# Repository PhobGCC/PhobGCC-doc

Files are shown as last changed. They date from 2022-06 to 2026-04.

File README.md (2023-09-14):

# PhobGCC Documentation Hub
This is a central location for documentation for the PhobGCC.

The PhobGCC is a replacement motherboard for Gamecube controllers that reads stick position using magnets and Hall effect sensors instead of potentiometers that can wear out.
It offers an advanced digital snapback filter that doesn't reduce responsiveness and actually improves responsiveness in Melee.
It also features gate calibration, swappable buttons, and facilitates installation of discrete switches on the D-pad and face buttons.

This comes together to make a high-performance, customizable, long-lasting controller that you can make yourself.

Come chat with us on the [PhobGCC Discord](https://discord.gg/eNJ7xWMvxf)!

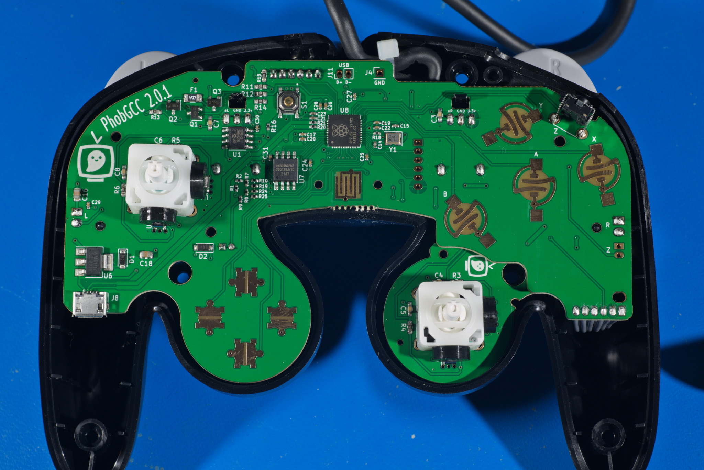
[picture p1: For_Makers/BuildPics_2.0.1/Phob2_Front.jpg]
PhobGCC


## For Buyers and Users

[PhobGCC Buying Guide](/For_Users/Phob_Buying_Guide.md)

[PhobGCC Calibration/Configuration Guide](/For_Users/Phob_Calibration_Guide_Latest.md)

[PhobVision and PhobScope User Guide](/For_Users/Phobvision_Guide_Latest.md)

[PhobGCC v2.0 Firmware Update Guide](/For_Users/Phob2_Programming_Guide.md)

[PhobGCC v1.X Firmware Update Guide](/For_Users/Phob_Programming_Guide.md)

[User guides for Extras](/For_Users/Extras_Guides)

## For Makers and Sellers

[PhobGCC v2.0.5 Parts Ordering Guide](/For_Makers/Phob2_Ordering_Guide.md)

[Build Guide for PhobGCC 2.0](/For_Makers/Build_Guide_2.0.md)

[Build Video for PhobGCC 2.0](https://www.youtube.com/watch?v=hWuvy4ZEgG0)

[Board Fixes for PhobGCC design flaws](/For_Makers/Board_Fixes.md)

[PhobGCC v1.2.3 Parts Ordering Guide](/For_Makers/Phob_Ordering_Guide.md)

[Build Video for PhobGCC 1.2](https://youtu.be/0QmgswFa1cA)

[Build Guide for PhobGCC 1.2](/For_Makers/Build_Guide_1.2.md)

[Board Debugging for PhobGCC 1.2](/For_Makers/Board_Level_Debugging_1.2.md) (read before plugging in the first time!)

[Guide to Programming PhobGCC v2.0](/For_Users/Phob2_Programming_Guide.md)

[Guide to Programming PhobGCC v1.X](/For_Users/Phob_Programming_Guide.md)

## General Info

[Hall Effect Sensor Explanation](/General_Info/Hall_Effect_Sensors.md)

[Signal Linearization](/General_Info/Signal_Linearization.md)

[Snapback Filter](/General_Info/Snapback_Filter.md)

[Notch Remapping](/General_Info/Notch_Remapping.md)

## Legacy Info

[Legacy Documentation Page](/LEGACY.md)


This work is licensed under a [Creative Commons Attribution-ShareAlike 4.0 International License](http://creativecommons.org/licenses/by-sa/4.0/).

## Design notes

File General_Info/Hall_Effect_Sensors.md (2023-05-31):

Hall effect sensors work by measuring how hard moving charges get pushed/pulled by a magnetic field. Read more here: https://en.wikipedia.org/wiki/Hall_effect

We can use this effect by attaching a magnet to the stickbox peg in the correct orientation, and placing a sensor underneath it. When the magnetic field is perpendicular to the sensor's direction of sensitivity, no field is detected and the sensor will output ~1V:

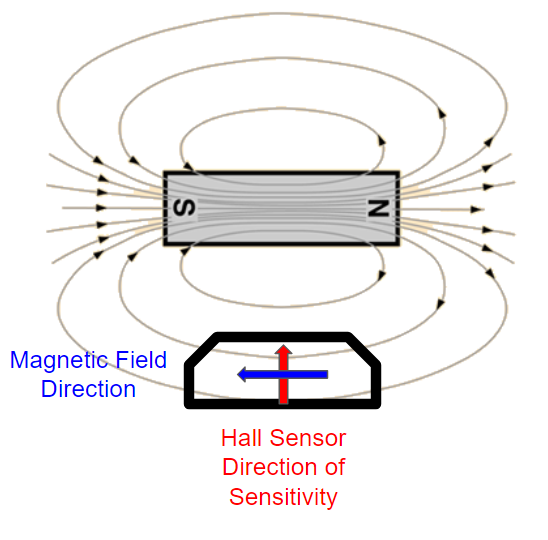
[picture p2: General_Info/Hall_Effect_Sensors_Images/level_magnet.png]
Magnet level


When the field tilts one way, the output voltage will decrease:
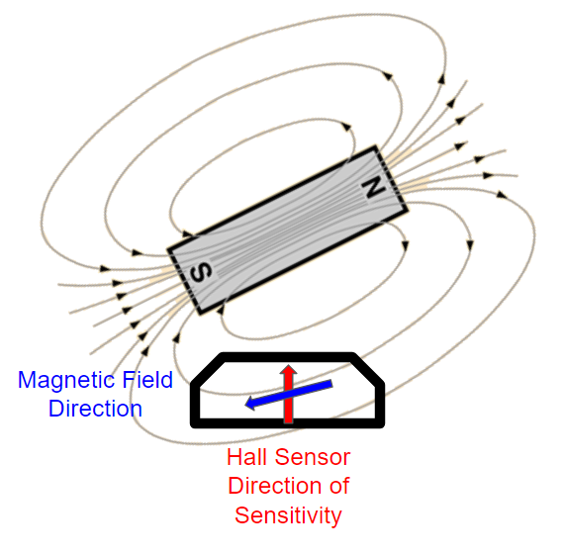
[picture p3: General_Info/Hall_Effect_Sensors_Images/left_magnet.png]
Magnet tilted left


When the field tilts the other way, the output voltage will increase:
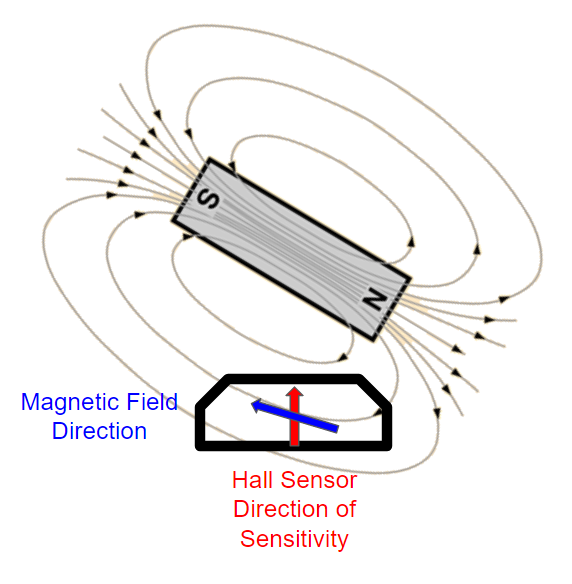
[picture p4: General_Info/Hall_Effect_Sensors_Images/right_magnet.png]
Magnet tilted right


When we glue the magnets on they are not perfectly aligned, so we won't get this perfect behavior, but this is roughly what happens. The microcontroller reads these voltages the same way it does from a potentiometer, but we will need to scale possibly linearize the signal before it can be used to control the stick. The primary advantage is that the Hall effect sensor will not wear out like a potentiometer will. As long as the magnet stays in place it will continue working.


This work is licensed under a [Creative Commons Attribution-ShareAlike 4.0 International License](http://creativecommons.org/licenses/by-sa/4.0/).

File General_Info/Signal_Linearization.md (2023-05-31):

 The signals coming from the Hall effect sensors need to be scaled and are non-linear. In order to make them behave the same way potentiometers we need to linearize them. We do this with a 3rd order polynomial fit.

Imagine we move the stick into the 8 different gate notches and record the x-position at each location. We would expect to get the values -1.0,-0.71,0,0.71, and 1.0, depending on which notch we were in. But with the hall effect sensors we might get something else, we might get -0.63,-0.52,0.0,0.29, and 0.33 for example.

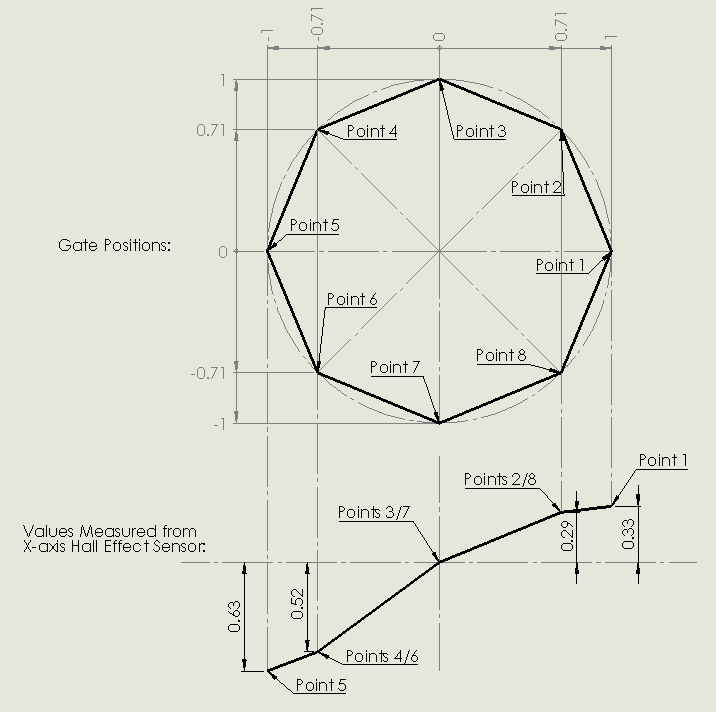
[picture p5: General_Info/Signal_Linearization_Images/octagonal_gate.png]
Octagonal Gate Measured Positions


 But since we know what the values should be, we can find an equation which transforms the values from the hall sensor into the values we want:

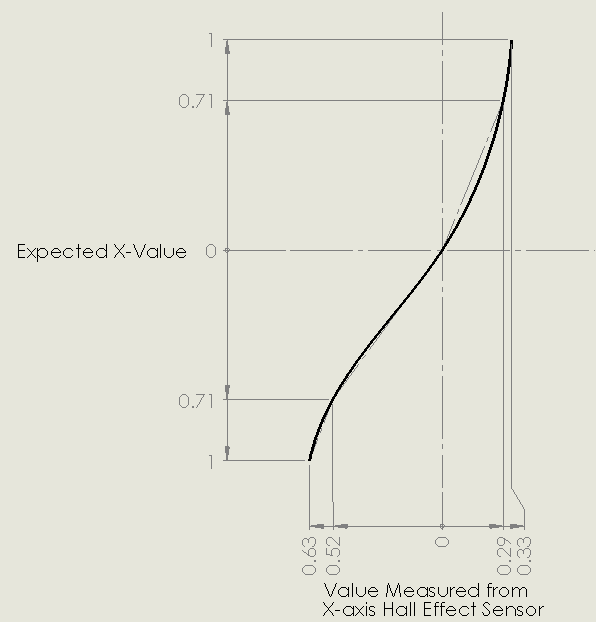
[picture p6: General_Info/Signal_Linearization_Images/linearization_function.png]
Linearization Function


The simplest function that appears to do a reasonable job of fitting the hall effect sensor data has been a 3rd order polynomial of the form Ax^3 + Bx^2 + Cx + D. Using these x-values measured at the gate notches we can find the coefficients A,B,C,D through regression analysis (usually ordinary least squares), then we just substitute the value we got from the sensor into x, and we get the linearized output.


This work is licensed under a [Creative Commons Attribution-ShareAlike 4.0 International License](http://creativecommons.org/licenses/by-sa/4.0/).

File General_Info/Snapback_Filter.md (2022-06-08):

# Kalman-inspired filter for snapback

For a thorough introduction to Kalman filters, check out this website: https://www.kalmanfilter.net/

Kalman filters are a common way to estimate current system state when all you have are noisy measurements. They use a model of the system's behavior to generate a prediction of the current state, and then blend that with measurements, while tracking uncertainty for both the measurements for the model. By choosing the right blend of measurement data and predictions from past data, they can generate estimates that are more accurate than the measurements alone.

In the PhobGCC, the measured stick positions have a slightly noisy signal, but it wouldn't be hard to get a good estimate of the actual stick position. The main issue is removal of unwanted snapback oscillations. Thus, we heavily modify the Kalman filter in order to exclude the measurements when we think the stick is undergoing snapback, and add other changes to improve behavior in other circumstances.

# Filter components

## Current position measurement

When determining the final estimated stick position, we weight the current measured position according to the minimum of the following:

1. To ensure that the stick responds quickly to full stick inputs, the first weight is the radius of the stick position to the 6th power. This stays very close to 0 and then it rises very suddenly near the edge. We can assume that snapback is not currently occurring when the stick is near the rim, because by definition it only occurs when the stick is released.
2. To ensure that the stick responds reasonably quickly to small stick inputs, the second weight is 1 when the stick is not moving or accelerating in that particular axis, and it gradually drops to 0 as the acceleration or velocity reach corresponding thresholds. The assumption here is that problematic amounts of snapback outside the deadzone will always have acceleration or velocity (or both) greater than these thresholds, while small manual stick movements will never be near these thresholds.

These cover both cases: a small input will always be slow compared to snapback, and any input near the rim, even if fast, will never be snapback.

## Prediction of future motion

The prediction based on past motion is weighted to be the complement of the current position measurement's weight.

However, the prediction based on past motion is not actually designed to be as accurate as possible. It's just an estimate of the *desired* velocity.

For one, we reduce the velocity estimate by a damping factor, which is a parameter you can adjust to tame snapback on particularly high-snapback controllers.

Secondly, the velocity estimate is itself a heavily filtered rendition of the current velocity.

* The current velocity is weighted according to the radius of the stick position squared, so that it is mostly ignored near the center (though less so than the stick position weight).
* The previous filtered velocity is weighted according to the complement of the current velocity's weight, but it has an additional decay factor to help prevent unwanted slow overshoots when returning to center.
* The disagreement between the previous measured stick position and the previous filtered stick position is lightly weighted into the filtered velocity in order to help improve responsiveness but not enough to cause overshooting.

# Results

For smash inputs, the PhobGCC analog stick filter ignores the initial part of the stick travel due to high speed/acceleration and not being near the gate, and then it "catches up". This results in a very short time interval where the filtered stick position is in the tilt region, which helps with the reliability of dashbacks, pivots, and wiggle out of tumble.

For small tilt outputs, the stick is still very responsive because humanly possible stick inputs can't approach the incredible speeds or accelerations characteristic of snapback. By closely following the stick when it is moving slowly, the PhobGCC maintains responsiveness for small inputs, which is useful for fast tilts, turnarounds, and slight DI.

Finally, when the stick is released, the high velocity and acceleration of the stick snapback cause the filter to drastically decrease the weight of the current stick position, allowing it to effectively ignore the oscillation and dampen the overshoot.

Thanks to this combination of characteristics, the PhobGCC analog stick filter achieves excellent responsiveness for *Melee* while taming snapback.

If you want to peruse the actual code for the filter, it is well-commented [here](https://github.com/PhobGCC/PhobGCC-SW/blob/843ff59011ab0bced795b43427e81f2a1a8c55f1/PhobGCC/PhobGCC.ino#L2636).


This work is licensed under a [Creative Commons Attribution-ShareAlike 4.0 International License](http://creativecommons.org/licenses/by-sa/4.0/).

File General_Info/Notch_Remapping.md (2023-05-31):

Notch remapping is done by dividing stick space into triangular shaped regions, then applying an affine transformation(https://brilliant.org/wiki/affine-transformations/) to each triangular shaped region to match up the corners of each region with the desired notches:

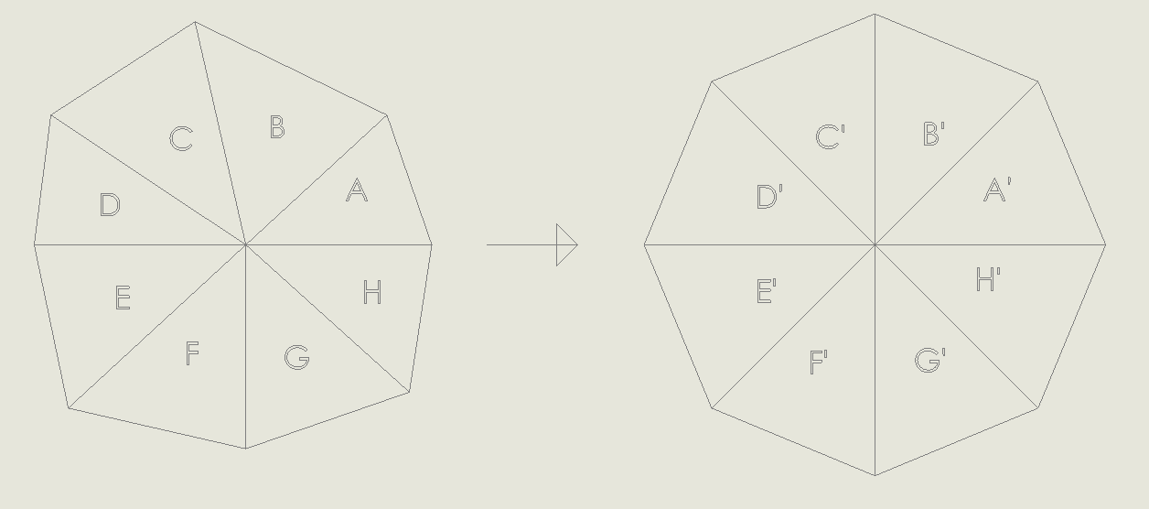
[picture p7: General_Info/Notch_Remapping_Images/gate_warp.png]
Remap


Region A gets transformed into region A', B into B', etc. This illustration is exaggerated to show how things work, the actual notch positions are not this far off. In this way things can be stretched so that when the stick is in the physical notch, it gives the correct coordinates.


This work is licensed under a [Creative Commons Attribution-ShareAlike 4.0 International License](http://creativecommons.org/licenses/by-sa/4.0/).

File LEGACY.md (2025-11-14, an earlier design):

# Legacy Documentation

This document is to keep track of old documentation that is no longer applicable.

## Controller Configuration

* [For Version 0.29](/For_Users/Phob_Calibration_Guide_v0.29.md)
* [For Version 0.28](/For_Users/Phob_Calibration_Guide_v0.28.md)
* [For Version 0.27](/For_Users/Phob_Calibration_Guide_v0.27.md)
* [For Version 0.26](/For_Users/Phob_Calibration_Guide_v0.26.md)
* [For Version 0.25](/For_Users/Phob_Calibration_Guide_v0.25.md)
* [For Version 0.24](/For_Users/Phob_Calibration_Guide_v0.24.md)
* [For Version 0.23](/For_Users/Phob_Calibration_Guide_v0.23.md)
* [For Version 0.22](/For_Users/Phob_Calibration_Guide_v0.22.md)
* [For Version 0.21](/For_Users/Phob_Calibration_Guide_v0.21.md)
* [For Version 0.20](/For_Users/Phob_Calibration_Guide_v0.20.md)
* [For Version 0.18-0.19](https://docs.google.com/document/d/1tICHkeWHWOi87ebddIgM1hSR2AaJqE-wSA17Wzhi0u0/edit?usp=sharing)
* [For Version 0.16-0.17](https://docs.google.com/document/d/11UUmMImXMPYMJ9wzESQMvJrMNCCeWAxyutiNewseW9k/edit?usp=sharing)

## Ordering Guides

* [Board Version 1.1](https://docs.google.com/presentation/d/1JxY79lkCj4QdBnbAxH9PvyXZGDKAvMpFpukHwAc2s3c/edit?usp=sharing)

## Build Guides

* [Board Version 1.1](https://docs.google.com/presentation/d/1Awil69v7xDhX-VOdLnVhseILLCY89gFpTTAPPEig6E4/edit?usp=sharing)

## Programming Guides

* [For Arduino 1.8.X](https://docs.google.com/presentation/d/1Ota8R95K1-LR34Re3XB7BIb7ZzgtDM_iaknYH9k8yRQ/edit#slide=id.p)


This work is licensed under a [Creative Commons Attribution-ShareAlike 4.0 International License](http://creativecommons.org/licenses/by-sa/4.0/).

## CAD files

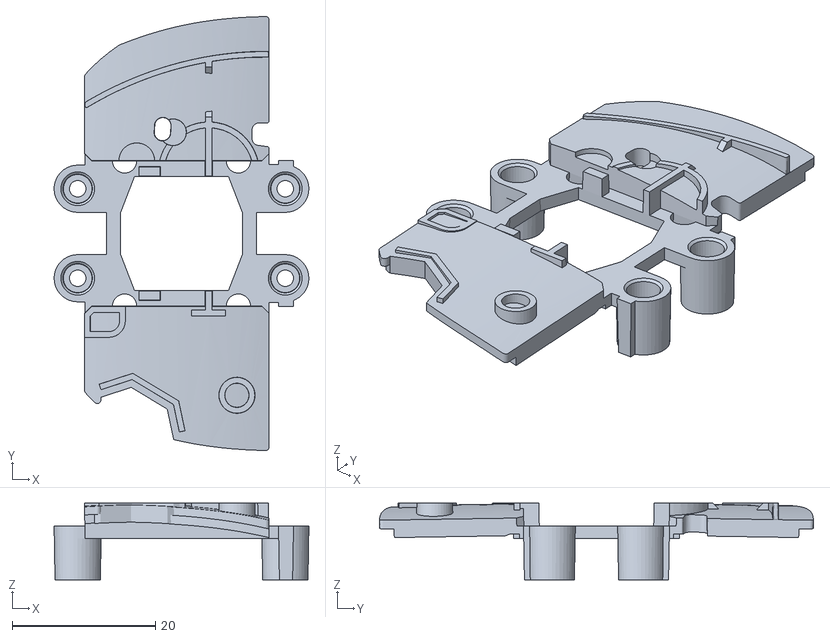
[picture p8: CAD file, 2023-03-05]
For_Makers/1.X Trigger Guards.STL
35.6 x 60.6 x 10.7

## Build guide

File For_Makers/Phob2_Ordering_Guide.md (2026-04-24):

# PhobGCC Version 2.0.5 Ordering Guide

This is an illustrated guide to acquiring all the parts you need to assemble a PhobGCC v2.0.5.

# Required Parts

The following parts are unique to the PhobGCC and must be acquired per this guide, with no non-identical substitutions.

* 1x PhobGCC v2.0.5 Board
* 4x Magnets
* 4x Underslung Magnet Mounts
* 6x Wires
* Optional: 4x D-pad Buttons
* Optional: 1-6x Mouse Buttons for ABXYLR
* Optional for [PhobVision](https://youtu.be/8OOGupE3-ic):
  * Panel-mount 3.5mm TRRS Jack
  * JST-PH 2.0 2-pin male connector & female pigtail
  * TRRS to RCA video adapter cable (doesn't go in the controller but required for use)

The following parts are standard to a GCC and can be acquired via a number of different ways, some of which will be outlined here.

* 2x T3 Stickboxes
* 2x Trigger Potentiometers
* 2x Trigger Paddles
* 1x Cable with a GCC Plug
* 1x Rumble Bracket
* 1x Z-button Switch
* Optional: 1x Rumble Motor

There are two main ways to acquire a PhobGCC v2.0.5 Board.
The first way is if you intend to only build a single controller, you can contact a local modder in your region using [this map](https://www.nojonsmods.com/moddermap) to see if they have spare for sale.
Alternatively, you can also check [Etsy](https://www.etsy.com/) or [eBay](https://www.ebay.com/) as some often appear for sale.
If you cannot find a single board for sale or you intend to build more than one PhobGCC, you can order the boards directly from a board house.
These instructions will be for [JLCPCB](https://jlcpcb.com/) and [Elecrow](https://www.elecrow.com/).

## Parts You Don't Need

Don't acquire these, because they're not necessary or won't work with PhobGCC 2.0.5 at all:

* Snapback capacitors, snapback modules: snapback is corrected in software.
* Heartbeat modules or equivalent shunt resistors: we have no stick potentiometers so these are unnecessary.
* Teensy or Raspberry Pi Pico: the PhobGCC 2 has no need of any external microcontroller board.
* OEM C-Stick ribbon cables from a GCC: PhobGCC 2 needs 6 connections to the C-Stick daughterboard, and reusing the OEM cable has been a source of reliability issues.
* Hall Sensors: these are built into the PhobGCC board.
* Hall Effect Stickboxes: the PhobGCC uses magnets that you attach to a standard Gamecube controller stickbox.

## Purchasing the PhobGCC v2.0.5 board

If you have a GCC modder in your area, consider buying a board from them.

Otherwise, you can purchase premade boards directly from [Elecrow](https://www.elecrow.com/phobgcc-v2-gamecube-controller-motherboard.html), which stocks 4 common colors at very reasonable prices.

If you plan on ordering around 50 boards or more, or if you want more unusual colors, you should submit a traditional PCB order by following the [Elecrow Ordering Guide](/For_Makers/Phob2_Elecrow_Ordering_Guide.md).

Warning to US residents: ordering from Chinese board houses at this point is likely to result in heavy tariffs.

## Optional: Purchasing LR Trigger Paddles

If you don't or can't use OEM GCC Trigger paddles, you can order trigger paddles separately.

First, you can download the files available in the [PhobGCCv2-HW Github](https://github.com/PhobGCC/PhobGCCv2-HW/releases/tag/v2.0.5) in the releases section as shown below:

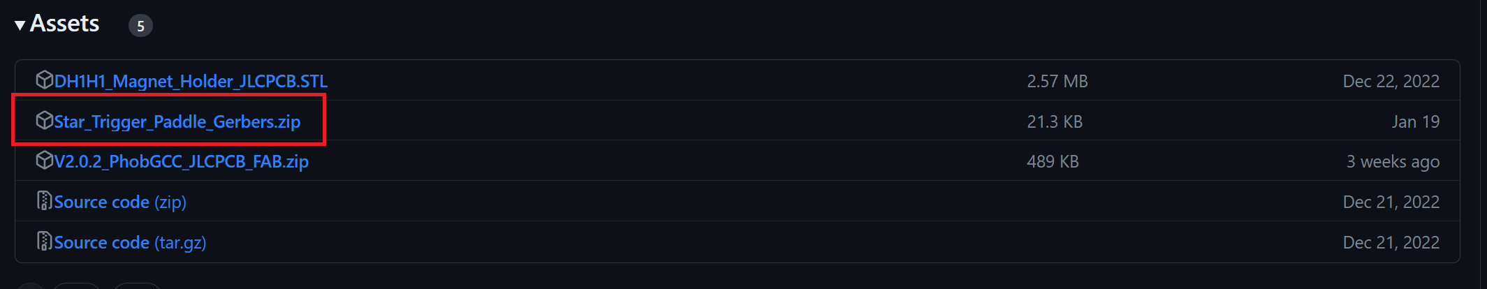
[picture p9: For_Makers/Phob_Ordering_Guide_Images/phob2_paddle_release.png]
PHOB2_PADDLE_RELEASE


Click "Order Now" on JLCPCB, make sure you are set to "Standard PCB/PCBA" tab, click "Add Gerber File", and upload the Trigger_Paddle_Gerbers.zip. Once the files are uploaded, you should see the board process and then load in as shown below:

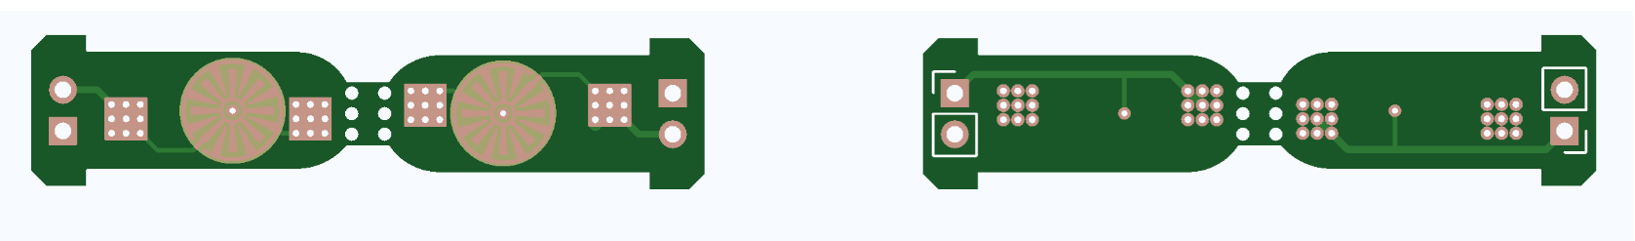
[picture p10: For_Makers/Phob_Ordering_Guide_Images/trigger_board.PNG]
TRIGGER_BOARD


Once you've checked that the size is set to 9.7x41.72mm, you can progress with configuring it.
The recommended settings are the defaults, setting your board quantity, setting "Different Design" to 2, and setting the Surface Finish to ENIG, as seen below:

**NOTE: IF YOU ORDER MORE THAN 30, THE OPTION FOR DEBURRING/EDGE-ROUNDING APPEARS. IT'S RECOMMENDED TO ENABLE IT!**

**NOTE2: SINCE THESE BOARDS ARE SO SMALL, THE QUANTITY DOESN'T CHANGE THE PRICE. WE SUGGEST ORDERING PLENTY SINCE ITS CHEAP. THE DIFFERENCE BETWEEN 20 AND 200 IS $18.**

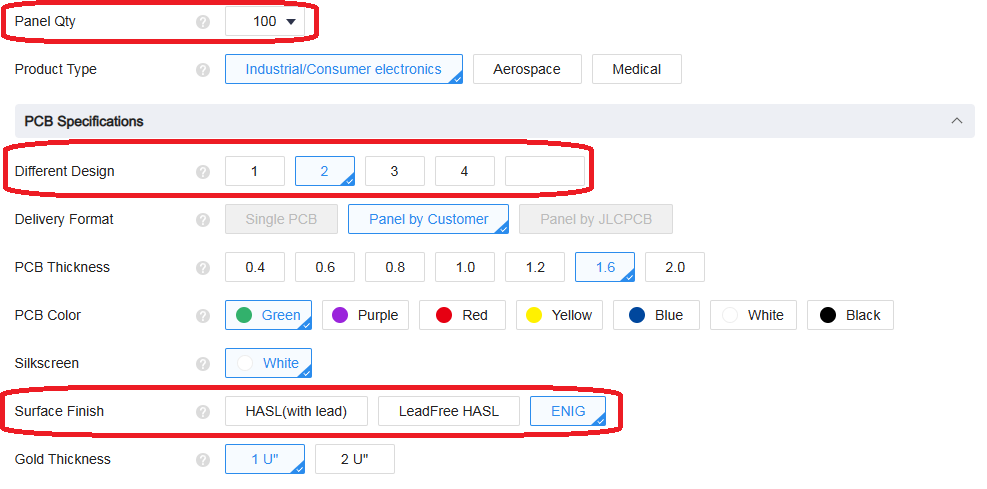
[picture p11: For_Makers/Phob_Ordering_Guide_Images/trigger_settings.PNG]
TRIGGER_SETTINGS


You can then click "Save To Cart" and pay for your boards.

# Optional: Purchasing DH1H1 Magnet Mounts

If you can't source magnet mounts locally or via [Etsy](https://www.etsy.com/), you can order them from JLCPCB.

**DO NOT USE THESE WITH MAGNETS OTHER THAN DH1H1.**

First, you can download the files available in the [PhobGCCv2-HW Github](https://github.com/PhobGCC/PhobGCCv2-HW/releases/tag/v2.0.5) in the releases section as shown below:

PHOB2_MAGNET_RELEASE

Click "Order Now" on JLCPCB, make sure you are set to "3D Printing" tab, click "Add 3D Files", and upload the DH1H1_Magnet_Holder_JLCPCB.STL. Once the file is uploaded, you should see it render as shown below:

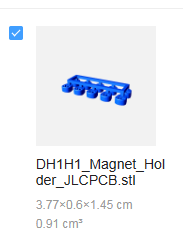
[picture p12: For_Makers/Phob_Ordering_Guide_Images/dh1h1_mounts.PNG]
MAGNET_MOUNTS


The recommended settings are SLS Nylon. You then set the product description to Other -> Fastener as shown below

**NOTE: QUANTITY 1 GETS YOU 10 MOUNTS, WHICH IS ENOUGH FOR 2.5 PHOBS. 2 GETS YOU 20 MOUNTS FOR 5 PHOBS. MAKE SURE YOU ORDER ENOUGH!**

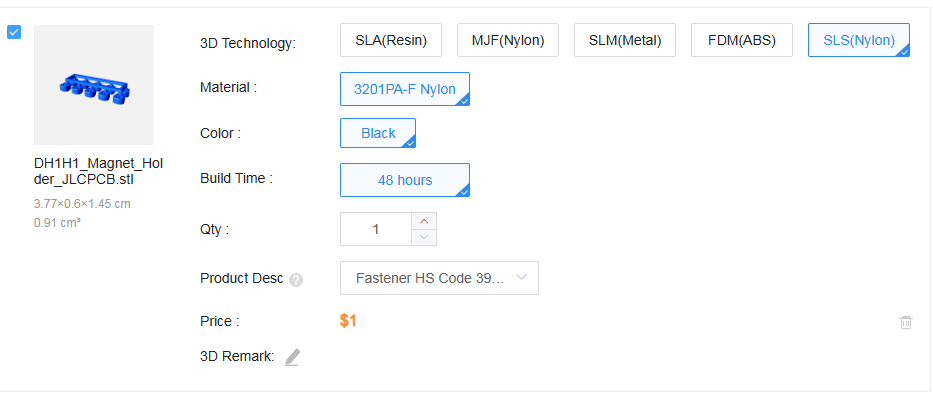
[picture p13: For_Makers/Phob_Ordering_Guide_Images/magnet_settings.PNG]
MAGNET_SETTINGS


You can then click "Save To Cart" and pay for your mounts.

**NOTE: If you get asked about wall thickness, click "Yes" and confirm. It's okay**

# Purchasing Other PhobGCC Parts

The remaining parts can be purchased from distributors as listed below.
* Magnets: choose one type and stick with it.
  * [DH1H1 Magnets](https://www.kjmagnetics.com/proddetail.asp?prod=DH1H1)
  * [DH1H1-like option](https://totalelement.com/products/1-10-x-1-10-inch-neodymium-rare-earth-cylinder-rod-magnets-n52-300-pack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)
  * [D12 Magnets](https://www.kjmagnetics.com/proddetail.asp?prod=d12-n52)
  * [N30H Magnets](https://www.digikey.com/short/br3n8hz3)
  * [Canadian DH1H1-like option](https://www.indigoinstruments.com/magnets/rare_earth/discs/small-neodymium-cylinder-magnet-2.5x2.5mm.html)
  * [EU N30h-like option](https://www.supermagnete.de/eng/disc-magnets-neodymium?length-or-diameter=2.00,3.00&height=2.00,3.00)
  * [Australian DH1H1-like option](https://magnet.com.au/products/neodymium-cylinder-magnet-2-5mm-x-2-5mm-n50?variant=37006192804005)
* Magnet Mounts:
  * **NOTE: PhobGCC v1.X MAGNET MOUNTS WILL BE VERY BAD, AND MAY NOT WORK AT ALL. MAKE SURE TO GET THE UNDERSLUNG MAGNET MOUNTS!**
  * Download [This](https://drive.google.com/file/d/10-lseJ4UK1-HkkXc6rjSJtsYRW7ihsXD/view?usp=share_link) OpenScad file. It is by default set up for DH1H1 Magnets, so you can edit it for whatever magnet you use, adjust it for your printer, and then generate the STL using [OpenScad](https://openscad.org/). Once you have the STL, you can print it using your own machine or check out local makerspaces, libraries, and print shops.
  * If you use magnets other than DH1H1, you will need to adjust the magnet offset to get the optimum signal strength using PhobVision to check. Speak with the devs on Discord to find out more.
* Wire for C-Stick (choose one):
  * 26-gauge stranded wire such as [this from McMaster](https://mcmaster.com/8054T11).
  * 6-pin Ribbon Cable from [Kadano](https://kadano.biz/phobgcc-2-0-c-stick-ribbon-cables-6pin/) (EU)
  * 6-pin Ribbon Cable from [Tbox](https://www.etsy.com/listing/1479077608/phob-202-6-pin-c-stick-ribbon-cables) (NA)
* Optional Mouse Buttons for ABXYLR: you can use mouse buttons for any number from 0 to 6 of the buttons. Generally the high actuation force buttons are preferred.
  * [Low Actuation Force Buttons](https://www.digikey.com/short/nfphr274)
  * [High Actuation Force Buttons](https://www.digikey.com/short/f7mctdjm)
  * [Teflon Tape For Support](https://www.mcmaster.com/76475A51/) This is necessary for mouseclick face buttons, but there are alternatives.
* Optional Discrete Buttons for D-Pad:
  * [Tactile SMD Buttons](https://www.digikey.com/short/7pw830cj)
  * [~~SMD Buttons~~](https://www.digikey.com/short/v93wrw12)
* Optional for [PhobVision](https://youtu.be/8OOGupE3-ic): you need all of these if you choose to install PhobVision.
  * [TRRS Jack](https://www.digikey.com/en/products/detail/cui-devices/SJ5-43502PM/1956558)
  * [JST-PH 2.0 2-Pin Connector and Pigtail](https://www.amazon.com/dp/B01DUC1O68) or similar: size is critical; don't use a double pigtail.
  * [TRRS to RCA Video Cable](https://www.amazon.com/dp/B08V1SV8BL) or similar: **MUST BE TRRS = Audio Left, Video, Ground, Audio Right**

# Purchasing Other GCC Parts

The GCC-specific Parts have a few different methods of acquisition
* Stickboxes
  * T3 GCCs as per [this guide](https://gccontrollerlibrary.com/guides/gamecube-controller-stamps-guide/)
  * Official Wii Classic and Wii Classic Pro Controllers
  * Sold Loose on [Etsy](https://www.etsy.com/)
* Trigger Potentiometers
  * Any GCC
  * Official Wii Classic Controllers (No Handles)
  * [Kadano's Etsy Store](https://www.etsy.com/listing/1361667533/new-gamecube-controller-potentiometers)
* Cable with a GCC Plug
  * Any GCC
  * Alibaba Cables
  * [Liquid Cable](https://firescc.com/diy-custom-cables)
* Rumble Bracket
  * Any GCC
  * [Wumble](https://github.com/wavtype/wumble)
  * [FIRESCC](https://firescc.com/mod-guides#/rumble-bracket)
  * [Ube-S-Phob](https://github.com/Flocloud9/Ube-s-Phob-Bracket)
* Z-button Switch
  * Stock - Any GCC
  * Tactile - Official Wii Classic Controllers (No Handles)
  * Heavy Tactile - [BattleBeaverCustoms](https://battlebeavercustoms.com/products/replacement-gamecube-tactile-z-switch)
  * Tactile - [FIRESCC](https://www.etsy.com/listing/753452766/fires-performance-mod-kit-for-the?)
  * Tactile - [Digikey](https://www.digikey.com/short/hp5vvv7w) **NOTE:  NEEDS SOME MODIFICATION OF CONTROLLER BUTTON RUBBER**
  * Mouseclick - [BibbEZ](/For_Makers/BibbEZ/BibbEZ_Guide.md)
* Optional Rumble Motor
  * Any GCC
  * [Cellphone Rumble](https://www.amazon.com/10-Pieces-Vibration-Motor-Vibrating/dp/B00N9J3BTG)

# Assembly

Once you have all the parts you need, follow the [build guide](/For_Makers/Build_Guide_2.0.md) to assemble your PhobGCC.

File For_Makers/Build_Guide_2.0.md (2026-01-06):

# PhobGCC 2.0 Build Guide

This is an illustrated guide to making a PhobGCC 2.0, using photos taken of a PhobGCC board version 2.0.1.

Newer board versions may differ slightly in appearance but this guide will still be applicable.

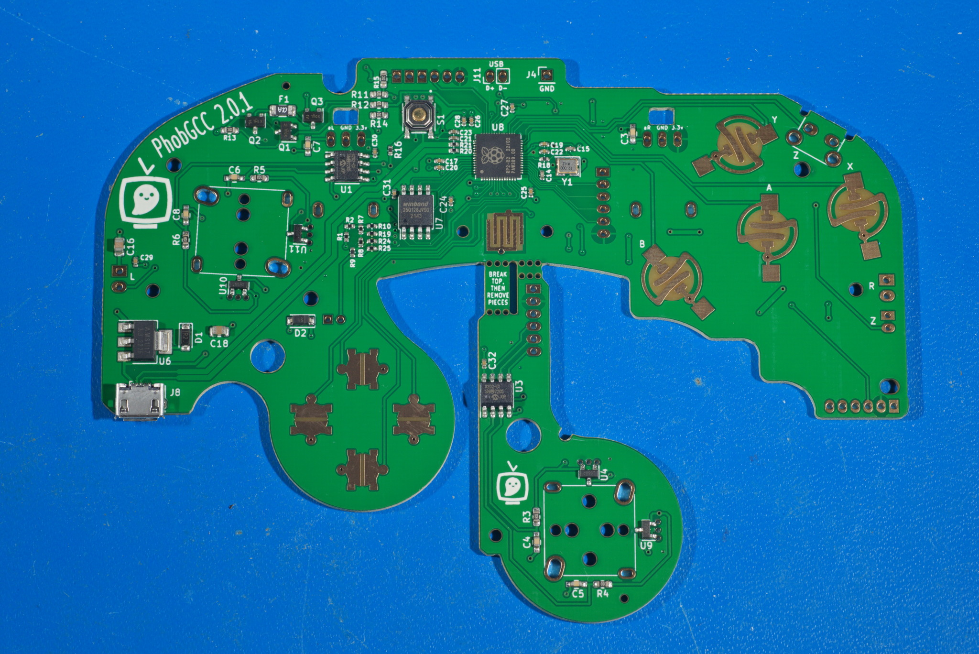
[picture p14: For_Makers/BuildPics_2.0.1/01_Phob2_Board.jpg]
Motherboard Overview


If you want to see it in motion, watch the [PhobGCC 2.0 Assembly Video](https://www.youtube.com/watch?v=hWuvy4ZEgG0).

Unlike previous releases, PhobGCC v2.0 is much more beginner friendly and if you follow the instructions precisely it is possible to build a PhobGCC as your very first soldering project.

It is still recommended to get a soldering practice kit to build your physical understanding of the soldering process with before you start.

And make sure to follow **every single step** without fail, because there's many ways to make the controller nonfunctional.

# Tools

It's possible to work with cheap tools and supplies if you're very skilled.

But if you cheap out on solder or soldering iron "because you're just a beginner" you will be in for a lot of pain and suffering.

Come to the [PhobGCC Discord Server](https://discord.gg/yrpUu7mgzm) for advice on what to get if you're at all unsure.

## Required Tools

1. Temperature-controlled soldering iron with a moderate size chisel tip. DO NOT USE AN UNCONTROLLED TEMPERATURE IRON!
2. Flux-core solder, ideally no-clean flux (Sn63Pb37 melts at a lower temperature, SAC305 is nontoxic and flows better)
3. No-clean rosin flux paste (not to be confused with solder paste)
4. Tri-Wing screwdriver and small JIS driver set (Phillips drivers can strip screws)
5. Sharp tweezers
6. Solder sucker (or more sophisticated desoldering tool)
7. Vise or PCB support (the alligator clip kind is not very useful)
8. Multimeter for debugging
9. 90%+ rubbing alcohol and cotton swabs

## Suggested Tools

1. Anti-static mat/grounding strap
2. Fume fan

# Parts

Some of the parts are taken from a donor Gamecube controller, while others must be sourced new. Check the [PhobGCC Ordering Guide](/For_Makers/Phob2_Ordering_Guide.md) for a list of what you need to purchase.

## New Parts

1. PhobGCC v2.0.0 board (includes C-stick board)
2. 4x magnets
3. 3D-printed magnet holders and superglue
4. Optional 2x trigger paddles
5. Optional 4x D-pad buttons
6. Optional 4x mouse buttons for ABXY (assembly not depicted)
7. Optional 1x or 2x mouse buttons for triggers (assembly not depicted)
8. Wire 

## Internal Parts Harvested from Donor GCC

Not counting the shell, buttons, stick caps, etc.

1. 2x Stickboxes
2. 2x Trigger potentiometers
3. Cable (or make or buy your own)
4. Rumble Motor (or use a cellphone rumble)
5. Rumble Bracket (or source your own 3D-printed one)
6. Z-button switch
7. Optional trigger paddles with attached wires

# Build Process

## GCC Part Harvesting

[Video Guide](https://www.youtube.com/watch?v=hWuvy4ZEgG0&t=17s)

Begin by taking apart the donor GCC using a Tri-Wing screwdriver.

Remove the motherboard.

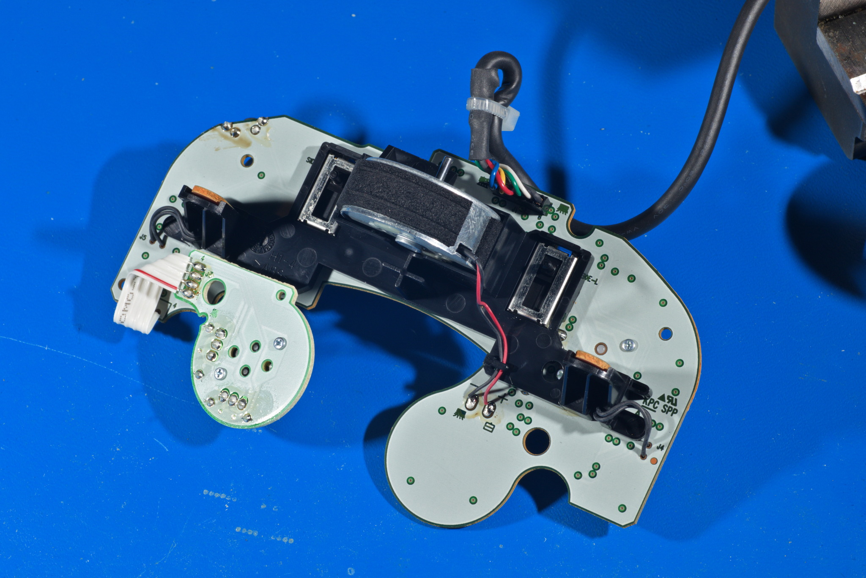
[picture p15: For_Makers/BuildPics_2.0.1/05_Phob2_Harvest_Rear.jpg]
Donor motherboard


You will want to remove the following parts from it:

1. Z button (or supply your own alternate as shown)
2. Trigger paddles (or use PhobGCC ones as alternates as shown)
3. Trigger potentiometers
4. Stickboxes (preferably T3)
5. Rumble bracket (or supply your own 3D-printed one)
6. GCC cable (or supply your own)
7. Rumble motor (or omit it, or use a cell rumble)
8. Stick caps

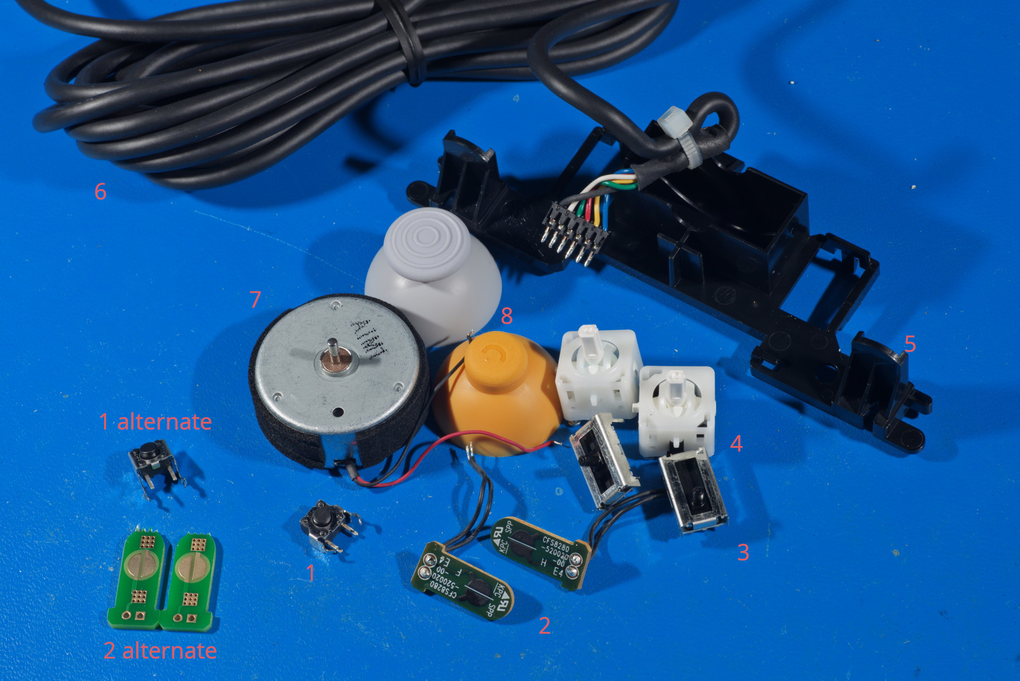
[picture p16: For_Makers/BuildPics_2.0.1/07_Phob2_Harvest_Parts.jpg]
Parts harvested


If you're not familiar with removing the stickboxes, you can stick the points of tweezers between the stickbox and the potentiometers to unclip the potentiometers.
Then, use a JIS #0 screwdriver to unscrew the screws from the bottom of the stickboxes.

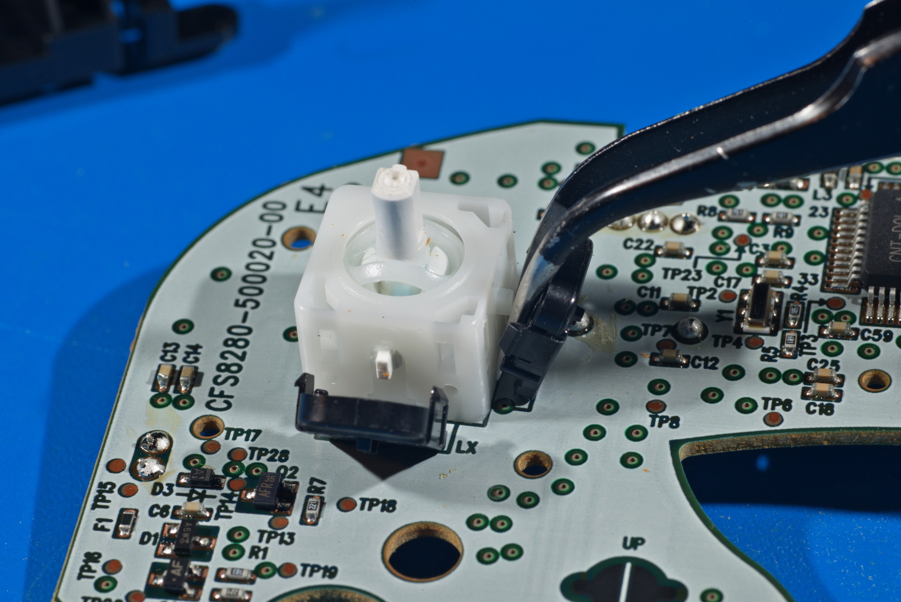
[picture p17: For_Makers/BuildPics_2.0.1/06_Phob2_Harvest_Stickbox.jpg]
Potentiometer unclipping


# Critical Step: Magnet Mounting

[Video Guide](https://www.youtube.com/watch?v=hWuvy4ZEgG0&t=550s)

PhobGCC 2 uses sensors mounted perfectly flat on the board, which was not recommended for PhobGCC 1.
If you were to glue magnets to the peg or use centered magnet holders designed for PhobGCC 1, the signal would be much too weak and the nonlinearities would be undesirable.

Therefore, for PhobGCC 2.0 we are making 3D-printed magnet holders mandatory.
You can get an adjustable parametric OpenSCAD file in the pins of the 3d-printing channel on the discord, or you can get magnet holder STLs designed for use with JLCPCB in the PhobGCC 2 hardware releases.

When using 3D-printed magnet holders, we strongly urge you to superglue (cyanoacrylate) the holders to the stickbox pegs.
It's easiest to do this early in the process so that the superglue cures sufficiently before you need to install the stickboxes.

First, clean the grease off the stickbox pegs with isopropyl alcohol and wipe off the alcohol.
Do not allow it to evaporate on its own, or it will simply redeposit the grease back down.

Then, I prefer to scratch up the pegs using a steel pick or a razor blade.
This exposes clean, fresh plastic for gluing to.

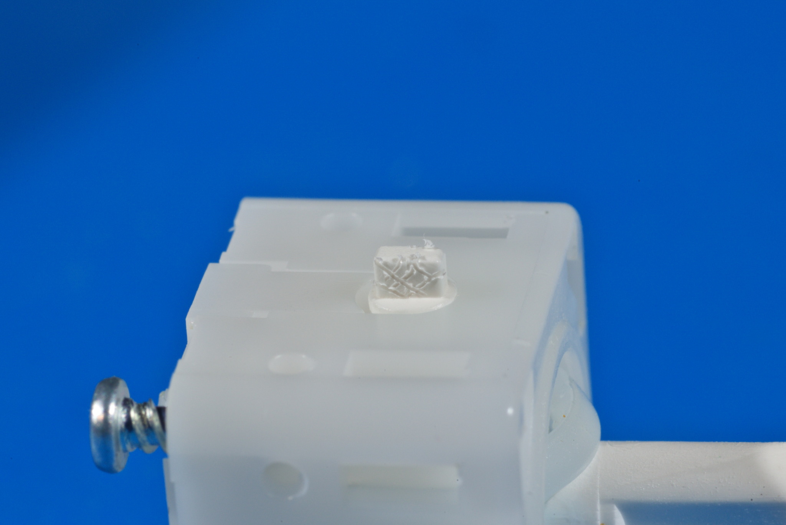
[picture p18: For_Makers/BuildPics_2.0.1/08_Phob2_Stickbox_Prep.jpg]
Scratch stickbox pegs


**Do not apply superglue to the pegs!**

Press-fit the magnet holders over the pegs, making sure that the hole for the magnets is offset downward.

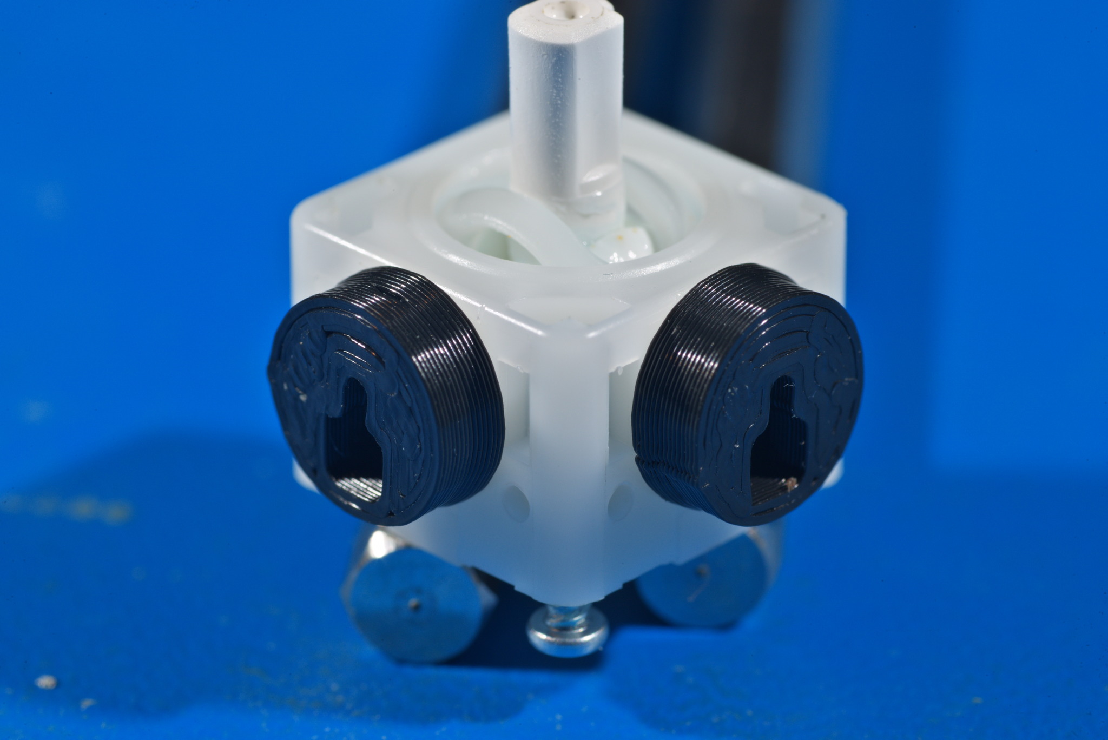
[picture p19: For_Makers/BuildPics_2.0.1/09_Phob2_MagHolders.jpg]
Stickbox with magnet holders


The ideal offset may vary with different magnets, and different magnet/offset combinations may result in slightly different stick behavior.

Coat the inside of the magnet hole, and the top of the peg, with superglue.
I prefer thin superglue.

**Be *very sparing* with superglue so you do not contaminate the stickbox!**

Make sure the magnet holders are able to rotate as you move the stick. **If they are stuck, break them loose by grabbing the magnet mount, not by forcing the stick.**

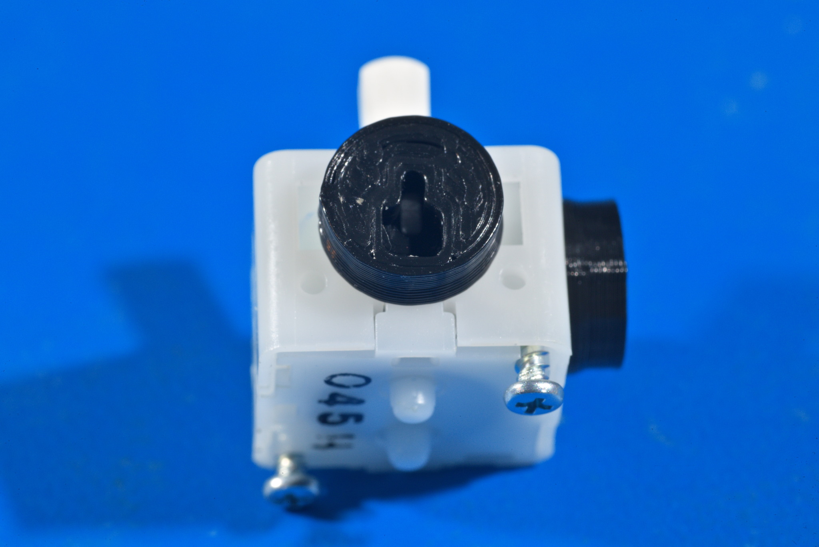
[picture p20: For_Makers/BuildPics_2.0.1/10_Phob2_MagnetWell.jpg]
Stickbox with magnet holders


Insert magnets into the magnet wells, making sure that the magnets are all oriented horizontally.

**If the magnets are not horizontal then the stick will not function.**

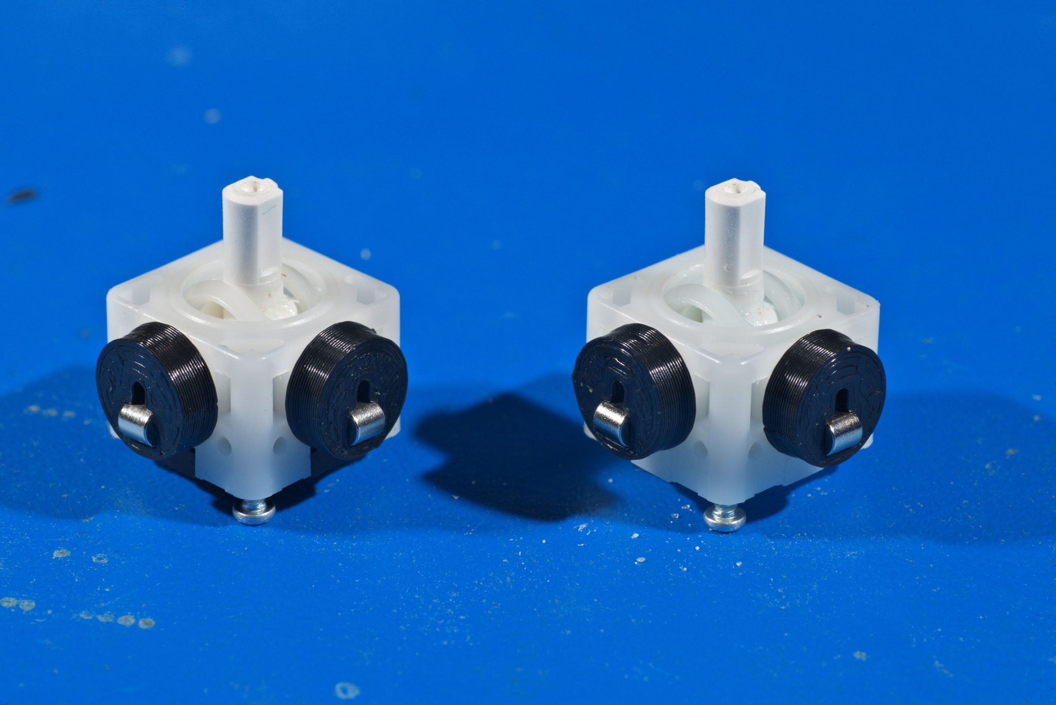
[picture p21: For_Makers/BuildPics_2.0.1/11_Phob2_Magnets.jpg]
Stickbox with magnets


If you wish, you can add extra superglue on top of the magnets to ensure they are securely held in place, though this is not absolutely necessary.

Set the stickboxes aside to cure.

## Stuck Trigger Prevention

[Video Guide](https://www.youtube.com/watch?v=hWuvy4ZEgG0&t=2349s)

This is an optional but simple and highly recommended step to improve the reliability of GCC triggers.

First, use a JIS #1 screwdriver to unscrew these four screws from the backshell of the donor GCC.
If you attempt to use a Phillips screwdriver, you are *extremely* likely to damage the screw heads by camming out.
Please use a JIS screwdriver so that any future modders working on the controller will have an easier time removing them.

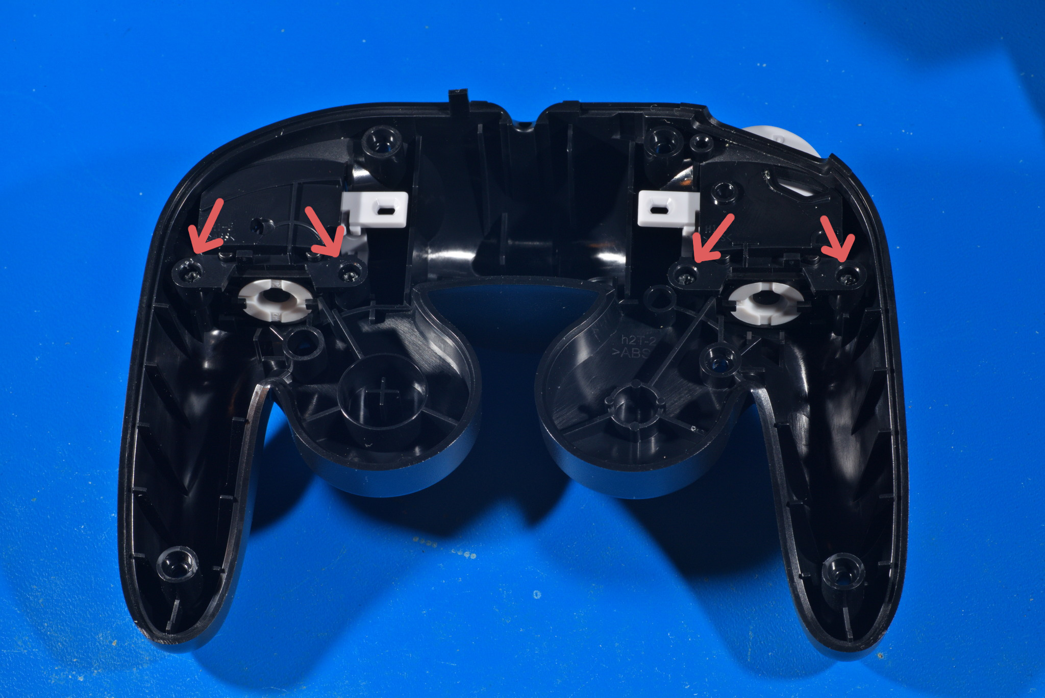
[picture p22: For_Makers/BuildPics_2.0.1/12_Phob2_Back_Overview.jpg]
Trigger screws to remove


Remove the plate above each trigger and the trigger components, and find this protruding corner on each side.

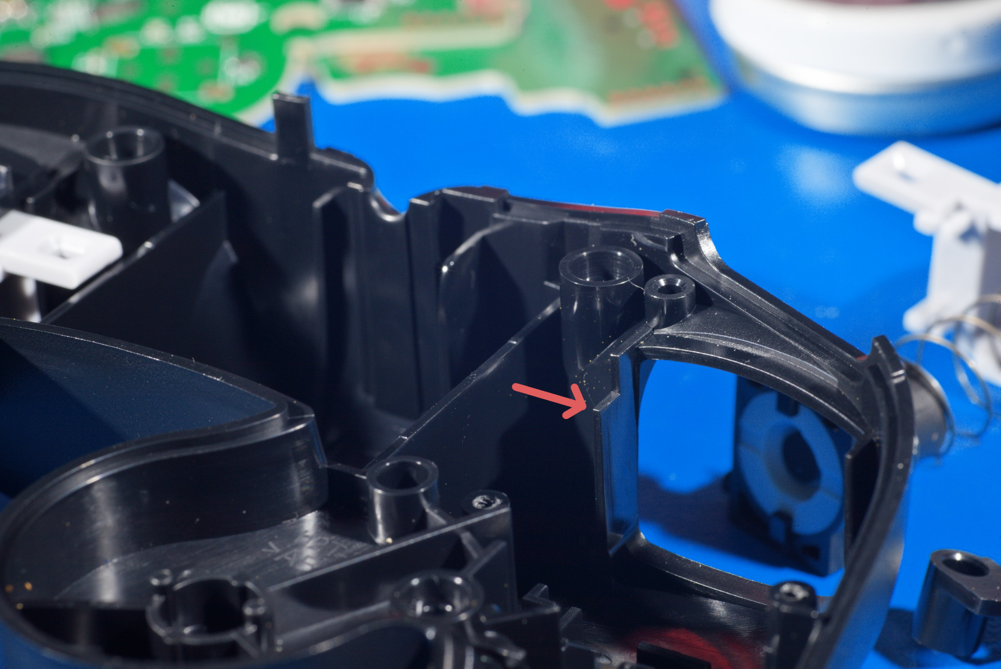
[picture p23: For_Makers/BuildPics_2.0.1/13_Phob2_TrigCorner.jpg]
Trigger corner


Using your flush cutters, remove about 1mm of height from the top of this corner.

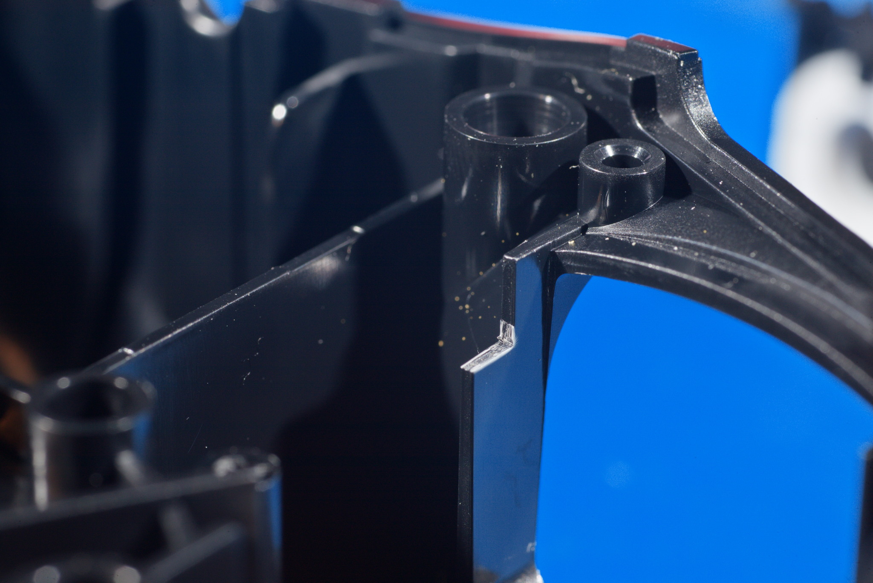
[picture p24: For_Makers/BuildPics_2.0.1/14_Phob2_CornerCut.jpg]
Trigger corner trimmed


This ensures that the tab on the trigger that moves the trigger potentiometer does not get caught on that corner.

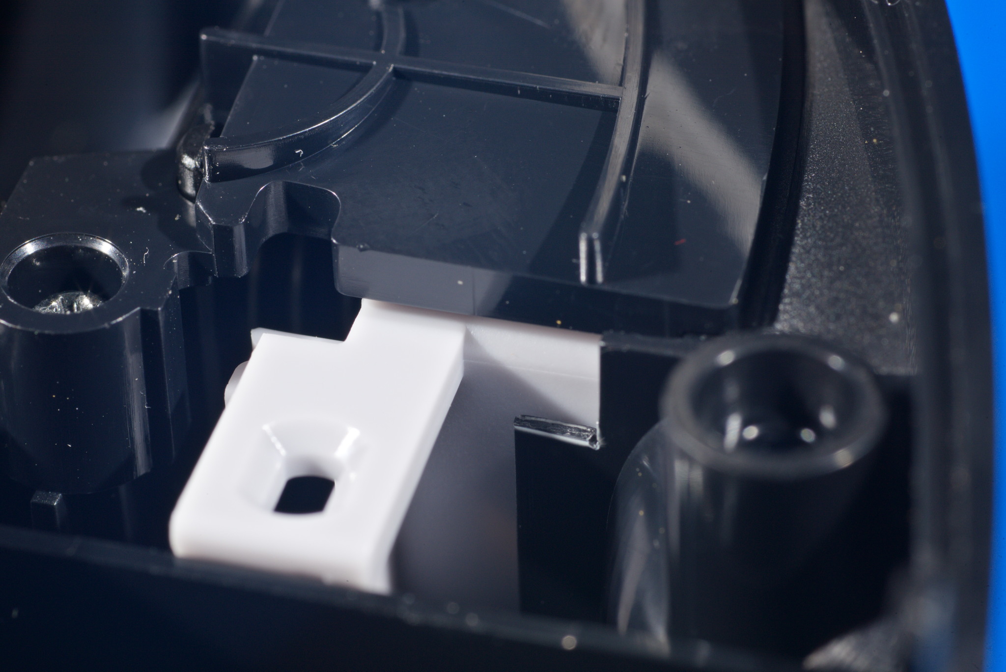
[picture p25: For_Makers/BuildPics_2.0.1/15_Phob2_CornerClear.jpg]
Trigger corner clearance


## Soldering Interlude

Many people attempting to build PhobGCCs are new or relatively novice solderers.
In this section I outline the basic processes and techniques involved in soldering in the hopes of making the process go more smoothly.

Soldering is basically applying fancy conductive hot glue to the surfaces, with some important differences.
The first difference is that the parts that are getting soldered together must be very hot in order for the solder to stick.
Additionally, the parts that are being soldered are usually damaged by too much heat, or heat applied for too long.
Finally, the oxidation on the surface of the metal must be stripped off somehow.

These must all be considered together in order to successfully solder.

### Heating
First, in order to properly heat the joint, you need to heat the joint to above the melting temperature of the solder.
This involves a few considerations.

First is the melting temperature of the solder, which you use to determine the iron temperature.

* Leaded Sn63Pb37 solder melts at 183C/361F, and is usually soldered with the iron at **315-340C/600-650F**.
* Lead-free SAC305 (Sn 96.5%, Ag 3%, Cu 0.5%) solder melts at a higher temperature of 217C/423F, and is usually soldered with the iron at **340-370C/650-700F**.

If you set the iron too cold, it takes too long to heat the joint to a sufficient temperature, and nearby parts may be overheated and damaged.
Conversely, if you set the iron too hot, the joint itself can be overheated and this can cause damage to the pads on the PCB or lift traces.
I recommend you use the lower end of the temperature scales I listed as a starting point.

The second consideration is your soldering iron and its tips.

Make sure you are using a **temperature-controlled soldering iron** that can be set to specific temperatures, not just power levels.
If it's not temperature-controlled, just don't use it.
A non-controlled iron will heat up to hotter than you want when it's not being actively used, and cool down to lower than you want when it's being used.
It's not worth the suffering involved.
You will hate the iron, hate yourself, and in all likelihood end up with nonfunctional PhobGCCs.

Do not use the following kind of soldering iron with the tiny dial on the handle.
I call these "Phob Destroyers" because they do not have actual temperature control.
They are cheap, and you get what you pay for: garbage.

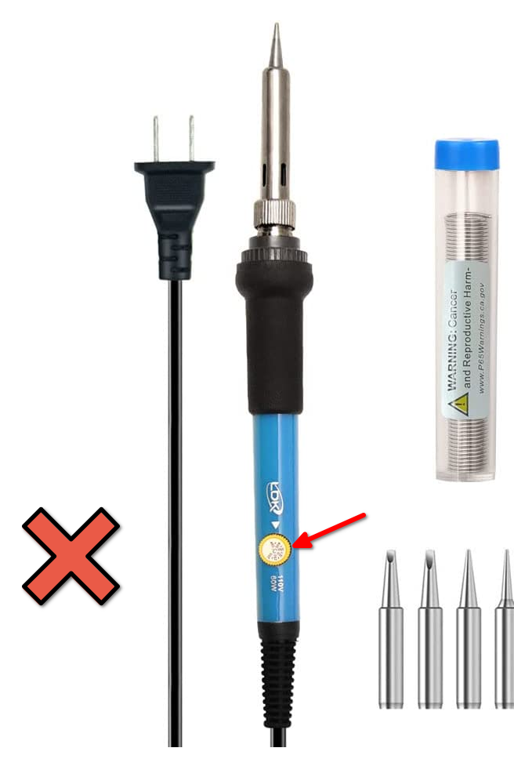
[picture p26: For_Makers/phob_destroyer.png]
Phob-destroying cheap soldering iron


Next is the tip size.
In general, you want to get the most contact between the tip and the solder joint without touching adjacent joints.
Ideally, you use a chisel tip that is exactly as wide as the pads.
Most people don't switch soldering iron tips frequently, so in this case you should select the widest tip usable for the smallest joints.
PhobGCC 2 is much easier to solder than PhobGCC 1, so I recommend either chisel tips at least 1.6mm wide or knife tips that are significantly wider.

Additionally you have to consider tip condition when heating.
When metal is left at a high temperature, the metal surface reacts with oxygen in the air to form an oxide layer that insulates the tip, preventing heat transfer, and also doesn't let solder stick to it.
It is important to **keep the tip tinned with fresh solder** or tip-tinner whenever it is not in use.
While the solder oxidizes, it is also liquid at operating temperature so any oxidation of it can be easily wiped off with a wet sponge before beginning to solder.
If the tip has oxidized significantly, you can scrub off the oxide coating using a **brass wool** sponge, followed immediately by dipping the tip in **tip tinner** or alternatively coating the tip with normal solder.
If you aren't using your iron for a while, make sure to turn it off to stop it from oxidizing.

Finally, it comes down to technique.
In order to transfer the heat as effectively as possible, **apply a lot of pressure** using the soldering iron to both parts that you want to join together.
The board is robust, so you can press down on it very hard, and press across onto pins as hard as you can without bending them, which may vary based on the pin thickness.

### Removing Oxidation from Surfaces
While oxidation quickly grows thick on very hot metal like the soldering iron tip, a thin layer exists on almost every metal.
To remove this, a material called **flux** is applied.
When flux is heated, it becomes reactive and strips the oxygen out of the metal oxides.
This lets the solder bond properly to the surface.

Most solder has a **flux-core**, where flux is actually inside the solder wire so that it is automatically applied when you melt the solder.
Do not get solder that is "solid wire".
There are various kinds of flux as well.
You should get no-clean rosin flux.
More active flux types are useful when soldering to different materials, but you don't need any more than no-clean rosin flux for the gold-plated board of the PhobGCC.
If you do use more active types of flux, then you need to clean the board off after soldering in order to prevent corrosion.

In addition to flux core, if you are having trouble, you can add additional flux, which can come as a gel, a liquid in a syringe or bottle, or in a pen.
I personally only use added flux for tinning the ends of stranded wire.

To effectively use flux-core solder, you must apply solder to the joint, not to the iron.
If you apply solder to the iron, all the flux gets used up on the surface of the iron and there's no effect on the joint surfaces that you want to bond to.
Additionally, if you apply solder to the joint and not to the iron, you can be sure the joint is hot enough before the solder is applied.
Another benefit is that this lets you better control the amount of solder.
If you touch the solder onto the iron tip, you might end up with a big blob of solder on the iron tip and none on the board.

### General description of technique

First, turn on the iron and wait for it to heat up.

Then, for each joint:

1. Scrub off oxidation on soldering iron tip with brass wool.
2. Tin the tip with solder or tip tinner.
3. Clean most of the tinning off the tip with brass wool or wet sponge.
4. Strongly press the tip against both parts that are being soldered together.
5. Apply flux-core solder wire to the joint between the two parts without touching it to the soldering iron tip.
6. Wait for the solder to melt, then feed the wire in until it forms a concave cone. Do not apply too much.
7. Continue heating a second or two more to let the flux in the joint stop bubbling.
8. Remove the soldering iron and let the joint cool without blowing on it.
9. Continue with other adjacent joints.
10. When you're done soldering for now, clean the tip with brass wool or sponge.
11. Apply fresh solder or tip tinner.

### Cleaning Flux

If you leave flux behind from soldering, it can cause problems.
One thing is that the flux residue itself can be conductive, which can cause the Hall sensors to not work properly.
This is especially problematic with flux that isn't labeled as No-Clean.
Additionally, the flux residue is corrosive and can cause the components to corrode long-term.

To remedy this, use rubbing alcohol (as high concentration as you can get) with a cotton swab to clean the flux residue from the PCB when you're done soldering.

One thing of note is that no-clean flux is notably difficult to clean.
When activated, it turns into a gummy, sticky substance.
If you do intend to fully clean every part you make, flux that is not no-clean is actually easier to clean off of the solder joints.
Non-no-clean flux forms a much harder, brittle substance that flakes off relatively easily.

## Board Preparation

[Video Guide](https://www.youtube.com/watch?v=hWuvy4ZEgG0&t=910s)

The C-Stick daughterboard comes attached to the main PhobGCC motherboard.
You will have to remove it.

To do this, first simply snap it off at the motherboard side.
You can use your bare hands, but be careful to avoid touching the button contacts, such as for the Start button, or you may contaminate them with oil.

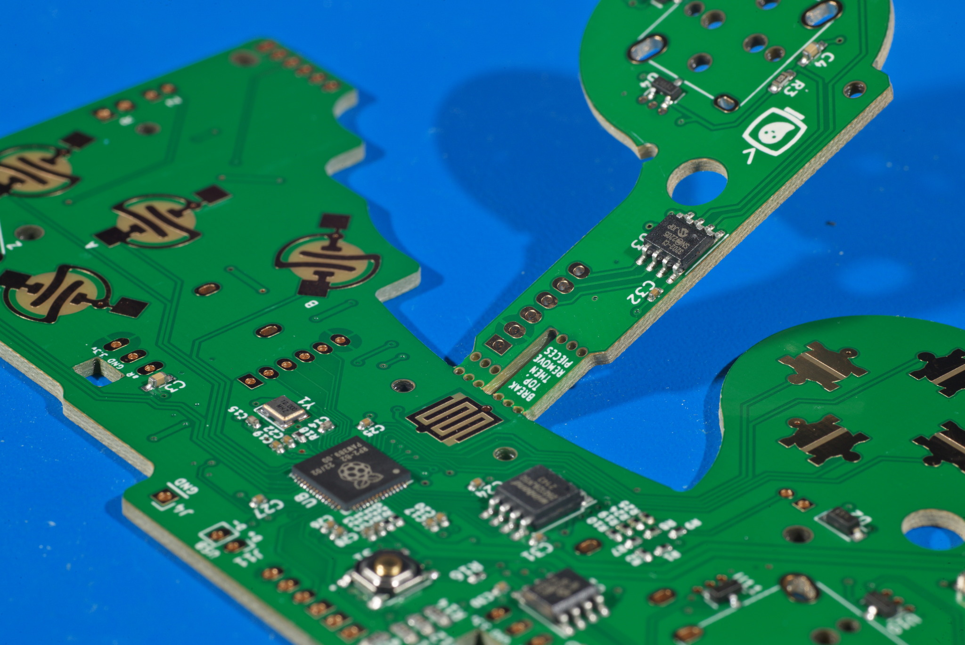
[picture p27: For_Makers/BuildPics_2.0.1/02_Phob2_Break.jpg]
breaking daughterboard


Then, break the two "mousebites" off of the C-Stick daughterboard using pliers.
Note that one is longer than the other; this is normal.

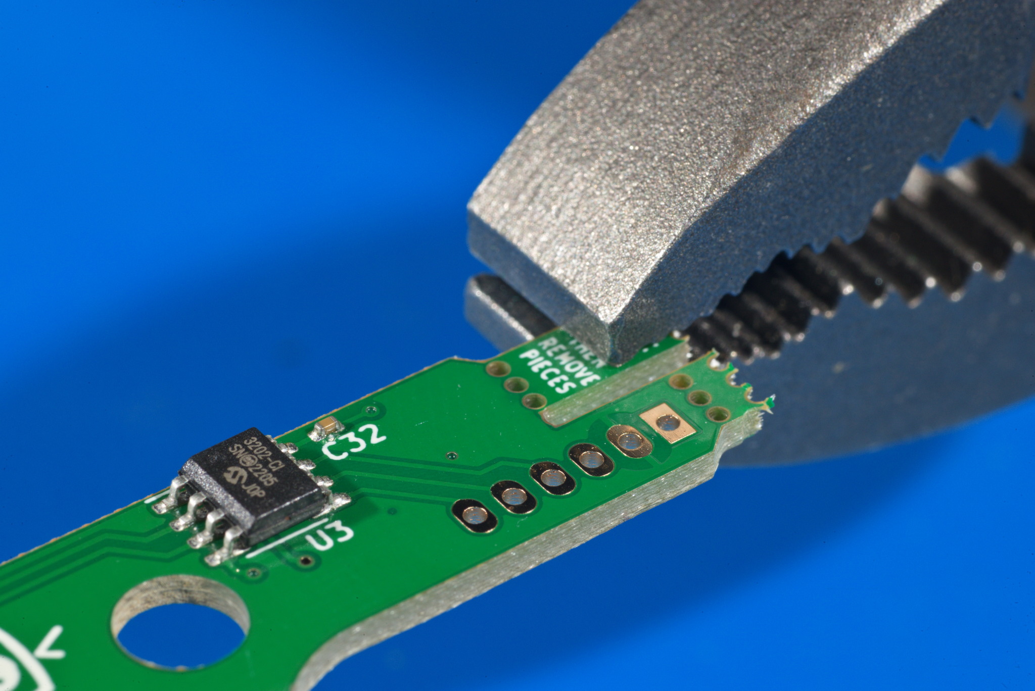
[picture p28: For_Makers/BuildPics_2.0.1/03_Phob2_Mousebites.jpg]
breaking mousebites


This should be the result.

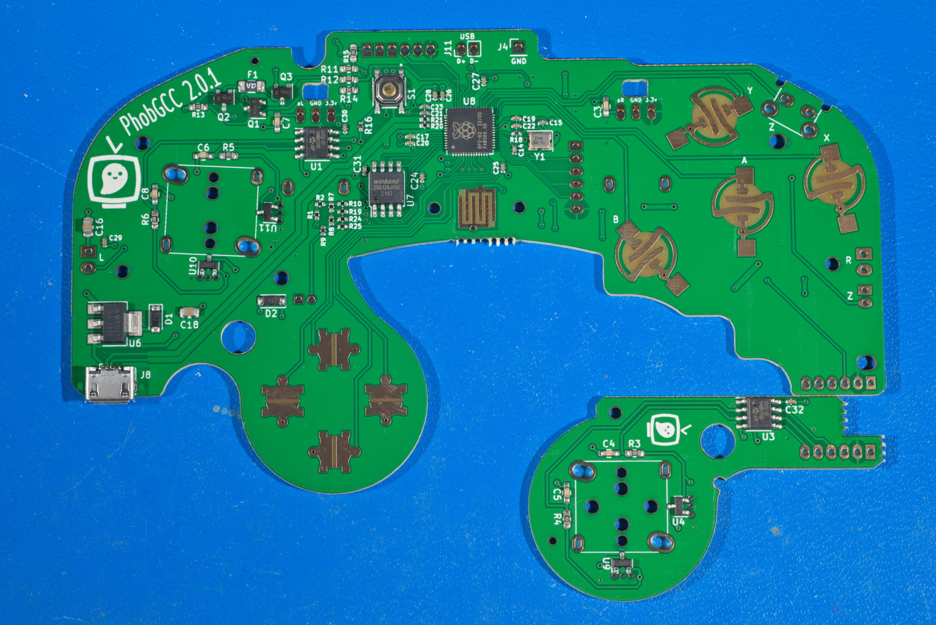
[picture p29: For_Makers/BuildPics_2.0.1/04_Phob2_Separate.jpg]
boards laid out


## RP2040 Programming

Next, load firmware onto the RP2040.

You can download it [here](https://github.com/PhobGCC/PhobGCC-SW/releases).

Plug the board into a computer via the micro USB port while holding button S1 on the motherboard, then release the button.
It will appear as a USB mass storage device, which you need to open in a file browser.
Drag-and-drop the .uf2 firmware file from the software release page into that drive.
The mass storage device will disappear and you are done loading firmware on.

If you ever need to change or update the firmware, simply repeat the process.

## Z button Switch Soldering

[Video Guide](https://www.youtube.com/watch?v=hWuvy4ZEgG0&t=1203s)

The first soldering step is to solder the Z button switch on.

Make sure to put the button on the top side of the board where the silkscreen outline of the component is, not on the back.

Also make sure that the switch stands perfectly square to the board, or the board may not fit in the controller shell properly.

If you are using a Z button switch harvested from an original GCC, you can ignore the two large circular holes.

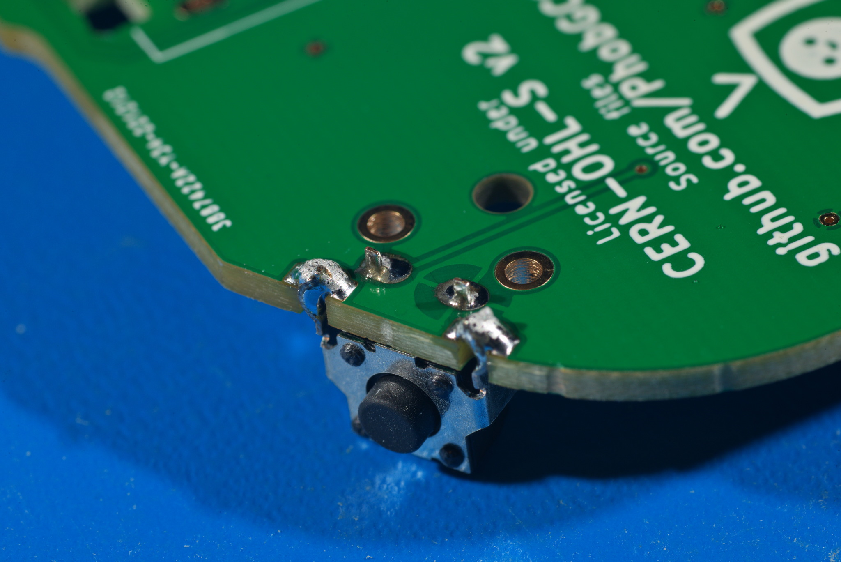
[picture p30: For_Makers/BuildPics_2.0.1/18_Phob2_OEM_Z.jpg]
OEM Z


If you are using an Omron tactile Z switch as listed in the parts ordering guide, here are the slight tweaks you must make.

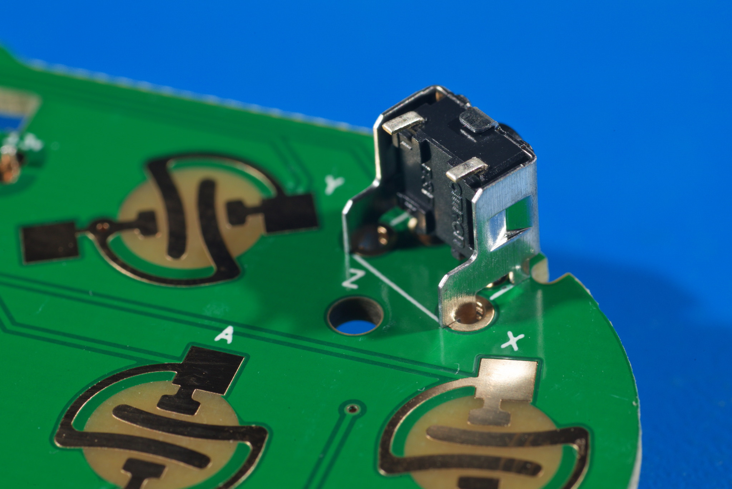
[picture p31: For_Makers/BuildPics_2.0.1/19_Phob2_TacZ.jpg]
Omron Tactile Z before trimming


Firstly, trim the two leads off the top of the button.
These interfere with a rib on the front shell.

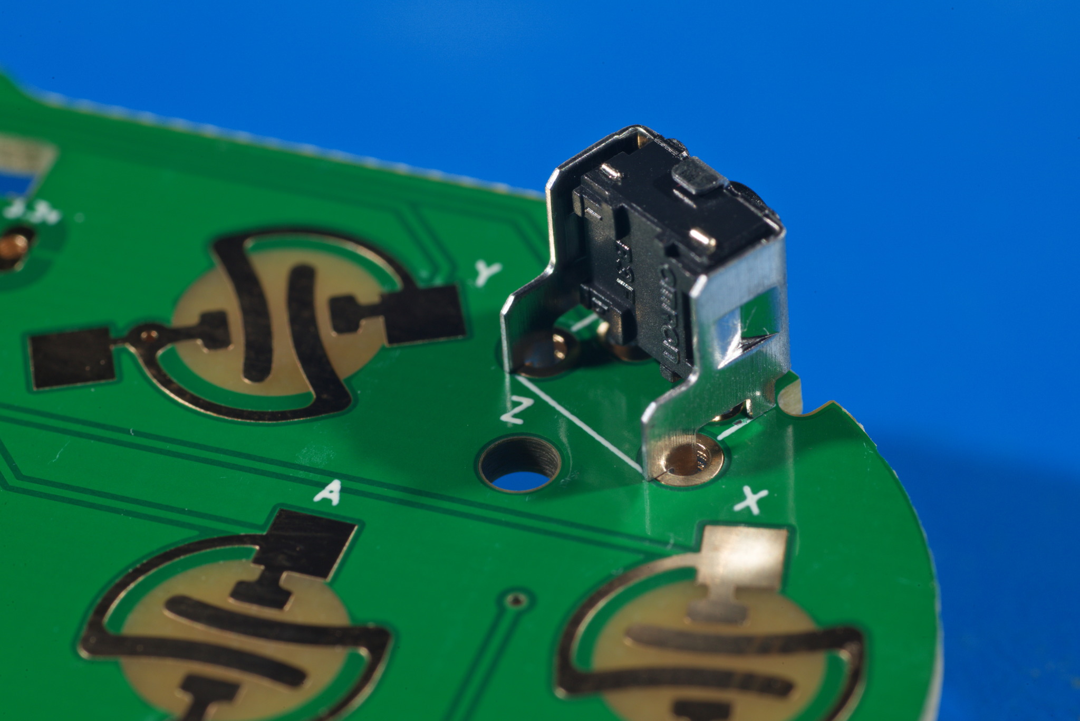
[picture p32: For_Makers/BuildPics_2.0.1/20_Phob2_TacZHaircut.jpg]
Omron Tactile Z haircut


Secondly, when you solder, don't use the U-shaped solder pads at the board edge.
Instead, the structural legs go through the larger holes farther from the board edge.

Make sure to not overfill the holes for the structural legs; you want the solder to sit entirely below the surface.

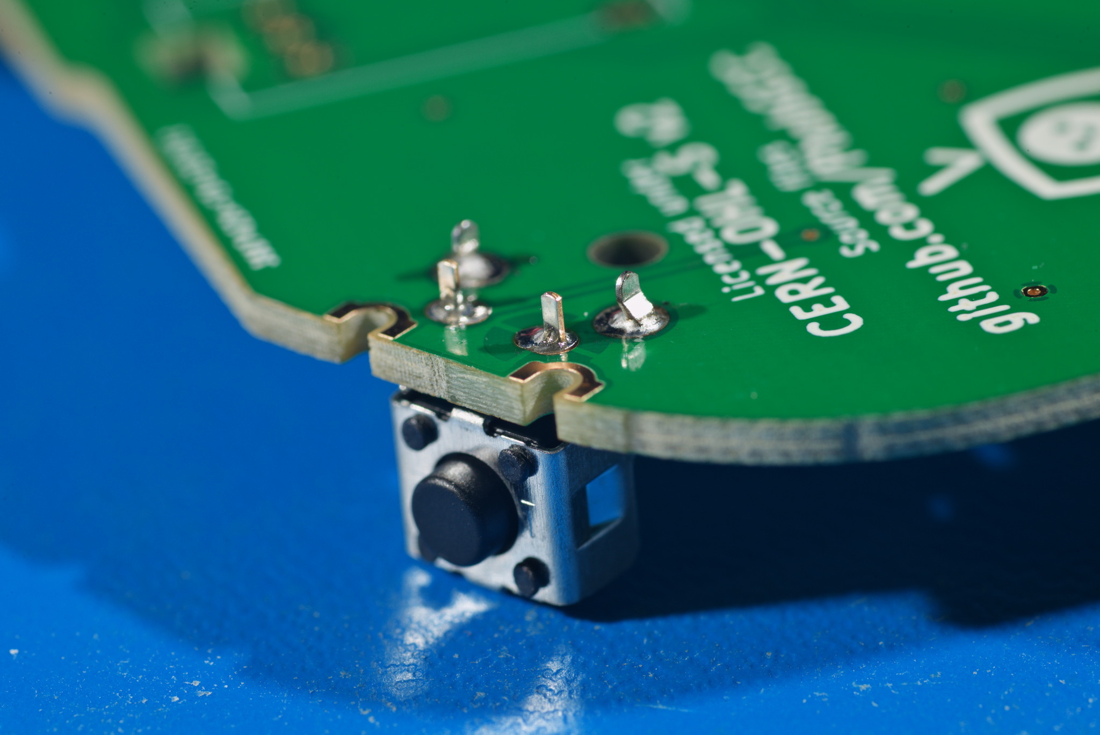
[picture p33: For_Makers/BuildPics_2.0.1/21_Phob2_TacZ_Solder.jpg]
Omron Tactile Z soldered


This is because you will need to trim the structural legs completely flush in order to not interfere with the trigger guards.

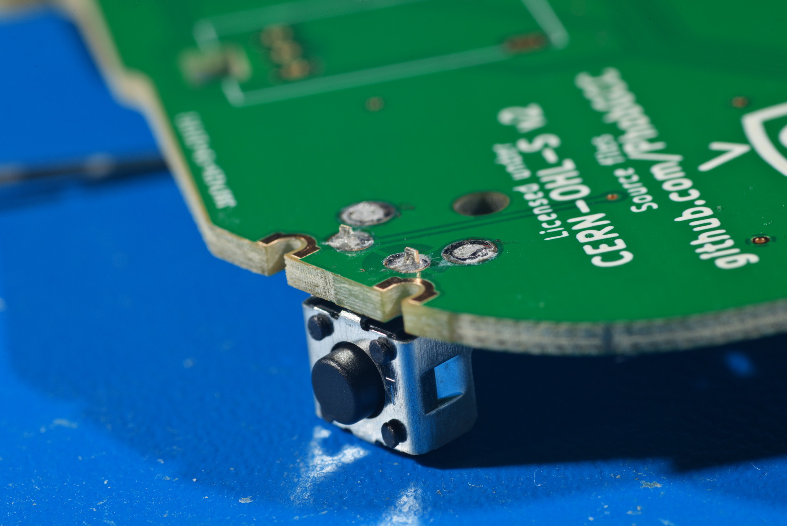
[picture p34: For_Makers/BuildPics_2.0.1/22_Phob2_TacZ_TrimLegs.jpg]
Omron Tactile Z legs trimmed


Additionally, you need to make room for the structural legs on top by trimming the button rubber as follows:

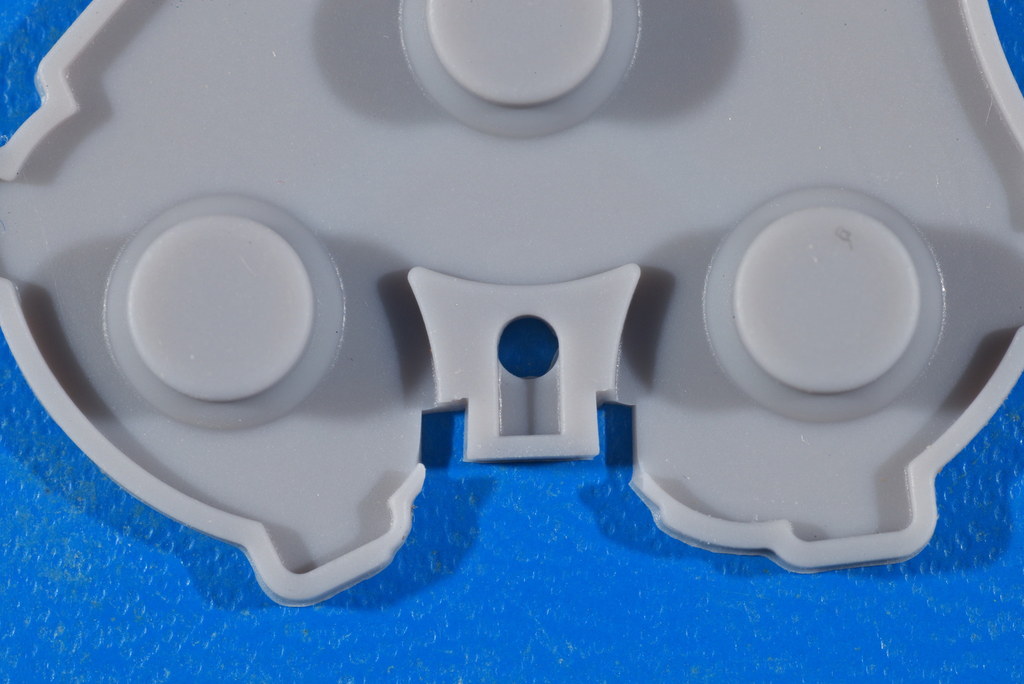
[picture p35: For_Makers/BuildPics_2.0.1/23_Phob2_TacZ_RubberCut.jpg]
Tac Z button rubber trim


As a note for later, it may take a little more force than you may be used to when inserting the motherboard into the front shell when you use an Omron tactile Z switch.

This is normal, and does not cause any issues.

## Trigger Potentiometer Soldering

[Video Guide](https://www.youtube.com/watch?v=hWuvy4ZEgG0&t=1306s)

Mount the trigger potentiometers to the back of the board. Do not mount them to the front side with all of the chips.

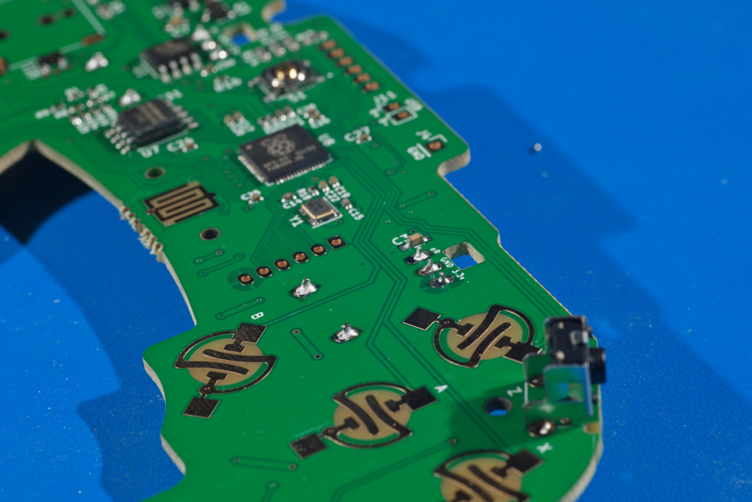
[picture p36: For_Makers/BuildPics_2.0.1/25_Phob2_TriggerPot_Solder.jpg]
Trigger potentiometers soldered


To secure them when soldering, you can tape them to the board with masking tape, or just rest the board on top of the potentiometers.

Be sure to check after soldering your first joint that the potentiometer is laying flat against the back of the board before continuing.

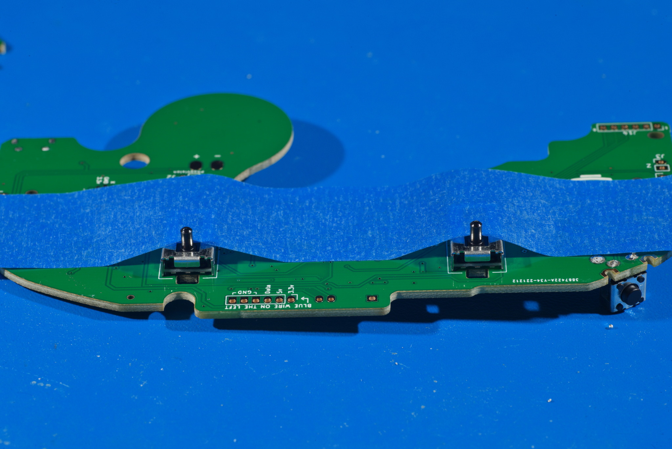
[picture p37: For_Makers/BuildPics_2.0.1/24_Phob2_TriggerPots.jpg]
Trigger potentiometers taped


## C-stick Cable Soldering

[Video Guide](https://www.youtube.com/watch?v=hWuvy4ZEgG0&t=1550s)

For PhobGCC 2, the C-Stick now needs six conductors connecting it to the main motherboard.

You will have to provide your own wire for this, though there may come to be brand-new ribbon cables available that may suit the purposes.
Any such ribbon cables should be between 1 and 1.5 inches long (25 to 38mm) and must be 2 millimeter wire spacing.
We *strongly discourage* the use of ribbon cables harvested from other controllers, as poorly folding previously-used ribbon cables has been a major cause of issues with PhobGCCs in the past.

In this guide I cut and stripped six 1.5-inch (38mm) wires identical to those used in the trigger paddles, and applied flux to the ends.

Then, I used the same technique as in the Trigger Paddle Soldering section to install them in the back side of the C-Stick daughterboard.

Note that this is the side with silkscreen around the through-holes.

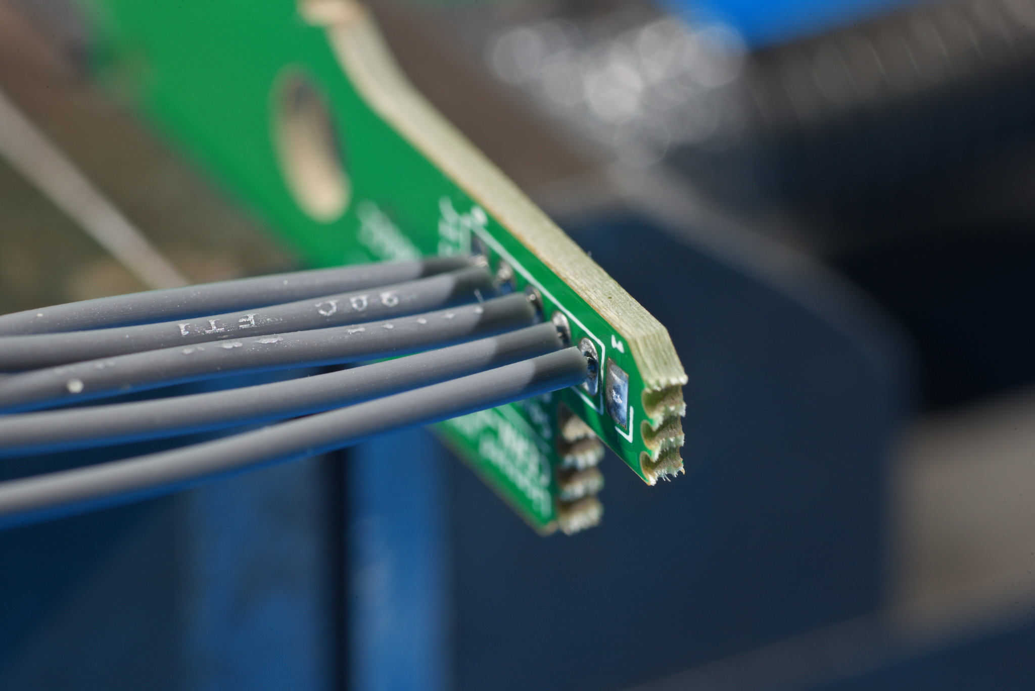
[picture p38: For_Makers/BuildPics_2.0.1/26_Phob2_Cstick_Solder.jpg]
C-stick soldering


For these especially, if you are using individual wires I strongly recommend that you make their lengths as consistent as possible, and solder them such that the insulation ends at the same distance from the C-stick daughterboard.

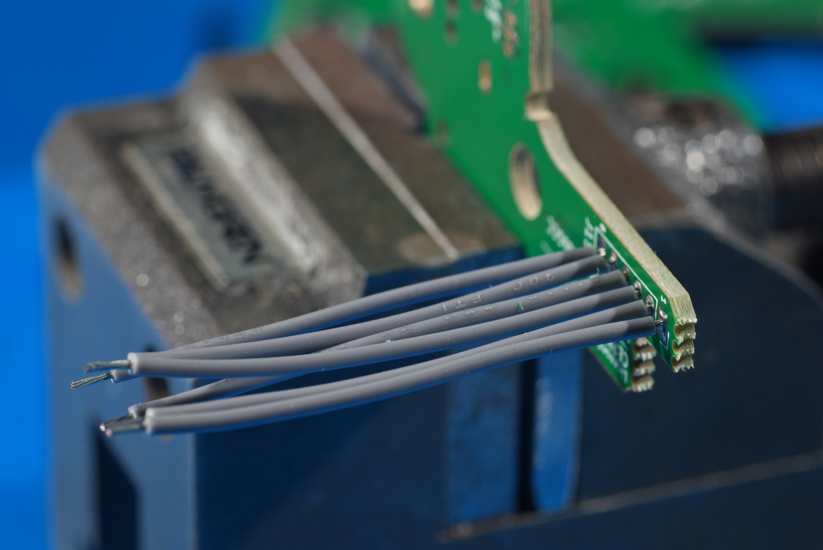
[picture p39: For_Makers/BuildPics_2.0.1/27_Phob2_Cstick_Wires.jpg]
C-stick wires


The uniform length helps when you are inserting the wires into the motherboard.

Support the motherboard above the C-Stick daughterboard with the daughterboard oriented like this.

If you flip it around, the C-stick will not function at all.

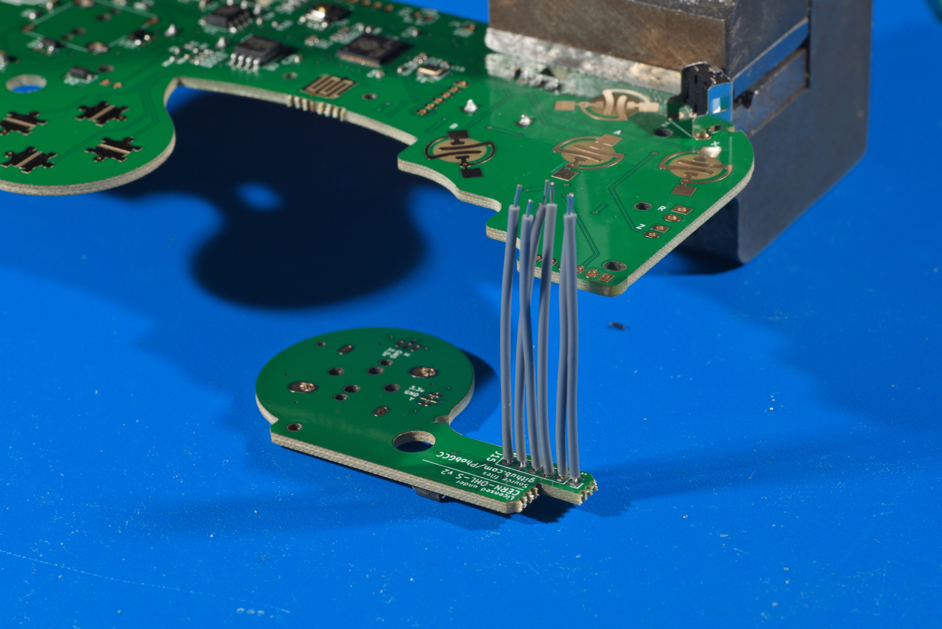
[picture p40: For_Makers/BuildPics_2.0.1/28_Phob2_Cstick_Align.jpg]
C-stick alignmnt


Insert all of the C-Stick wires into the motherboard.

Make sure that all of the wires are straight and none of them are crossed, or the C-Stick will not function.

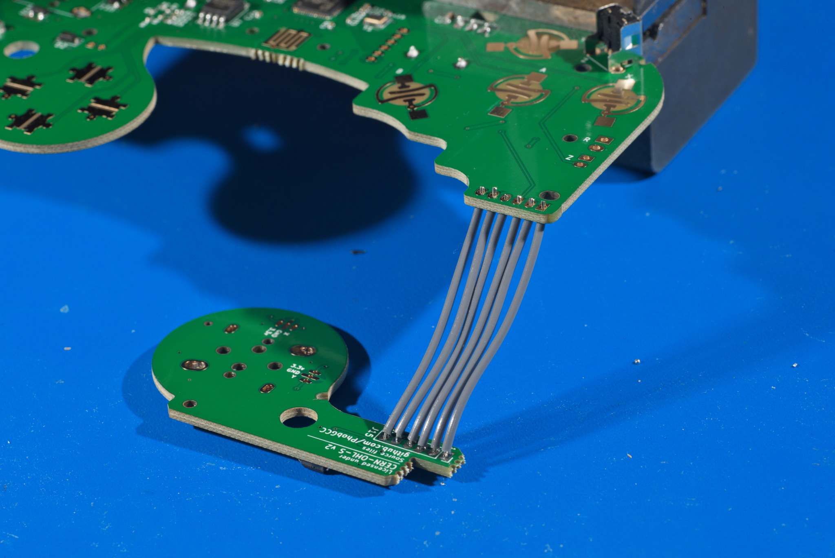
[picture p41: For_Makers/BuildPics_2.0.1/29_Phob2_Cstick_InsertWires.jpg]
C-stick wire insertion into the motherboard


Then solder the wires.

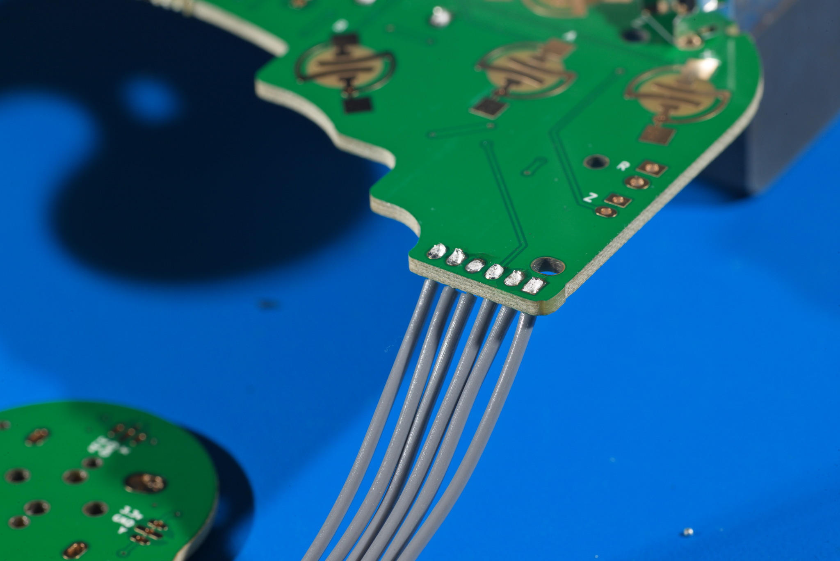
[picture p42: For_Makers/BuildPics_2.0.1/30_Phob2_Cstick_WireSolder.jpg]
C-stick wire soldering to the motherboard


## Trigger Paddle Soldering

[Video Guide](https://www.youtube.com/watch?v=hWuvy4ZEgG0&t=1899s)

If you are using OEM trigger paddles, you may skip this step.

If you are using PhobGCC trigger paddles instead of OEM, you will need to solder wires to them yourself.

Cut four pieces of wire to about 1.5 inches (38mm) long and strip the insulation off the ends.

Apply flux to the ends of the wires, making sure not to cause them to fray if using stranded wire.

Hold the trigger paddles in a vise and apply solder to fill the through-hole pads with solder.

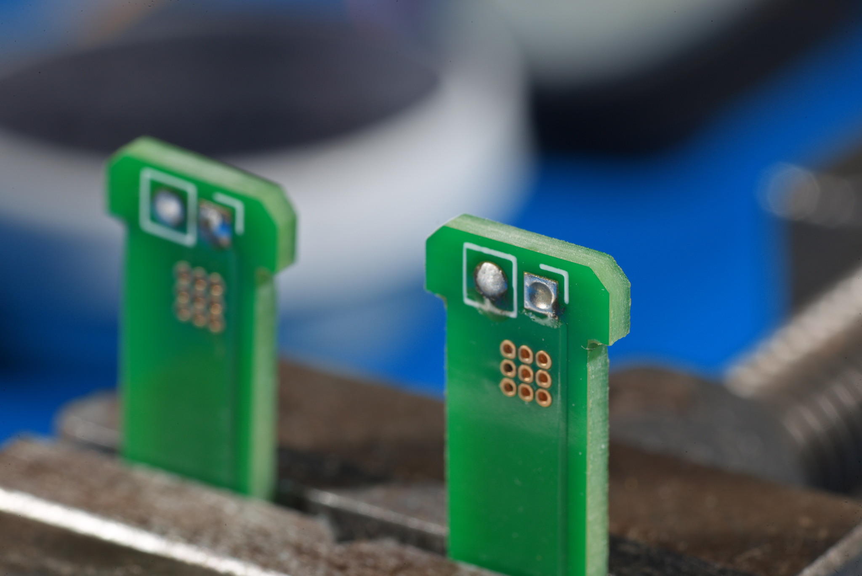
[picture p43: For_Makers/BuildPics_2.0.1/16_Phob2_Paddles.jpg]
Trigger paddle solder


Then, heat the front side of each through-hole with your soldering iron to melt it, and insert the fluxed end of the wire from the back side of the hole where the silkscreen markings are.

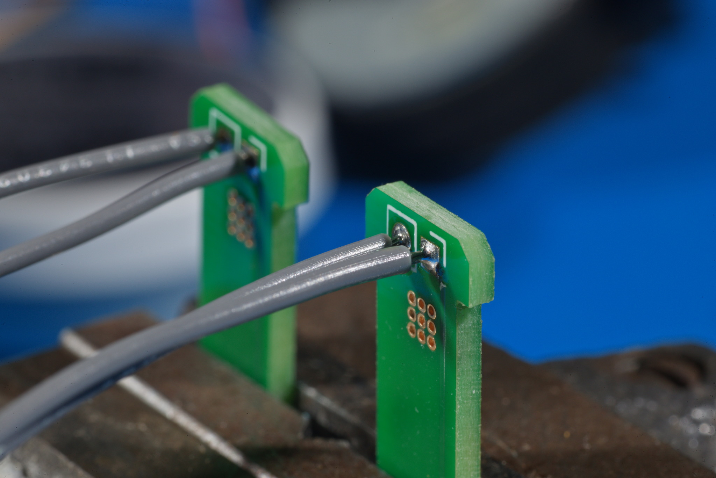
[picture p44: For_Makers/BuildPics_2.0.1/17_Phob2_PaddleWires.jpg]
Trigger paddle wires


## Stickbox Installation

[Video Guide](https://www.youtube.com/watch?v=hWuvy4ZEgG0&t=2078s)

Install the stickboxes on the motherboard and the C-Stick.

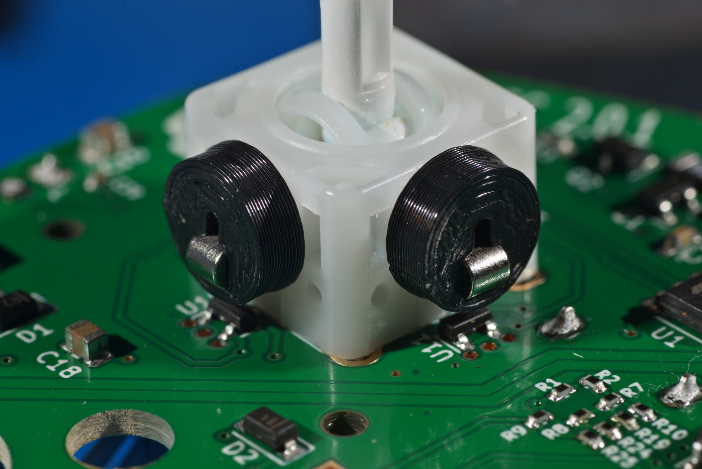
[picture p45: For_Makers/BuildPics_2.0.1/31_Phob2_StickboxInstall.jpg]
Stickbox on motherboard


You must have the magnets mounted above the 3-legged SMD Hall-Effect sensors.

Note that on PhobGCC 1.2.3 and prior, the stickbox on the motherboard was 180 degrees off of normal, but on PhobGCC 2 the magnets must be on the bottom and right.

## Trigger Paddle Soldering

[Video Guide](https://www.youtube.com/watch?v=hWuvy4ZEgG0&t=2199s)

Insert the trigger paddles into the rumble bracket (whether OEM or third-party), ensuring that the contacts on the trigger paddle are visible.
Route the wires out the slots on the back of the rumble bracket.

Then mount the rumble bracket to the motherboard.
Here I have put the rumble motor in the rumble bracket but that can be left until later.
I like to hold the rumble bracket in place with a clothespin.

Tuck the wires from the trigger paddles into their respective holes on the motherboard.

For R, make sure not to mix up the holes with the extra holes for mouseswitch Z, which are nearby.

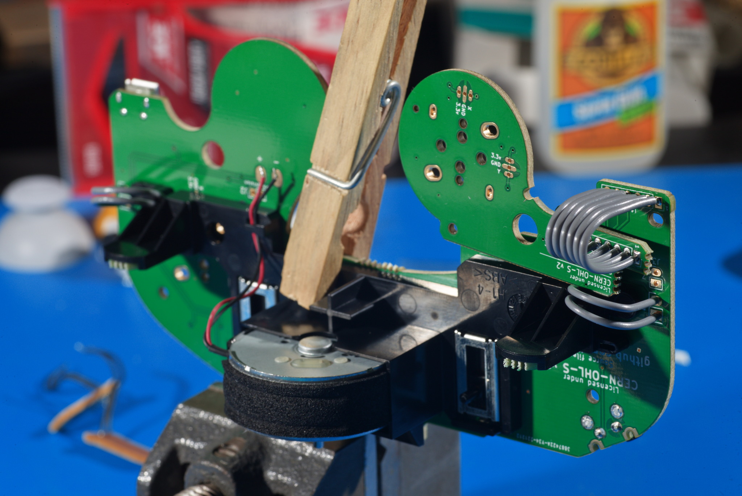
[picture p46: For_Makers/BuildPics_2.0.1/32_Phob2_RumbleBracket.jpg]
Rumble bracket on back of motherboard


Then solder the wires in place.

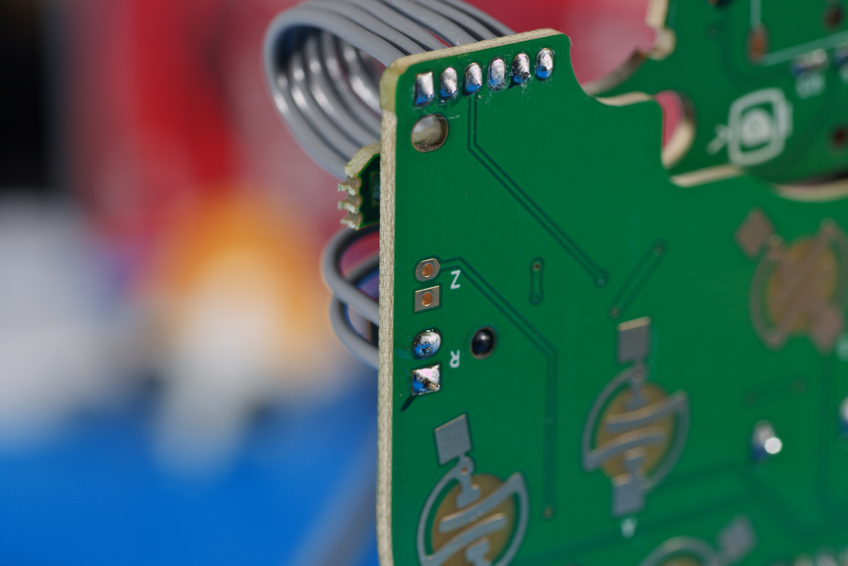
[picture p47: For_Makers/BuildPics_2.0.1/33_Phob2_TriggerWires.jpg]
Trigger wires soldered


## Controller Cable Soldering

[Video Guide](https://www.youtube.com/watch?v=hWuvy4ZEgG0&t=3355s)

Next, install the controller cable into the motherboard.

The cable must go in the back of the motherboard.

If you are using an OEM cable harvested from a first-party Gamecube controller, the black wire should be placed farthest from the center of the controller, and the blue wire closest to the center of the controller.

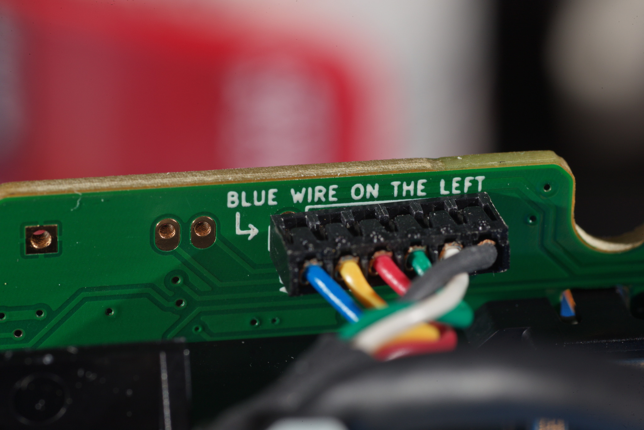
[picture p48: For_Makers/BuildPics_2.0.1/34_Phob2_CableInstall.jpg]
Cable installation with colors labeled


Secure the wire in place, then solder the pins to the pads on the top of the motherboard.

Cable installation with colors labeled

## OPTIONAL PhobVision installation and soldering

PhobVision is a new feature exclusive to PhobGCC 2 where the controller can output composite video to a CRT and provide an actual user interface for the user to calibrate and configure the controller without having to blindly input memorized button combinations.

[Here is a video demonstrating its basic functionality](https://youtu.be/8OOGupE3-ic).

If you choose to install it, here's my suggested method.

It's rather irritating to pack this in with an OEM rumble motor, so you may want to do it with no rumble installed or with a cell rumble motor.
Nonetheless, this guide shows you how to do it so that it fits around the OEM rumble.

[Video Guide for backshell drilling](https://www.youtube.com/watch?v=hWuvy4ZEgG0&t=2498s)

Begin by taking the backshell and marking a point 0.5 inches or 13 mm down directly below the edge, aligned with the center of this tab.

Marked drill hole

Using a *split-point drill bit* to help prevent the bit from wandering around, drill a 7mm diameter hole in the back of the controller.

You may also use a 9/32" bit or a Letter J drill bit.

PhobVision hole drilled

Note that on this particular shell, the bit wandered slightly towards the centerline of the controller, which is fine.

If the bit wanders towards the side of the controller, you may need to carve out the area marked in red to provide clearance for the TRRS jack's flange.

In this case, the hole instead intersects a rib that only exists on T3 shells that you should remove in the vicinity of the hole.

Rib interference with hole

Simply cut the rib off with flush cutters.

Rib cut near hole

[Video Guide for jack, connector, and wire prep](https://www.youtube.com/watch?v=hWuvy4ZEgG0&t=2570s)

Next up we must prepare the 3.5mm TRRS jack for installation.

Untouched jack

To get the jack to fit with an OEM rumble motor, use pliers to bend the tabs on the end sideways.

Note which tabs are used for what.

Jack with bent tabs, labeled

Apply flux to the two bent silver tabs and tin them generously with solder.

Tinned tabs on jack

Cut a two-pin JST-PH pigtail's wires to 3 inches long (75mm), strip the ends, and apply flux.
Shorter wires give less slack when maneuvering, and longer wires are hard to fit, so be fairly precise with the length here.

Then solder them to the two tinned tabs.

Make sure that the black wire goes to the middle tab, and the red wire goes to the other silver tab.

Wires soldered to jack

Make sure the wires are soldered to the back side of the tabs so that they do not stick out past the end.

Wires do not protrude past the end of jack

Generously apply hot glue between the wires and the barrel of the TRRS jack in order to provide strain relief.

Again, do not let it protrude much past the end of the jack.

Hot glue used as strain relief

Next, cut 1.5" (38mm) long wires, strip both ends, and apply flux.
Shorter wires might not reach, and longer can interfere with closing the controller, so be precise with the length here.

Take the JST-PH receptacle and install it on the pigtail for support, then tin the protruding leads and solder them to the 1.25" wires.
You must leave the connector in the receptacle while soldering, or else the pins will lose alignment as the plastic around them softens.

Make sure to match red with red and black with black; I used the scrap ends of the pigtail wires for this so the colors match nicely.

JST receptacle soldered

[Video Guide for wiring to motherboard](https://www.youtube.com/watch?v=hWuvy4ZEgG0&t=3040s)

Insert the receptacle's wires into the back of the motherboard at the J2 through-hole pads, and solder them on the front of the motherboard.

JST soldered to phobvision pads

[Video Guide for soldering rumble motor](https://www.youtube.com/watch?v=hWuvy4ZEgG0&t=3007s)

At this point, if you are installing rumble, mount the rumble motor in the rumble bracket by inserting it into the rectangular box.
Make sure that the shaft is on the cable side, and the motor is rotated so that the wires are on the D-pad side, close to the edge of the box.

First, tin the rumble pads with a puddle of solder, then melt the puddle with your iron and use tweezers to hold the wire in the molten pool of solder.
Remove the iron, and keep the wire still as the solder cools.
Tuck the rumble wires in the clip on the rumble bracket.

Then hot glue the PhobVision JST receptacle to the rumble bracket like depicted, ensuring that the opening is not blocked by the glue.

JST glued to rumble bracket

[Video Guide for installing jack in backshell](https://www.youtube.com/watch?v=hWuvy4ZEgG0&t=3315s)

Next, install the TRRS jack in the backshell and install the nut on the outside using pliers.

I recommend you orient the jack so that the wires initially go towards the center of the controller, then loop around towards the triggers.

Jack in the backshell with suggested wire orientation

Nut holding the jack in place

## Rumble Motor Soldering

[Video Guide](https://www.youtube.com/watch?v=hWuvy4ZEgG0&t=3007s)

If you haven't installed PhobVision, mount the rumble motor in the rumble bracket by inserting it into the rectangular box.
Make sure that the shaft is on the cable side, and the motor is rotated so that the wires are on the D-pad side, close to the edge of the box.

# Completion and next steps

Now your PhobGCC should be complete!

Front of PhobGCC 2

Rear of PhobGCC 2

Reassemble your controller, and follow the Initial Setup procedure in the [PhobGCC Calibration Guide](/For_Users/Phob_Calibration_Guide_Latest.md) for the version of the software you have flashed on the RP2040.

And, enjoy!


This work is licensed under a [Creative Commons Attribution-ShareAlike 4.0 International License](http://creativecommons.org/licenses/by-sa/4.0/).

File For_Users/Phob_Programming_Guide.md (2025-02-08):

# PhobGCC v1.X Programming Guide

This is a guide to programming the teensy microcontroller on PhobGCC v1.X.

Here's a [video walkthrough](https://youtu.be/QWJy-NiV2nU) if you would like to watch instead.

# Tools

* A computer running Windows, MacOS, or Linux.
* A screwdriver for opening your controller (Tri-point is the stock screw, but some controllers may be built with Torx or Phillips).
* A data-capable micro-USB cable with a compact plug.
  * [This cable](https://www.amazon.com/gp/product/B093SWG63B) is the recommended one should you just want to buy one.

# Controller Disassembly

Unplug and then open your controller by removing the six screws on the back located at the end of the handles, near the triggers, and behind the C-stick and D-pad.
Pull the back shell off and lay it down.
Carefully lift the board out of the shell and place the front shell down.

# Installing the IDE, Libraries, and Teensy Files

**NOTE:  It is not recommended to update your libraries as some newer versions may have issues**
**NOTE2:  You only need to do this once**

Go to [The Arduino Website](https://www.arduino.cc/en/software) and to the software section and download the Arduino IDE 2.0.0 for your operating system.
Go through the install as normal.
Upon first run, it may ask about internet access and to install the USB Driver.
These are required in order to program the PhobGCC.
Once the IDE is installed, you can go to the 'Tools' drop-down and select 'Manage Libraries...'.

Libraries

You'll want to search (what is in the single quotes) and install the following:
* 'curveFitting' by Rotario
* 'Bolder Flight Systems Eigen' by Brian Taylor
* 'Bounce2' by Thomas O Fredericks
* 'teensytimertool' by luni64
  * **NOTE:  You'll want to install version 1.0.0 of this library using the drop-down.**

You may need to resize the left panel in order to see the Install button.

Next you'll want to go to the 'File' drop-down and click on 'Preferences...' as seen below:

Preferences

and in the 'Additional board manager URLs' section, you'll want to paste in `https://www.pjrc.com/teensy/package_teensy_index.json`. You'll also want to enable the "Show files inside Sketches" checkbox as shown below:

Preferences_2

Next you'll want to go to the 'Tools' drop-down, in the 'Board' section, Click on 'Board Manager' as seen below:

Boards

And search for and install 'teensy' by Paul Stoffregen.

# Downloading and Flashing The PhobGCC Firmware

Go to the [Releases](https://github.com/PhobGCC/PhobGCC-SW/releases) section of the PhobGCC-SW Github and download the latest available firmware code zip: `Source code (zip)`.
**Extract all the files from the archive to the Arduino folder in your Documents/Home folder.**
Open the `PhobGCC.ino` file that is inside the `PhobGCC` folder in Arduino IDE.

Inside the subfolder `common`, find the document `phobGCC.h` and open it in a text editor (Notepad, if you have nothing else).
Look near the top of the document for the following section:

Versions

Remove the `//` (NOT THE `#`) at the start of the line which contains your board version, and save the file.
**Only uncomment one line.**
If you do not know which one you need, please post a photo of your board in the #user-tech-support channel of the [PhobGCC Discord](https://discord.gg/yrpUu7mgzm) and someone will assist you.

Then plug in your PhobGCC using a Micro-USB cable to your computer.
Once it is plugged in, go to the 'Select Board' drop-down in the top left and click on the "Unknown COM#".
If this does not appear, your cable didn't work.

Choose your Teensy version and the port which has "Teensy" in the name, then click the right arrow in the top left.
This will compile and upload the firmware to your board.

Once this is complete, you can unplug your PhobGCC and reassemble the controller.

# Troubleshooting

* Make sure your cable works, you should hear the operating system's notification sound for plugging a USB device in.
* Make sure you only remove the `//` from your board version, not the `#`.
* If the board reports as null, try another port.
* If you get a warning that says `#warning "can't use staticFunctional with GCC < V7! Fallback to function pointer callbacks"`, then you installed the wrong version of teensytimertool.
* If you're uncertain if the board flashed properly, you can click on the eyeglass in the top right to open the serial monitor (you may need to unplug and replug your PhobGCC). At the top of the output, it'll say the board version, teensy version, and software version.
* If there's a message about `Missing FQBN` then you need to update board files.

For all other issues, please refer to the PhobGCC Discord's tech support.
[PhobGCC Discord](https://discord.gg/yrpUu7mgzm)

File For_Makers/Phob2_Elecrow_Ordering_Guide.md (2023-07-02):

# PhobGCC Version 2.0.5 Elecrow Ordering Guide

This is an illustrated guide to ordering PhobGCC PCBs via the Elecrow Board House. Elecrow's boards are significantly higher quality, have less manufacturing issues, and are tested before arrival, so you won't receive non-functional boards. As such, they are the recommended option when it comes to ordering PhobGCC boards.

# Elecrow Ordering Process Overview

1. Download the files
2. Fill out all information on the [PCB assembly ordering page](https://www.elecrow.com/pcb-assembly.html)
3. Wait for an email to say the quote is ready
4. Go to your [service orders page](https://www.elecrow.com/porder/pcba/orders)
5. Checkout

## Purchasing the PhobGCC v2.0.5 board from Elecrow

Download the files available in the [PhobGCCv2-HW Github](https://github.com/PhobGCC/PhobGCCv2-HW/releases/tag/v2.0.5) in the releases section as shown below:

PHOB2_ELECROW_BOARD_RELEASE

Once you've extracted the files from the .zip, you should have three files. The Phob2 gerbers, the Elecrow BOM, and the Elecrow INFO zip.

Head over to the [PCB assembly ordering page](https://www.elecrow.com/pcb-assembly.html) and fill it out as follows:

**NOTE: Set your PCBA quantity, country, and preferred shipping option**

PHOB2_ELECROW_BOARD_OPTIONS

Once your settings match the image above, you then upload the BOM spreadsheet where it asks, followed by uploading the INFO zip where it asks you to "Upload Other Files".
Scrolling further down you upload the gerbers.

Once that's set, you configure the PCB settings as follows:

**NOTE: Your PCB quantity must match your PCBA quantity, otherwise you may end up with blank boards. You must also select immersion gold coating (ENIG)**

PHOB2_ELECROW_BOARD_OPTIONS

Once its all filled out, double check your settings are set properly and then click "Get a quotation"

When the quote is ready, you'll receive an email. Head over to your [service orders page](https://www.elecrow.com/porder/pcba/orders) and click on checkout:

PHOB2_ELECROW_BOARD_OPTIONS

And the boards will arrive in 3-4 weeks.

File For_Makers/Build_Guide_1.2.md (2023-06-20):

# PhobGCC 1.2 Build Guide

This is an illustrated guide to making a PhobGCC 1.2, using photos taken of a PhobGCC board version 1.2.2.

If you want to see it in motion, watch the [PhobGCC 1.2 Assembly Video](https://www.youtube.com/watch?v=0QmgswFa1cA).

If you are very skilled with your hands, it is certainly possible to build a PhobGCC as your very first soldering project.

But if you are new to soldering, it's highly recommended to get a soldering practice kit to build your physical understanding of the soldering process with before you start and potentially ruin a PhobGCC board, Teensy, and GCC components.

# Tools

It's possible to work with cheap tools and supplies if you're very skilled.

But if you cheap out on solder or soldering iron "because you're just a beginner" you will be in for a lot of pain and suffering.

Come to the Discord server for advice on what to get if you're at all unsure.

## Required Tools

1. Temperature-controlled soldering iron with a moderate size chisel tip. DO NOT USE AN UNCONTROLLED TEMPERATURE IRON!
2. Flux-core solder, ideally no-clean flux (SAC305 ideally)
3. No-clean rosin flux paste (not to be confused with solder paste)
4. Tri-Wing screwdriver and small Phillips or ideally JIS driver set
5. Sharp tweezers
6. Flush cutter (the closer to flush they cut, the better)
7. Pliers
8. Solder sucker (or more sophisticated desoldering tool)
9. Vise or PCB support (the alligator clip kind is not very useful)
10. Multimeter for debugging
11. 90%+ rubbing alcohol and cotton swabs

## Suggested Tools

1. Non-magnetic tweezers, if you're not using printed magnet holders
2. Anti-static mat/grounding strap
3. Fume fan

# Parts

Some of the parts are taken from a donor Gamecube controller, while others must be sourced new. Check the [PhobGCC Ordering Guide](https://docs.google.com/presentation/d/1oINA7_uTVTVmYVD8K1pJWOuYjSPyhjqsKgl4iAZOqRE/edit?usp=sharing) for a list of what you need to purchase.

## New Parts

1. PhobGCC 1.2 board (includes C-stick board and may have two trigger paddles)
2. Teensy 4.0 without headers
3. Headers
4. 4x Hall Effect sensors
5. 4x magnets
6. Either superglue or 3D-printed magnet holders
7. Optional 4x D-pad buttons
8. Optional 4x mouse buttons for ABXY (assembly not depicted)
9. Optional 1x or 2x mouse buttons for triggers (assembly not depicted)

## Internal Parts Harvested from Donor GCC

Not counting the shell, buttons, stick caps, etc.

1. 2x Stickboxes
2. 2x Trigger potentiometers
3. Cable (or make or buy your own)
4. Rumble Motor (or use a cellphone rumble)
5. Rumble Bracket (or source your own 3D-printed one)
6. Z-button switch
7. Optional: trigger paddles with attached wires

For the desoldering process, start at slide 5 of the [PhobGCC 1.1 Build Guide](https://docs.google.com/presentation/d/1Awil69v7xDhX-VOdLnVhseILLCY89gFpTTAPPEig6E4/edit#slide=id.p) or watch [the first section of the PhobGCC 1.2 Assembly Video](https://www.youtube.com/watch?v=0QmgswFa1cA&t=0s).

# Build Process

## Magnet Mounting

If you're using superglue to mount magnets to the stickboxes, consult slide 16 of the [PhobGCC 1.1 Build Guide](https://docs.google.com/presentation/d/1Awil69v7xDhX-VOdLnVhseILLCY89gFpTTAPPEig6E4/edit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). You want to do this before the rest of the process, preferably a few hours before.

If you're using 3D-printed magnet holders, you can do this right before putting the stickboxes on the board.
First press-fit the magnet holders over the pegs on the stickboxes, add a thin coat of superglue inside the magnet holder, then press-fit the magnets themselves into the magnet holders.
Consult [this section of the PhobGCC 1.2 Assembly Video](https://www.youtube.com/watch?v=0QmgswFa1cA&t=1858s).

Magnet Holders on Stickboxes

Make sure the magnets are oriented horizontally.

## Soldering Interlude

Many people attempting to build PhobGCCs are new or relatively novice solderers.
In this section I outline the basic processes and techniques involved in soldering in the hopes of making the process go more smoothly.

Soldering is basically applying fancy conductive hot glue to the surfaces, with some important differences.
The first difference is that the parts that are getting soldered together must be very hot in order for the solder to stick.
Additionally, the parts that are being soldered are usually damaged by too much heat, or heat applied for too long.
Finally, the oxidation on the surface of the metal must be stripped off somehow.

These must all be considered together in order to successfully solder.

### Heating
First, in order to properly heat the joint, you need to heat the joint to above the melting temperature of the solder.
This involves a few considerations.

First is the melting temperature of the solder, which you use to determine the iron temperature.

* Leaded Sn63Pb37 solder melts at 183C/361F, and is usually soldered with the iron at **315-340C/600-650F**.
* Lead-free SAC305 (Sn 96.5%, Ag 3%, Cu 0.5%) solder melts at a higher temperature of 217C/423F, and is usually soldered with the iron at **340-370C/650-700F**.

If you set the iron too cold, it takes too long to heat the joint to a sufficient temperature, and nearby parts may be overheated and damaged.
Conversely, if you set the iron too hot, the joint itself can be overheated and this can cause damage to the pads on the PCB or lift traces.
I recommend you use the lower end of the temperature scales I listed as a starting point.

The second consideration is your soldering iron and its tips.

Make sure you are using a **temperature-controlled soldering iron** that can be set to specific temperatures, not just power levels.
If it's not temperature-controlled, just don't use it.
A non-controlled iron will heat up to hotter than you want when it's not being actively used, and cool down to lower than you want when it's being used.
It's not worth the suffering involved.
You will hate the iron, hate yourself, and in all likelihood end up with nonfunctional PhobGCCs.

Do not use the following kind of soldering iron with the tiny dial on the handle.
I call these "Phob Destroyers" because they do not have actual temperature control.
They are cheap, and you get what you pay for: garbage.

Phob-destroying cheap soldering iron

Next is the tip size.
In general, you want to get the most contact between the tip and the solder joint without touching adjacent joints.
Ideally, you use a chisel tip that is exactly as wide as the pads.
Most people don't switch soldering iron tips frequently, so in this case you should select the widest tip usable for the smallest joints.
On the PhobGCC 1.2, the smallest joints are the Hall effect sensors, which have pads 0.8mm wide.
I recommend you use a **chisel tip from 0.8 to 1mm wide**, ideally.
I actually use a 1.6mm wide tip, which works better for the larger pads but is slightly more difficult to use for the Hall effect sensors.

Additionally you have to consider tip condition when heating.
When metal is left at a high temperature, the metal surface reacts with oxygen in the air to form an oxide layer that insulates the tip, preventing heat transfer, and also doesn't let solder stick to it.
It is important to **keep the tip tinned with fresh solder** or tip-tinner whenever it is not in use.
While the solder oxidizes, it is also liquid at operating temperature so any oxidation of it can be easily wiped off with a wet sponge before beginning to solder.
If the tip has oxidized significantly, you can scrub off the oxide coating using a **brass wool** sponge, followed immediately by dipping the tip in **tip tinner** or alternatively coating the tip with normal solder.
If you aren't using your iron for a while, make sure to turn it off to stop it from oxidizing.

Finally, it comes down to technique.
In order to transfer the heat as effectively as possible, **apply a lot of pressure** using the soldering iron to both parts that you want to join together.
The board is robust, so you can press down on it very hard, and press across onto pins as hard as you can without bending them, which may vary based on the pin thickness.

### Removing Oxidation from Surfaces
While oxidation quickly grows thick on very hot metal like the soldering iron tip, a thin layer exists on almost every metal.
To remove this, a material called **flux** is applied.
When flux is heated, it becomes reactive and strips the oxygen out of the metal oxides.
This lets the solder bond properly to the surface.

Most solder has a **flux-core**, where flux is actually inside the solder wire so that it is automatically applied when you melt the solder.
Do not get solder that is "solid wire".
There are various kinds of flux as well.
You should get no-clean rosin flux.
More active flux types are useful when soldering to different materials, but you don't need any more than no-clean rosin flux for the gold-plated board of the PhobGCC.
If you do use more active types of flux, then you need to clean the board off after soldering in order to prevent corrosion.

In addition to flux core, if you are having trouble, you can add additional flux, which can come as a gel, a liquid in a syringe or bottle, or in a pen.
I personally find that I have no need for these, but some find it very helpful.

To effectively use flux-core solder, you must apply solder to the joint, not to the iron.
If you apply solder to the iron, all the flux gets used up on the surface of the iron and there's no effect on the joint surfaces that you want to bond to.
Additionally, if you apply solder to the joint and not to the iron, you can be sure the joint is hot enough before the solder is applied.
Another benefit is that this lets you better control the amount of solder.
If you touch the solder onto the iron tip, you might end up with a big blob of solder on the iron tip and none on the board.

### General description of technique

First, turn on the iron and wait for it to heat up.

Then, for each joint:

1. Scrub off oxidation on soldering iron tip with brass wool.
2. Tin the tip with solder or tip tinner.
3. Clean most of the tinning off the tip with brass wool or wet sponge.
4. Strongly press the tip against both parts that are being soldered together.
5. Apply flux-core solder wire to the joint between the two parts without touching it to the soldering iron tip.
6. Wait for the solder to melt, then feed the wire in until it forms a concave cone. Do not apply too much.
7. Continue heating a second or two more to let the flux in the joint stop bubbling.
8. Remove the soldering iron and let the joint cool without blowing on it.
9. Continue with other adjacent joints.
10. When you're done soldering for now, clean the tip with brass wool or sponge.
11. Apply fresh solder or tip tinner.

### Cleaning Flux

If you leave flux behind from soldering, it can cause problems.
One thing is that the flux residue itself can be conductive, which can cause the Hall sensors to not work properly.
This is especially problematic with flux that isn't labeled as No-Clean.
Additionally, the flux residue is corrosive and can cause the components to corrode long-term.

To remedy this, use rubbing alcohol (as high concentration as you can get) with a cotton swab to clean the flux residue from the PCB when you're done soldering.

## Teensy Programming

Begin by programming the Teensy 4.0 according to [this guide](/For_Users/Phob_Programming_Guide.md).

## Teensy Soldering

See [this section of the PhobGCC 1.2 Assembly Video](https://www.youtube.com/watch?v=0QmgswFa1cA&t=822s).

Insert two 14-pin strips and one 2-pin strip of low-profile header pins into the top of the board, long ends down.

Place the already-programmed Teensy 4.0 atop the header pins, then solder the Teensy to the pins.

Teensy soldered to pins

Next, flip the board over and either support the board by the Teensy or securely tape the Teensy to the board so that the pins stick up.

Teensy pins sticking out

Cut the pins as flush as possible to the back of the board. If you don't cut these flush, the rumble bracket may not fit well and the shell won't close easily.

Trimmed Teensy pins

Solder the pins to the board, making sure the Teensy remains flush to the board and the vias that the pins reside in are not overfilled with solder.

Teensy pins soldered in board

Detail of flush Teensy pins

## Trigger Potentiometer Soldering

See [this section of the PhobGCC 1.2 Assembly Video](https://www.youtube.com/watch?v=0QmgswFa1cA&t=1640s).

Mount the trigger potentiometers to the back of the board. Do not mount them to the same side as the Teensy.

Trigger pots in board

You can tape them to the board with masking tape to keep them in place, or just rest the board on top of the potentiometers to secure then in place while you solder them.

Trigger pot soldered

## Z-button Switch Soldering

See [this section of the PhobGCC 1.2 Assembly Video](https://www.youtube.com/watch?v=0QmgswFa1cA&t=1781s).

Mount the Z-button switch to the top of the board, the same side as the Teensy. Do not mount it to the back of the board.

Z button in place

Solder it to the board, with extra solder applied to the contacts at the board edge. These are structural.

Z button soldered

You do not need to solder the inner pads on the board edge.

## OPTIONAL D-pad Buttons

This is an optional enhancement to the D-pad that goes underneath the OEM rubber domes.

This does not enhance the feel of the buttons, but it makes them harder to press accidentally and more consistent when you do want to press them. This is not suggested for Samus mains because it makes it harder to activate the Extended Grapple.

First, observe the wings on the button pads. The wings are where the switch contacts will go.

Dpad no switches

The switches on the right and left pads must be oriented with the contacts oriented horizontally, while the switches on the top and bottom pads must be oriented with the contacts oriented vertically.

If you mix this up, the buttons will be shorting the contacts all the time.

Dpad 2 switches placed

The process of soldering goes as shown:

Dpad 3 switches placed, solder process

Top: Apply a tiny bit of solder to one wing of the contact only.

Left: Using tweezers, hold a switch in place and melt the existing solder to tack it in place. Do all the buttons to this stage, then fit-check their placement using the shell to make sure they are centered under the rubber domes..

Fit checking dpad

Right: Tack the opposite corner down using solder, then remelt the first corner and then this corner to eliminate strain.

Bottom: Solder down the rest of the corners.

The buttons should now look like this:

All dpad buttons

Using a multimeter, check continuity between the exposed copper pads that stick out past the button. They should be disconnected when the switch isn't pressed, and shorted when the switch is pressed.

## Bending and Soldering Hall Sensors

See [this section of the PhobGCC 1.2 Assembly Video](https://www.youtube.com/watch?v=0QmgswFa1cA&t=2000s) although it is missing the actual soldering.
Also see [the PhobGCC Hall Effect Sensor Soldering Video](https://www.youtube.com/watch?v=js1TYhYUG0g).

The Hall effect sensors come as a small black prism with two beveled edges.

Straight hall sensor

The legs of the Hall effect sensors must be bent 90 degrees so that the beveled edges face upward, with the bend as close as possible to the head of the sensor.

Bent hall sensor

If the bends are located too far away from the body of the sensor, it will be difficult to get the stickbox in place.

Place the bent sensors in the board with the legs through the holes.
Make sure they are on the upper side of the board with the text; this is easy to mix up on the C-stick board.

Hall sensors on C-stick board

On the motherboard, place the Hall sensors on the top and left sides where the pads are small and close together.
Do not try to spread the Hall sensor legs to fit through the wider-spaced holes on the bottom and right sides; you may break the sensor and it won't work even if you manage to not break them.

Hall sensors on motherboard

Install the stickboxes, already equipped with magnets, on the boards before soldering down the Hall sensors.

stickbox on c-stick board

stickbox on motherboard

Align the height of the sensors to be roughly the level of this feature in the T3 stickbox or lower, making sure the sensors are centered and level.
You may need to bend the legs a bit.

stickbox height reference

When you are satisfied with the sensor height, solder one leg in place.
You can then use tweezers to manipulate the position while you remelt that one solder joint in order to fine-tune it.

one hall leg soldered

Then, solder the remainder of the legs.

all hall legs soldered

Finally, trim the legs.

c-stick hall legs trimmed

On the motherboard, trim the legs *very closely* and then reflow the solder on each joint.
They should be no taller than half the height of the screw heads for the stickbox.
If you don't do this, it makes the controller harder to reassemble and may break the solder joints.

They do not need to be as flat on the C-stick.

**Note: using leaded solder on the motherboard Hall effect sensors is a common cause of long-term failure for PhobGCC 1.2s.**
Leaded solder is soft and deforms easily when pressed upon by the trigger guard.
This commonly causes a short-circuit, which does no damage but makes the analog stick hold hard left or hard right.
Using SAC305 solder, which is harder, seems to have fewer issues.
And as mentioned before, make sure that the Hall sensor solder joints are as flat to the board as you can make them, to help mitigate this issue.

motherboard hall legs trimmed

## C-stick Cable Soldering

See [this section of the PhobGCC 1.2 Assembly Video](https://www.youtube.com/watch?v=0QmgswFa1cA&t=2261s).

You can either use the ribbon cable harvested from the OEM board, or you can solder in individual wires. If you use your own wires, have the insulation be about 3/4" (19mm) long.

Since I'm using the OEM cable, I prefer to put the red line on the side with the square pad on the C-stick board.

Cable in c-stick board

Solder the exposed ends to the pads.

Cable soldered to c-stick board

Next, connect the opposite end of either the ribbon cable or the wires to the motherboard.
Make sure that both boards are facing up, and make sure they are oriented like this to ensure that the connections do not get mixed up.

Cable connecting c-stick to motherboard

Then, solder the wires to the motherboard.

C-stick cable soldered to motherboard

## Controller Cable Soldering

See [this section of the PhobGCC 1.2 Assembly Video](https://www.youtube.com/watch?v=0QmgswFa1cA&t=2548s).

If you are using an OEM cable harvested from a first-party Gamecube controller, the black wire should be placed farthest from the center of the controller, and the blue wire closest to the center of the controller.

Controller cable colors

The pins themselves are actually basketlike sheet metal forms, so when you solder them, they take up a fairly large amount of solder.

Controller cable soldered

## Trigger Paddle Soldering

If you don't harvest the trigger paddles from the OEM controller, you will need to prepare new wires for the PhobGCC's trigger paddles.

It is possible to solder mouse buttons to these trigger paddles, but that is not covered here as it involves a more invasive modification to the OEM controller hardware.

Cut and strip wires that are roughly 1 inch long (25mm), and solder them in so that the wires are on the opposite side of the PCB from the pads.

Do not have the wires exit the front side with the contacts, or they can short to the Hall effect sensor pins.

Wires soldered into trigger paddles

Load the trigger paddles with pads exposed into the rumble bracket (whether OEM or third-party), and mount the rumble bracket to the PCB.
Make sure the wires safely exit the slots and do not get caught or pinched under the bracket.

Trigger wires in slots of rumble bracket

Tuck the trigger paddle wires into the nearby holes in the motherboard.

Trigger wires in holes

Then, being careful not to let them slip out, solder them to the motherboard.

Trigger wires soldered

## Rumble Motor Soldering

Next, mount the rumble motor back in the rumble bracket by inserting it into the rectangular box.
Make sure that the shaft is on the cable side, and the motor is rotated so that the wires are on the D-pad side, close to the edge of the box.

Rumble motor in place

Apply a generous blob of solder to each of the rumble motor pads.

Rumble motor solder blobs

To solder the wires down, melt the blob of solder with your soldering iron and use tweezers to hold the wire in the pool.
Remove the hot soldering iron, and keep the wire still as the solder cools.

Clip the wires into place on the rumble bracket.

Rumble motor wires soldered

# Completion and next steps

PhobGCC 1.2.2 complete

Now that you have completed the soldering steps, follow the [Board Debugging Guide for PhobGCC 1.2](/For_Makers/Board_Level_Debugging_1.2.md) to make sure it's ready to go.

Then, reassemble it, and follow the Initial Steps in the [PhobGCC Calibration Guide](/For_Users/Phob_Calibration_Guide_Latest.md) for the version of the software you have flashed on the Teensy.

And, enjoy!


This work is licensed under a [Creative Commons Attribution-ShareAlike 4.0 International License](http://creativecommons.org/licenses/by-sa/4.0/).

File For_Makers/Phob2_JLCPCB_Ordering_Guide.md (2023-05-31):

# PhobGCC Version 2.0.5 JLCPCB Ordering Guide

This is an illustrated guide to ordering PhobGCC PCBs via the JLCPCB Board House.

# JLC Ordering Process Overview

This is very important, or else you will get nonfunctional boards.

1. Preorder the SMD components that are in limited supply, as listed below.
  * These are not stocked by JLC but they are stocked by distributors; JLC will order them and keep them in your name until you order boards that need them.
2. **Once ALL OF THE PARTS come in, only then order boards with assembly.**
  * You may need to wait a week or more.
  * Do not order boards before you receive notification that ALL of your parts are available.
  * If you order boards before parts are available, then they will be assembled without the parts and they will not function.
3. Wait for your boards to come in.

## Pre-ordering SMD components

Since the 2.0.5 board is fully integrated, all of the non-GCC components are soldered onto the board at the board house. Some of these may be out of stock, and as such need to be pre-ordered before you place a board order. Pre-ordered components take on average 2 weeks to arrive at the JLCPCB warehouse after you pay for them. If a component takes longer, you can contact JLCPCB support for a more accurate timeframe of arrival.

The following parts usually have low stock and pre-ordering them is advised:

**NOTE: These part quantities are for a single 2.0.5 board. You need to multiply them by the number of boards you plan to order.**
**NOTE 2: You can only order PCBs in quantities of 5, 10, 15, 20, 25, 30, 50, or more. Do not order SMD components for amounts other than these or you will either have unused extra parts or unpopulated PCBs later.**

* [1x RP2040](https://jlcpcb.com/partdetail/RaspberryPi-RP2040/C2040)
* [1x NOR Flash Chip](https://jlcpcb.com/partdetail/WinbondElec-W25Q128JVSIQ/C97521)
* [4x DRV5055 SMD Hall Sensor](https://jlcpcb.com/partdetail/TexasInstruments-DRV5055A3QDBZR/C266128)
* [2x MCP3202 ADC](https://jlcpcb.com/partdetail/MicrochipTech-MCP3202_CISN/C56997)
* [1x Crystal Oscillator](https://jlcpcb.com/partdetail/390662-TAXM12M4RKDCDT2T/C403945) Note: you need 1 more per order you plan to place regardless of how many boards are in the order..

Once you've clicked on each link and added the quantities you need into your cart, click the cart icon in the top right, go to the "Parts Manager Tab", to the "Order Parts" subtab, to the "Cart" subtab as follows:

PHOB_PREORDER_PARTS

This is where you double-check the part quantities you've selected and make sure that they're all checked, even if in stock.
Once you checkout, JLC will attempt to purchase those parts for you at the quoted price.
If they end up costing more, they'll email you about supplementing the cost, and if they end up costing less, you will be refunded the difference.
You can check the status of part orders in the "Parts Order History" subtab.

Some of the parts may be in stock and be available immediately.
You must wait until **ALL PARTS** are available before proceeding.
This may take one or two weeks.

## Purchasing the PhobGCC v2.0.5 board from JLCPCB

**NOTE: Once your pre-ordered SMD Components have come in (report as "Complete" in the parts order history), you may proceed to ordering boards. If they are not in, the parts will not be present on your board**

Download the files available in the [PhobGCCv2-HW Github](https://github.com/PhobGCC/PhobGCCv2-HW/releases/tag/v2.0.5) in the releases section as shown below:

PHOB2_BOARD_RELEASE

Make sure to redownload the latest even if you already downloaded it in the past, as occasionally we make changes to the components to account for stock shortages.

Once you've extracted the files from the .zip, you should have three files. The Phob2_Gerbers .zip, the Phob2_Bom.csv, and the Phob2_Pos.csv. Click "Order Now" on JLCPCB, make sure you are set to "Standard PCB/PCBA" tab, click "Add Gerber File", and upload the Phob2_Gerbers.zip. Once the files are uploaded, you should see the board process and then load in as shown below:

PHOB2_BOARD

Once you've checked that the size is set to 90.26x125.5mm, you can progress with configuring it.
The recommended settings are the defaults, setting your board quantity, setting "Different Design" to 2, and setting the Surface Finish to ENIG, as seen below:

**NOTE: ONLY ORDER THE BOARD QUANTITY YOU HAVE PARTS FOR!**

PHOB2_SETTINGS

Scroll down to PCB Assembly and toggle it on the right.
Select Standard PCBA Type (Not available for large orders or colors), the top side, and confirm parts placement as seen below.

**NOTE: For large orders such as more than 50 boards or different colors, Standard Assembly is required. This attaches removable rails to the PCB at a significant extra cost.**

**NOTE2: If arranging group buys or purchasing in large quantities, we strongly suggest using Standard PCBA so DOA boards are less likely.**

PHOB2_ASM

Click "Confirm" and then upload the Phob2_Bom.csv to the left and and the Phob2_Pos.csv to the right.
Set the usage description to Research/Education/DIY -> DIY HS Code and click "Next".
The text at the top of the next screen should look like the following with all 25 confirmed.
If they are not confirmed, and are not one of the five above in the pre-ordering section, stop ordering and ask in the [PhobGCC Discord](https://discord.gg/yrpUu7mgzm).

PHOB2_PARTS

After clicking "Next", you'll be presented with a view of the parts on the board.
If this screen is corrupted, that's okay.
The files are known good and this is just the website bugging out.
You want to make sure there are no red boxes anywhere as those indicate missing components.
You can then click "Save To Cart" and pay for your boards.

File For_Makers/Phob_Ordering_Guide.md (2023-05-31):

# PhobGCC Version 1.2.3 Ordering Guide

This is an illustrated guide to acquiring all the parts you need to assemble a PhobGCC.

***Teensy 4.0s are extremely hard to find and/or scalped to expensive prices so we highly suggest that you not order PhobGCC 1.2 boards if you don't have Teensy 4.0 boards already.***

We expect to have PhobGCC board version 2 out by the end of 2022, which will have better parts availability and greatly simplified assembly.

# Required Parts

The following parts are unique to the PhobGCC and must be acquired per this guide, with no non-identical substitutions.
* 1 PhobGCC v1.2.3 Board
* 1 Teensy 4.0
* 4 Hall Effect Sensors
* 30 Low Profile Header Pins
* 4 Magnets
* High Viscosity Glue
* Optional: 4x D-pad Buttons
* Optional: 6x Mouse Buttons for ABXYLR

The following parts are standard to a GCC and can be acquired via a number of different ways, some of which will be outlined here.

* 2 Stickboxes
* 2 Trigger Potentiometers
* 1 Cable with a GCC Plug
* Rumble Bracket
* Z-button Switch
* Optional: Rumble Motor

# Purchasing the PhobGCC Board

There are two main ways to acquire a PhobGCC Board. The first way is if you intend to only build a single controller, you can contact a local modder in your region using [this map](https://www.nojonsmods.com/moddermap) to see if they have spare for sale. Alternatively, you can also check [Etsy](https://www.etsy.com/) or [eBay](https://www.ebay.com/) as some often appear for sale. If you cannot find a single board for sale or you intend to build more than one PhobGCC, you can order the boards directly from a board house. The one outlined here will be for [JLCPCB](https://jlcpcb.com/).

First, you can download the files available in the [PhobGCC-HW Github](https://github.com/PhobGCC/PhobGCC-HW/releases) in the releases section as shown below:

PHOB_HW_FILES

Once you've extracted the files from the .zip, you should have three files. The Gerbers .zip, the bom.csv, and the top-pos.csv. Click "Order Now" on JLCPCB, click "Add Gerber File", and upload the Gerbers.zip. Once the files are uploaded, you should see the board load in as shown below:

PHOB_BOARD

Once you've checked that the size is set to 91.41x147.63mm, you can progress with configuring it.
The recommended settings are the defaults, plus setting your board quantity, setting "Different Design" to 4, and setting the Surface Finish to ENIG, as seen below:

PHOB_SETTINGS

Scroll down to PCB Assembly and toggle it on the right.
Select the top side and Economic PCBA Type (Not available for large orders or colors) as seen below.
If you choose to use Standard PCBA, JLC will have to add rails to the board, increasing the price significantly.

**NOTE: For large orders more than 50 boards or different colors, Standard Assembly is required. This attaches removable rails to the PCB at a significant extra cost.**

PHOB_ASM

Click "Confirm" and then upload the bom.csv to the left and and the top-pos.csv to the right.
Set the usage description to Research -> DIY and click "Next".
The next screen should look like the following below with all 10 confirmed.
If they are not confirmed, stop ordering and ask in the [PhobGCC Discord](https://discord.gg/yrpUu7mgzm).

PHOB_PARTS

After clicking "Next", you'll be presented with a view of the parts on the board.
If this screen is corrupted, that's okay.
The files are known good and this is just the website bugging out.
You want to make sure there are no red boxes anywhere as those indicate missing components.
You can then click "Save To Cart" and pay for your boards.

# Purchasing Other PhobGCC Parts

The remaining parts can be purchased from distributers as listed below:
* Teensy 4.0:
  * **NOTE: Most likely out of stock. Ask in the discord**
  * [PJRC](https://www.pjrc.com/store/teensy40.html)
  * [Digikey](https://www.digikey.com/short/93vqqmzm)
  * [Mouser](https://www.mouser.com/ProductDetail/SparkFun/DEV-15583?qs=bZr6mbWTK5kognUaBX05Cg%3D%3D)
  * [Sparkfun](https://www.sparkfun.com/products/15583)
  * [Adafruit](https://www.adafruit.com/product/4323)
* Hall Effect Sensors:
  * **NOTE: For the magnets listed in this guide using the height in the PhobGCC Build Guide, there is no difference between low and high sensitivity sensors**
  * [Digikey Low Sensitivity](https://www.digikey.com/short/8z9r4943)
  * [Digikey High Sensitivity](https://www.digikey.com/short/5qqfr2qh)
  * [Mouser Low Sensitivity](https://www.mouser.com/ProductDetail/Texas-Instruments/DRV5053CAQLPGM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)
  * [Mouser High Sensitivity](https://www.mouser.com/ProductDetail/Texas-Instruments/DRV5053EAQLPG?qs=U0ECReq1GB%2FEJedkxMZGLA%3D%3D)
* Low Profile Header Pins:
  * **NOTE: The main requirement is that the pitch mating is 2.54mm and that the insulation height is 1.52mm. Any headers of this specific size will work. NORMAL ONES WON'T**
  * **NOTE 2: You only need one unit of either of the following per controller. These come in length 36.**
  * [Digikey](https://www.digikey.com/short/qmwbq233)
  * [Digikey](https://www.digikey.com/en/products/detail/samtec-inc/TLW-136-05-T-S/1105024) - more expensive
* Magnets:
  * [DH1H1 Magnets](https://www.kjmagnetics.com/proddetail.asp?prod=DH1H1) - For a jack-of-all trades, use these.
  * [D12 Magnets](https://www.kjmagnetics.com/proddetail.asp?prod=d12-n52) - For best control at the rim (like Pivots), use these.
  * [N30H Magnets](https://www.digikey.com/short/br3n8hz3) - For best control at the center (like ICs desyncs), use these.
  * [Canadian option](https://www.indigoinstruments.com/magnets/rare_earth/discs/small-neodymium-cylinder-magnet-2.5x2.5mm.html) - Similar to DH1H1
  * [For EU](https://www.supermagnete.de/eng/disc-magnets-neodymium?length-or-diameter=2.00,3.00&height=2.00,3.00)
* High Viscosity Glue:
  * [Gorilla superglue gel](https://www.amazon.com/dp/B00OAAUAX8)
  * [Epoxy](https://www.mcmaster.com/66195A13/)
* Magnet Holders:
  * See the `3d-printing` channel in the discord for printable designs that will hold magnets to the stickbox. Use in concert with the above adhesive for easy and secure attachment.
* Optional Mouse Buttons for ABXYLR:
  * [Low Actuation Force Buttons](https://www.digikey.com/short/q4r0jh3j)
  * [High Actuation Force Buttons](https://www.digikey.com/short/dcddr0jr)
  * [Teflon Tape For Support](https://www.mcmaster.com/76475A51/)
* Optional Discrete Buttons for D-Pad:
  * [SMD Buttons](https://www.digikey.com/short/v93wrw12)

# Purchasing Other GCC Parts

The GCC-specific Parts have a few different methods of acquisition
* Stickboxes
  * T3 GCCs as per [this guide](https://gccontrollerlibrary.com/guides/gamecube-controller-stamps-guide/)
  * Official Wii Classic and Wii Classic Pro Controllers
  * Sold Loose on [Etsy](https://www.etsy.com/)
* Trigger Potentiometers
  * Any GCC
  * Official Wii Classic Controllers (No Handles)
  * [Kadano Etsy Shop](https://www.etsy.com/shop/Kadano?ref=simple-shop-header-name&listing_id=1187350029) - if in stock
* Cable with a GCC Plug
  * Any GCC
  * Alibaba Cables
  * [Liquid Cable](https://firescc.com/diy-custom-cables)
* Rumble Bracket
  * Any GCC
  * [Wumble](https://github.com/wavtype/wumble)
  * [FIRESCC](https://firescc.com/mod-guides#/rumble-bracket)
* Z-button Switch
  * Stock - Any GCC
  * Tactile - Official Wii Classic Controllers (No Handles)
  * Tactile - [BattleBeaverCustoms](https://battlebeavercustoms.com/products/replacement-gamecube-tactile-z-switch)
  * Tactile - [FIRESCC](https://www.etsy.com/listing/753452766/fires-performance-mod-kit-for-the?)
  * Tactile - [Digikey](https://www.digikey.com/short/hp5vvv7w) **NOTE:  NEEDS SOME MODIFICATION OF CONTROLLER BUTTON RUBBER**
  * Mouseclick - [SimpleControllers](https://simplecontrollers.bigcartel.com/mouseswitch-z)
* Optional Rumble Motor
  * Any GCC
  * [Cellphone Rumble](https://www.amazon.com/10-Pieces-Vibration-Motor-Vibrating/dp/B00N9J3BTG)

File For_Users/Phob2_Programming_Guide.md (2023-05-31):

# PhobGCC v2.0 Programming Guide

This is a guide to programming the teensy microcontroller on PhobGCC v2.0.

# Tools

* A computer running Windows, MacOS, or Linux.
* A screwdriver for opening your controller (Tri-point is the stock screw, but some controllers may be built with Torx or Phillips).
* A data-capable micro-USB cable.

# Controller Disassembly

Unplug and then open your controller by removing the six screws on the back located at the end of the handles, near the triggers, and behind the C-stick and D-pad.
Pull the back shell off and lay it down.
Carefully lift the board out of the shell and place the front shell down.

# Downloading and Flashing The PhobGCC v2.0 Firmware

Go to the [Releases](https://github.com/PhobGCC/PhobGCC-SW/releases) section of the PhobGCC-SW Github and download the latest available firmware. For the PhobGCC v2.0 board, you will want to download the .uf2 file as shown below:

PHOB2_FILES

Move the .uf2 file to somewhere you can easily find it. Then unplug your controller from the adapter or console it is connected to, hold down the button on the front of the board, and plug the controller in as shown below:

**NOTE: It is easier to plug in Micro-USB first and then hold the button and plug in USB-A on your computer**

PHOB2_PLUGIN

You should have it appear as a mass storage device, similar to a flashdrive. Drag the .uf2 file onto the controller.

Once the transfer is finished, the USB mass storage device will automatically disconnect.
If you re-connect it, the .uf2 file will not appear to be there.
This is normal.

PHOB2_PLUGIN

Once this is complete, you can unplug your PhobGCC and reassemble the controller. Continue to the calibration guide.

# Troubleshooting

## Controller not accepting any commands

Should the controller not be accepting any commands, there is a chance that the flash may have come with garbage data and it may be messing the controller up. Follow the steps below:

1. Download [This file](https://drive.google.com/file/d/15iXiLqbS9To-jfmHwR3WShfgkgc5nex1/view?usp=sharing).
2. Flash that file onto your PhobGCC v2, and **don't** disconnect the Micro-USB cable. After about 10 seconds, It'll reconnect as a mass storage device again.
3. Flash the normal firmware and proceed with calibration.

For all other issues, please refer to the PhobGCC Discord's tech support.
[PhobGCC Discord](https://discord.gg/yrpUu7mgzm)

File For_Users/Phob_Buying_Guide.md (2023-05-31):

# PhobGCC Buying Guide: How to Evaluate a Phob

So you want to buy a PhobGCC, but you may not know what to look for, and you may not know how experienced the seller is at making them. We on the PhobGCC team are planning on vetting Phob makers in the hopes that there will be people you can trust, but not everyone making them will be certified. It is an open project, after all.

This is especially important if you're buying used, since you may not know who assembled it at all.

This guide aims to show you what to check for, ideally before you buy. If buying in-person, ask the seller to take it apart to show you if they're not on our list.

# Easy Things to Look For

This section is for things that are simple to verify without technical knowledge: whether it works, and important part selection.

## What Version

PhobGCC comes in several board revisions, which are identifiable by the number following the PhobGCC name. Some are much more common than others.

Which board version you have affects how you update the firmware.

### 1.0

PhobGCC 1.0

* Very rare.
* Has no rumble.
* Has no support for Hall-effect C-sticks.

### 1.1

PhobGCC 1.1 with Teensy 3.2

* Somewhat common.
* Has no rumble.
* Has support for Hall-effect C-sticks. The above photo has a potentiometer C-stick board from an OEM controller; this is not desirable.
* Exists in three variants with the same board, but each needs its own individual firmware:
  * Teensy 3.2: the standard version, where the main chip on the Teensy has many visible legs on all four sides. Not that common due to a Teensy 3.2 shortage.
  * Teensy 4.0: an alternate microcontroller option that can be distinguished by having no legs. These also have a wire added by hand going across the Teensy board.
  See photo below for what a Teensy 4 looks like on a PhobGCC 1.1.
  * Teensy 4.0 with Diode Fix: similar to above, but pins 7 and 8 on the Teensy may be shorted, or the diode next to the connector may be shorted.

PhobGCC 1.1 with Teensy 4 attached

### 1.2:

PhobGCC 1.2.1

PhobGCC 1.2.2

* Has rumble support.
* Has mouse button support on the face buttons other than Start.
* Exists in three different board variants *with shared firmware support*.
  * 1.2: A handful of prototypes exist.
  * 1.2.1: A few resistor/capacitor values were changed. Only a few prototypes exist.
  * 1.2.2: Wide release. D-pad, Hall sensor, and rumble motor contacts were changed. C-stick and mouse-button-supporting L/R paddles come attached to the main board to ensure all Phobs have no OEM C-stick boards.

Some customized versions may exist, but all are required by the license to remove the Phob Ghost icon and the PhobGCC name. Ask the seller for info on what versions they were based on.

## Functionality

Obviously, the controller should work. All buttons, triggers soft and hard (unless explicitly modified to remove soft-press), d-pad, and control sticks. If the board is version 1.2 or later, rumble should function too.

If trigger hard press is disabled in hardware, then many aspects of controller configuration will be impossible.

The sticks should not be very noisy or jittery when held off-center, but jitter between two adjacent values is acceptable. Notches should have repeatable coordinates when entered from the same direction, though they may have different coordinates if entered differently (clockwise, counterclockwise, straight from the center).

The controller should be set up so that it doesn't have snapback. You can test this in game, but ideally you can run Smashscope on a Wii+480i CRT to see graphs.

## Stickbox

The stickboxes which contain the stick mechanism should be T3, which are entirely white plastic and mounted with two screws on the underside of each.

T1/T2 stickboxes, which have metal frames around plastic innards, are far more prone to wear and becoming loose. Additionally, they are soldered down, making them difficult to replace. This effectively limits the lifespan of a PhobGCC.

## C-Stick Board

The C-Stick board should be a PhobGCC one with magnets, rather than an OEM C-Stick board with potentiometers.

While an OEM C-Stick can function when new, the PhobGCC is not designed to gracefully handle any PODE that develops in the potentiometers, and you *will* get misinputs as the stick wears.

This also limits the lifespan of a PhobGCC, although it is not difficult for an experienced Phob maker to remedy if they have the parts.

## USB Cable

If your PhobGCC came with mouse button switches installed for ABXY, the Y button gets in the way of the USB port on the Teensy and the seller should include a right-angle or 180 degree USB cable that clears the mouse button switches.

# Intermediate Things to Look For

Here is where we begin evaluating the quality of the work.

## Soldering Workmanship

### Shorts

There must be no connections made between pads that are close together. You should be able to see green completely separating the solder.

### Solder Joint Shininess

It is commonly believed that solder joints are supposed to be shiny, but that mainly applies to leaded solder (Sn63 or Sn60), not lead-free solder (such as SAC305). Most commercial products these days use SAC305 or similar due to regulations, but Sn63 is still often preferred by hobbyists for its ease of use.

Ask your vendor what kind of solder the PhobGCC you are evaluating was made with before judging the joint quality by how shiny they are.

### Solder Bonding

All solder joints should have the solder clearly sticking to both the component and the board in order to make a strong physical and electrical connection.

### Solder Quantity

The entire pad on the board should be wet out with solder, but there ideally should not be enough solder to form a convex ball.

Bad solder joint

This is an example of a solder joint that has poor contact with the board and caused undesirable stick behavior.

## Physical Workmanship

### Solder Joint Height

The pins below the Teensy must not protrude below the bottom of the board or else they will interfere with the plastic rumble bracket.

Likewise, the solder joints for the Hall effect sensors for the main stick should be cut fairly close to the PCB or else they will make it difficult to close the controller.


This work is licensed under a [Creative Commons Attribution-ShareAlike 4.0 International License](http://creativecommons.org/licenses/by-sa/4.0/).

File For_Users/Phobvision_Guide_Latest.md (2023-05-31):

NOTE: This is for PhobGCC 2 with firmware version 0.29.

# PhobVision

PhobVision is a feature specific to PhobGCC version 2 that provides graphical configuration, calibration, and training tools built into the controller.



Not every PhobGCC v2 has PhobVision installed. If you're interested, ask your local modder if they can install it.

# Starting PhobVision

To start PhobVision:

1. Plug a 3.5mm TRRS to RCA video cable compatible with Sony camcorders into the controller, and plug the yellow plug into a TV composite input. The cable must be TRRS = Audio Left, Video, Ground, Audio Right. You can alternately use the red plug of a 3.5mm TRS to stereo RCA audio cable. 
2. Hold the Z button on the controller.
3. Plug the GCC cord into a powered-on console or GCC adapter.

If you hold Z while the controller first receives power, it will not connect to the console or adapter and instead boot into PhobVision mode where it will be outputting composite video.
Note that if the Z button is stuck, this may result in the controller never connecting to a console.

# Navigating PhobVision

Use the D-pad to navigate around, use A to select items, and hold B for 0.5 seconds to go back in the menu system.

If you change a setting, tapping B briefly will save the changes.
Continuing to hold B will cause you to back to the next higher menu level.

# Stick Calibration

When you use PhobVision to calibrate, you can follow the instructions onscreen, which should correspond with the instructions in the [PhobGCC Calibration Guide](/For_Users/Phob_Calibration_Guide_Latest.md).
It doesn't have room to say it, but you can still press Start to skip the measurements and begin notch adjustment on the notches you've measured.

However, you are presented with more information than you would get while calibrating using Smashscope, and this may be useful.



On the top right, it shows you what step you are at in the procedure.
During notch adjust, if you haven't measured some of the notches, then it will skip some of the steps.

On the bottom left, you see the raw measurements, in a range from 0 to 1, that the controller is reading from the Hall effect sensors.
This is useful for determining whether something is wrong with the controller.
Both axes should respond to the stick movement.
If the raw measurements for the C-Stick are always zero or one, then there is likely something wrong with the wiring. If only the C-Stick is affected, it's likely a broken connection, but if both sticks are affected, then it is likely a short affecting the shared communication bus.

At the center is the controller output that would be sent to the console, with floating point precision.
This is useful when doing notch adjustment to see where you are within each integer coordinate.

On the right is the coordinate Melee would see after the controller output gets mapped to its smaller input circle.

One more thing of note is that if you are currently calibrating, there only way to back out and cancel the calibration is to unplug the controller's GCC cable.

# Configuration

These should be fairly self-explanatory to operate.

Choose between which settings you change using (usually) left/right on the D-pad, and change the settings with up/down.
If you hold up/down for more than 10 changes, it will begin to change more rapidly.

If you have changed a setting from what was last saved, tapping B briefly will save the changes.
Continuing to hold B will cause you to back to the next higher menu level.

# PhobScope

The PhobScope tools let you view and record the controller's inputs and outputs with millisecond precision to see the results of your calibration and configuration.

## Input Viewer

The Input Viewer shows the current stick positions of the controller, as well as the button and trigger states both before and after remapping and trigger modes are applied.



The left side shows an octagon representing the standard 100-unit-radius stick gate, with the position of the left stick shown as a large square and the C-stick shown as a small square.

The top right shows the hardware inputs of the controller with no trigger modes, remapping, or button lockouts applied.
Below that you can see the actual output of the controller with your settings applied.
A non-active input will be gray, while an active input will be white.
The analog trigger values are shown numerically.
Occasionally there's a one or two unit discrepancy between the trigger analog values of the Hardware Inputs and Controller Outputs.
This is normal.

At the bottom are the stick coordinates output by the controller for the left stick and the C-stick.
You can see both the coordinates sent to the console and the coordinates as interpreted by Melee.

## Stickmap Plots

The Stickmap Plots let you record 100 milliseconds of stick motion in 2D and plot it overlaid on various stickmaps relevant to Melee.



This can help you perfect your stick inputs and filter configurations for in-game techniques such as ledgedashing and dashback out of crouch.

After you press Start, the recording begins after the unfiltered stick values move 10 units away from where it was when you pressed Start.

On the left is the visualization of the stick motion.
The filtered stick output is shown as white points and the unfiltered stick motion is gray points.
The currently highlighted sample is shown as a large box for filtered output and a small box for unfiltered stick position.

On the right is the options you have for the recording, as well as a list of any buttons pressed at the time of the currently highlighted sample.
You can select from various stickmaps, choose which stick's motion to record, and scroll through the samples to see info at any recorded point of time.

At the bottom you can see the coordinates of the currently highlighted sample.

### Stickmaps

You can choose to overlay the stick motion on various stickmaps from Melee.

The regions on the edge of the Melee unit circle are extended out to edge of the full controller output space.

Labeled stickmaps courtesy @venus23gg; stickmaps created using Altimor's Melee Stick Coordinate Visualizer.

#### None

Self-explanatory: you only see the stick motion itself.

#### Deadzones



This shows you the Melee deadzones.

It may be useful for practicing SDI.

#### Wait Attacks



This shows you the stickmap for A attacks while standing in wait on the ground.

Here's a labered image of this stickmap, although the PhobVision version is made symmetrical:



#### Wait Movement



This shows you the stickmap for movement while standing in wait on the ground.

Here's a labeled version of it:



#### Crouch



This shows you the stickmap for movement while crouching.

Here's a labeled version of it:



This is particularly useful for practicing dashback out of crouch (DBOOC).

Hold the stick down and then press Start to begin recording, then roll the stick to horizontal as quickly as you can.

Check how long you spend in the lower "Remain in crouch, but if you stay here longer than 1f, Dash fails" zones.
If you spend more than 17ms (1 frame), there's a chance your DBOOC will fail.
If you spend more than 33ms (2 frames), then you're guaranteed to fail.

If you play on UCF 0.80 or prior, if you get unlucky and get polled by the console in the narrow bright lower diagonal regions at all, your dash will fail.
On UCF 0.84 and later, those regions are effectively included in the region where you cannot stay for more than 1 frame.

#### Left and Right Ledge





This shows you the stickmap for options while hanging from ledge (and the horizontal deadzone for your airdodge afterwards).

Here's a labeled version of it, ignoring the deadzones:



This is useful for practicing ledgedashes.

Check your filtering settings and muscle memory for inputs to make sure you spend 17 ms or more in "Ledgedrop" before inputting forward, before inputting a jump button.

## Value vs Time Plots

The Value vs Time Plots let you record 200 milliseconds of one axis of stick or trigger motion and plot it against time.
The output values are plotted as a solid white line while unfiltered raw values are individual dots.

It also provides additional information based on what it was trying to record.

Use the left and right on the D-pad to choose between options and up and down on the D-pad to change the options.

Simply move the stick in a way relevant to the measurement type to trigger recording.
However, if you have the cursor on the Highlight Sample # option, you must manually tell it to wait for motion by pressing the Start button.
(This is a technical limitation due to how it records a looping buffer to save data from before the triggering action.)

### Snapback



This is only available for stick axes.

This triggers when the unfiltered stick axis goes >80 one way and then falls below 23.

The graph shows lines just outside the Melee deadzones, ±23.

As long as you held it on one side long enough before letting go, the percents to the right of the graph will tell you the chance that the last input would be on each side (relevant for turnaround B).

### Dashback



This is only available for stick axes.

This triggers when the unfiltered stick axis exceeds 23 on either side.

The graph shows lines just outside the Melee deadzones, ±23, and right at the dash threshold, ±64.

The percents on the right tell you the chance of successful standing dashback in vanilla Melee.
The shorter the time the stick output spends in the range 23-63 inclusive, the less likely a standing dashback is to fail on vanilla Melee.

### Pivots



This is only available for stick axes.

This triggers when the unfiltered stick axis goes from 80 on one side to 80 on the other side.

The graph shows lines at the Melee dash threshold, ±64.

The percents on the right tell you the chance of not turning, empty pivoting, or fully dashing the other way.

For a 100% chance of an empty pivot, you want to be past the dash threshold for exactly 1 frame, or just under 17 milliseconds.
Shorter than that, and there is a chance of not turning at all, while if you hold longer than 17 and less than 33, you might fully dash the other way.
If the stick output is past the dash threshold for more than 33 ms, you are guaranteed to dash the other way.

### Trigger



This is only available for L or R.

This triggers when either the analog output reaches 43 or the digital press is activated.

The graph shows a gray line at the Melee lightshield threshold, 43.
That line turns white whenever the output is greater than or equal to 43.

When the digital press is active, a white horizontal line is drawn at 100.

The percents on the right tell you the chance that this input would be polled as a digital powershield, an ADT (analog-digital transition) powershield, or no powershield at all.

In Melee, an ADT powershield leaves you vulnerable to physical attacks but is occasionally helpful for powershielding projectiles; it occurs when you are polled with an analog shield

## Button Timing Viewer

The Button Timing Viewer lets you record 200 milliseconds of digital button state and whether each analog axis is past a configurable threshold.



Press Start to begin a recording, or turn Auto-Repeat On to make it so you don't have to keep pressing Start.

The graph shows bars for any digital input held at any given time, or any analog input above the set thresholds.

The numbers at the right indicate timings.
For the button that initiated recording, this is how many frames the input was held.
For any other buttons that were pressed, this is how many frames after the first input they were pressed.

The background lines indicate roughly frame spacing.

You can use this to practice things like frame 1 short hop nair (top image), wavedash timing (below), JC grabs, and more with sub-frame feedback precision.



## Reaction Time Test

The Reaction Time Test is one of the most bare metal reaction time testers you can get, when used on a CRT.



Press Start and then wait until the white square appears, then press any button or move the sticks.
You can adjust the stick or analog trigger thresholds if you want.

It's not 100% accurate in an absolute sense, because I don't know exactly when the recording starts relative to drawing the white square, but it should be extremely precise and repeatable because the measurement is started in perfect sync with the drawing.

# Games

Nothing to see here yet, sorry... maybe next version?

# Phobvision Configuration

Some CRTs, especially high-end ones like Sony PVMs, show PhobVision with incorrect interlacing spacing.

Press up or down on the D-Pad to get the diagonal lines to be as smooth as possible on average across the whole screen to get the best image quality.

Default configuration on a finicky CRT:



Good configuration:



Very bad configuration:



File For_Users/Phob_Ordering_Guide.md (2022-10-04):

# PhobGCC Version 1.2.3 Ordering Guide

This is an illustrated guide to acquiring all the parts you need to assemble a PhobGCC.

# Required Parts

The following parts are unique to the PhobGCC and must be acquired via this guide, with no non-identical substitutions.
* 1 PhobGCC v1.2.3 Board
* 1 Teensy 4.0
* 4 Hall Effect Sensors
* 30 Low Profile Header Pins
* 4 Magnets
* High Viscosity Glue
* Optional: 4x D-pad Buttons
* Optional: 6x Mouse Buttons for ABXYLR

The following parts are standard to a GCC and can be acquired via a number of different ways, some of which will be outlined here.

* 2 Stickboxes
* 2 Trigger Potentiometers
* 1 Cable with a GCC Plug
* Rumble Bracket
* Z-button Switch
* Optional: Rumble Motor

# Purchasing the PhobGCC Board

There are two main ways to acquire a PhobGCC Board. The first way is if you intend to only build a single controller, you can contact a local modder in your region using [this map](https://www.nojonsmods.com/moddermap) to see if they have spare for sale. Alternatively, you can also check [Etsy](https://www.etsy.com/) or [eBay](https://www.ebay.com/) as some often appear for sale. If you cannot find a single board for sale or you intend to build more than one PhobGCC, you can order the boards directly from a board house. The one outlined here will be for [JLCPCB](https://jlcpcb.com/).

First, you can download the files available in the [PhobGCC-HW Github](https://github.com/PhobGCC/PhobGCC-HW/releases) in the releases section as shown below:

PHOB_HW_FILES

Once you've extracted the files from the .zip, you should have three files. The Gerbers .zip, the bom.csv, and the top-pos.csv. Click "Order Now" on JLCPCB, click "Add Gerber File", and upload the Gerbers.zip. Once the files are uploaded, you should see the board load in as shown below:

PHOB_BOARD

Once you've checked that the size is set to 91.41x147.63mm, you can progress with configuring it. The recommended settings are the defaults, plus setting your board quantity, setting "Different Design" to 4, and setting the Surface Finish to ENIG, as seen below:

PHOB_SETTINGS

Scroll down to PCB Assembly and toggle it on the right. Select the top side and Economic PCBA Type (Not available for large orders or colors) as seen below:

PHOB_ASM

Click "Confirm" and then upload the bom.csv to the left and and the top-pos.csv to the right. Set the usage description to Research -> DIY and click "Next". The next screen should look like the following below with all 10 confirmed. If they are not confirmed, stop ordering and ask in the [PhobGCC Discord](https://discord.gg/yrpUu7mgzm).

PHOB_PARTS

After clicking "Next", you'll be presented with a view of the parts on the board. If this screen is corrupted, that's okay. The files are known good and this is just the website bugging out. You want to make sure there are no red boxes anywhere as those indicate missing components. You can then click "Save To Cart" and pay for your boards.

# Purchasing Other PhobGCC Parts

The remaining parts can be purchased from distributers as listed below:
* Teensy 4.0:
  * **NOTE: Most likely out of stock. Ask in the discord**
  * [PJRC](https://www.pjrc.com/store/teensy40.html)
  * [Digikey](https://www.digikey.com/short/93vqqmzm)
  * [Mouser](https://www.mouser.com/ProductDetail/SparkFun/DEV-15583?qs=bZr6mbWTK5kognUaBX05Cg%3D%3D)
  * [Sparkfun](https://www.sparkfun.com/products/15583)
  * [Adafruit](https://www.adafruit.com/product/4323)
* Hall Effect Sensors:
  * **NOTE: For the magnets listed in this guide using the height in the PhobGCC Build Guide, there is no difference between low and high sensitivity sensors**
  * [Digikey Low Sensitivity](https://www.digikey.com/short/8z9r4943)
  * [Digikey High Sensitivity](https://www.digikey.com/short/5qqfr2qh)
  * [Mouser Low Sensitivity](https://www.mouser.com/ProductDetail/Texas-Instruments/DRV5053CAQLPGM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)
  * [Mouser High Sensitivity](https://www.mouser.com/ProductDetail/Texas-Instruments/DRV5053EAQLPG?qs=U0ECReq1GB%2FEJedkxMZGLA%3D%3D)
* Low Profile Header Pins:
  * **NOTE: The main requirement is that the pitch mating is 2.54mm and that the insulation height is 1.52mm. Any headers of this specific size will work. NORMAL ONES WON'T**
  * [Digikey](https://www.digikey.com/short/qmwbq233)
* Magnets:
  * [DH1H1 Magnets](https://www.kjmagnetics.com/proddetail.asp?prod=DH1H1) - For a jack-of-all trades, use these.
  * [D12 Magnets](https://www.kjmagnetics.com/proddetail.asp?prod=d12-n52) -For best control at the rim (like Pivots), use these.
  * [N30H Magnets](https://www.digikey.com/short/br3n8hz3) -For best control at the center (like ICs desyncs), use these.
* High Viscosity Glue:
  * [Gorilla Glue](https://www.amazon.com/dp/B00OAAUAX8)
  * [Epoxy](https://www.mcmaster.com/66195A13/)
* Optional D-pad Buttons:
  * [Low Actuation Force](https://www.digikey.com/short/q4r0jh3j)
  * [High Actuation Force](https://www.digikey.com/short/dcddr0jr)
  * [Teflon Tape For Support](https://www.mcmaster.com/76475A51/)
* Optional Mouse Buttons for ABXYLR:
  * [SMD Pads](https://www.digikey.com/short/v93wrw12)

# Purchasing Other GCC Parts

The GCC-specific Parts have a few different methods of acquisition
* Stickboxes
  * T3 GCCs as per [this guide](https://gccontrollerlibrary.com/guides/gamecube-controller-stamps-guide/)
  * Official Wii Classic and Wii Classic Pro Controllers
  * Sold Loose on [Etsy](https://www.etsy.com/)
* Trigger Potentiometers
  * Official Wii Classic Controllers (No Handles)
  * [Kadano Etsy Shop](https://www.etsy.com/shop/Kadano?ref=simple-shop-header-name&listing_id=1187350029) - if in stock
* Cable with a GCC Plug
  * Any GCC
  * Alibaba Cables
  * [Liquid Cable](https://firescc.com/diy-custom-cables)
* Rumble Bracket
  * Any GCC
  * [Wumble](https://github.com/wavtype/wumble)
  * [FIRESCC](https://firescc.com/mod-guides#/rumble-bracket)
* Z-button Switch
  * Stock - Any GCC
  * Tactile - Official Wii Classic Controllers (No Handles)
  * Tactile - [BattleBeaverCustoms](https://battlebeavercustoms.com/products/replacement-gamecube-tactile-z-switch)
  * Tactile - [FIRESCC](https://www.etsy.com/listing/753452766/fires-performance-mod-kit-for-the?)
  * Tactile - [Digikey](https://www.digikey.com/short/hp5vvv7w) **NOTE:  NEEDS SOME MODIFICATION OF CONTROLLER**
  * Mouseclick - [SimpleControllers](https://simplecontrollers.bigcartel.com/mouseswitch-z)
* Optional Rumble Motor
  * Any GCC
  * [Cellphone Rumble](https://www.amazon.com/10-Pieces-Vibration-Motor-Vibrating/dp/B00N9J3BTG)

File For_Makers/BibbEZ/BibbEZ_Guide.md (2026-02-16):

# BibbEZ installation guide

This is a guide for installing the BibbEZ shell-mount mouseclick Z bracket.

BibbEZ bracket

## Bracket

Download an FDM-ready 3D-printing model [here](https://www.printables.com/model/721075-bibbez-with-designed-support).

Print it with 0.2mm layers, 100% infill, and only one perimeter wall.

If you're using Cura to slice, turn on "experimental bridge settings" or it won't print properly.

## Switch

Use two-pin through-hole mouse microswitches.

You can get them [here on Aliexpress](https://www.aliexpress.us/item/3256807067621726.html).

Others may work but you need to verify that the dimensions are identical.

## Parts you'll need

Parts laid out

1. JST-PH 2.0 through-hole perpendicular connector and pigtails with the wires cut about 0.75 inches (20mm) long
2. 28 AWG magnet wire, one 4.00 inches long (102mm) and one 4.25 inches long (108mm).
3. Printed BibbEZ bracket
4. Two-pin mouse microswitch
5. Heatshrink

## Assembly

### Strip, flux, and tin the wires.

Stripped wire ends

This is fairly straightforward for the JST pigtail.

For magnet wire, you need to burn off the coating using your soldering iron.
Dip the tip of the magnet wire in flux paste, and put a large blob of solder on the tip of your iron.
Hold the cut tip of the wire where the copper is exposed in the blob of molten solder.
This will produce nasty fumes, so use proper ventilation and/or breathing protection.

### Bend the switch pins

Bent switch pins

Bend the switch pins to the side, fairly flat against the back of the switch.

Make sure you bend it in the correct direction. It should match this.

### Trim the switch pins

Trimmed switch pins

Use robust cutters to cut the switch pins flush with the side of the switch.

This is to help make it easier to insert the switch into the bracket.

### Solder magnet wire to switch

Switch with wires

Solder the shorter wire to the left pin, as seen in this photo.

### Prepare BibbEZ bracket

BibbEZ bracket

Trim the support wall off the front of the bracket using flush cutters.

Trimmed BibbEZ bracket

### Install switch in bracket

Wires bent on switch

Gently bend the wires to face away from the switch. They ideally do not protrude past the side of the switch.

Insert the wires into the slots in the BibbEZ bracket and slide the switch in.

BibbEZ bracket with switch

### Bend wires to equalize length

Bent wires on BibbEZ bracket

Bend the wires towards the side with the nub to make their ends line up.

### Insert heat shrink over wires

Heat shrink on wires

Put heat shrink over the wires so that you can cover up the solder joints later.

Use thin ones for each wire and one thick one over both wires together.

### Solder wires to JST pigtail

Wires soldered to pigtail

### Shrink small heatshrink tubes

Shrunken small heatshrink tubes

### Shrink large heatshrink tube

Shrunken large heatshrink tube

### Install JST socket in motherboard

First, tin the secondary Z hole on the PhobGCC 2.0.5  motherboard that has a round pad.

Tinned Z hole

Then heat the pad from the front of the motherboard while inserting the JST socket (installed on a pigtail) from the rear side.

JST partially soldered

Then solder the other pin and finish tinning the first pin.

Fully soldered JST

### Install BibbEZ in shell

Orient the BibbEZ bracket like this:

BibbEZ next to shell

Slide the BibbEZ onto the post between the X and Y buttons on the front shell.

BibbEZ in shell

The button pad will not fit as-is...

Button pad over BibbEZ

So trim it to fit over the bracket.

Trimmed button pad around BibbEZ

Remove the spring from the Z button and make sure that the little nub contacts the switch plunger.

Third party Z button caps might not work properly with BibbEZ.

Z button plunger and mouse switch

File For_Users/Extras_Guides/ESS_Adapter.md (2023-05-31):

# ESS Adapter Guide

This is a guide for enabling ESS Adapter functionality for the PhobGCC.

# Prerequisites

As with all Extras, it must be built into the firmware and enabled by first
following the [Extras Guide](/For_Users/Extras_Guides/Phob_Extras_Guide.md).

# Overview

In Ocarina of Time for the WiiVC, the default mapping for the control
stick is notoriously tragic. This is an Extra that utilizes the control
stick mapping LUT (Lookup Table) from [Skuzee's ESS Adatper](https://github.com/Skuzee/ESS-Adapter)
to provide a more natual control stick mapping that closely resembles what it
would feel like playing on a Nintendo 64.

# Toggling and Configuring

### Toggling 
When enabled, the control stick will have the LUT applied. __This will look weird in smashscope__, 
but this is how it's supposed to look as these control stick values map to a more natural
experience when playing Ocarina of Time on WiiVC. 

When disabled, the PhobGCC will not apply the LUT and mapping will not be affected.

### Configuring
As of now, there are no configuration options as the mapping is a fixed LUT.

# Troubleshooting

If you have any issues enabling this Extra, please refer to the PhobGCC Discord's tech support.
[PhobGCC Discord](https://discord.gg/yrpUu7mgzm)

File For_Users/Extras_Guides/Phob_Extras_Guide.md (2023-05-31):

# PhobGCC Extras Guide

This is a guide to enabling Extras, community-created features that require to be manually enabled in the PhobGCC firmware.

# Prerequisites

* The ability to flash the PhobGCC firmware normally by following the [Phob Programming Guide](/For_Users/Phob_Programming_Guide.md).

# Directional Configurations

When enabling an Extra, it must be assigned to one of 4 cardinal directional 
configuration slots to toggle the feature and and configure its settings. 

The two button combinations that are used to toggle and configure Extras are:

* Toggle: A + B + Analog and C-Stick pointed Up/Down/Left/Right
* Configure: A + Dpad + Analog and C-Stick pointed Up/Down/Left/Right

Do note that since toggling and configuring Extras is a part of general configuration, they only function if you are not in safe mode.

For configuration, each dpad direction can be used to configure the Extra, but it's up to each Extra's
implementation to determine how it uses each direction of the Dpad. Please refere to the documentation
of the Extra you wish to enable to see how to configure it (if the Extra uses configuration).

# Enabling Extras

## Opening extras.h

Navigate to the folder where you downloaded the PhobGCC firmware, you should
see three folders along with the 'PhobGCC.ino' project file.



Open the 'extras' folder and there should be a file named 'extras.h' inside.

Open it by right clicking it and opening it with Notepad or a text editor of choice.



## Enabling an Extra

Look at the top of the document for the following section:

```c++
/* Plugins and extra features outside the normal scope of
 * the PhobGCC can be found here. Uncomment each #define
 * to include the features they provide in a build then
 * set the configuration slot it uses (if it needs configuration)
 * 
 */
//------------------------------------------------------
//#define EXTRAS_ESS
//------------------------------------------------------
```

Here there is a list of Extras you can enable. Currently we only support one, 
which is ESS functionality for Ocarina of Time for WiiVC, but with time there
will be more to pick from.

Find the Extra(s) you wish to enable, then delete the `//` that comes at the
start of the line that looks like: `//#define EXTRAS_EXAMPLE`. 

If I wanted to enable the ESS Extra, my 'extras.h' would look like this:

```c++
/* Plugins and extra features outside the normal scope of
 * the PhobGCC can be found here. Uncomment each #define
 * to include the features they provide in a build then
 * set the configuration slot it uses (if it needs configuration)
 * 
 */
//------------------------------------------------------
#define EXTRAS_ESS
//------------------------------------------------------
```

## Setting an Extra's Configuration Direction

Next, you will need to set the configuration direction for the Extra. 

Scroll to the bottom of the file until you find the configuration block
related to the Extra you wish to enable.

For example, the ESS Extra looks like this:

```c++
#ifdef EXTRAS_ESS
	//-----------------------------------------
	ess::extrasEssConfigSlot = EXTRAS_UNSET;
	//-----------------------------------------
	Serial.println("Extra: Enabling ESS functionality...");
	extrasConfigAssign(ess::extrasEssConfigSlot, ess::toggle, NULL);
#endif
```

Look for the config slot direction for the Extra you enabled and replace `EXTRAS_UNSET` 
with one of: 

* `EXTRAS_UP`
* `EXTRAS_DOWN`
* `EXTRAS_LEFT`
* `EXTRAS_RIGHT`

You can only have one Extra per direction, for a total of 4 Extras enabled maximum.

If I were to set the ESS Extra to Sticks Down, the code would then look like this:

```c++
#ifdef EXTRAS_ESS
	//-----------------------------------------
	ess::extrasEssConfigSlot = EXTRAS_DOWN;
	//-----------------------------------------
	Serial.println("Extra: Enabling ESS functionality...");
	extrasConfigAssign(ess::extrasEssConfigSlot, ess::toggle, NULL);
#endif
```

If you leave the configuration direction unset, you **will not** be able to toggle or configure
the extra you enabled!

When you are finished, save extras.h and re-flash the firmware by using the Arduino Software.

# Toggling and Configuring an Extra

Once you've finished flashing your PhobGCC with the Extra-enabled firmware, you can then 
toggle and configure the Extra you enabled (assuming you're not in safe mode) by using the button combinations listed at the
start of this document and following the configuration guide for the Extra you enabled.

# Troubleshooting

If you have any issues enabling Extras, please refer to the PhobGCC Discord's tech support.
[PhobGCC Discord](https://discord.gg/yrpUu7mgzm)

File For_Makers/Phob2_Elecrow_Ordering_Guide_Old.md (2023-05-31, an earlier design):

# PhobGCC Version 2.0.5 Elecrow Ordering Guide

This is an illustrated guide to ordering PhobGCC PCBs via the Elecrow Board House. Elecrow's boards are significantly higher quality, have less manufacturing issues, and are tested before arrival, so you won't receive non-functional boards. As such, they are the recommended option when it comes to ordering PhobGCC boards.

# Elecrow Ordering Process Overview

1. Download the files.
2. Edit the specification spreadsheet to list your quantity, board color, and text color.
3. Email files to Elecrow PCB Assembly service.
4. Upon quote arrival, you pay for your boards and reply with the order number.
5. Once the boards are assembled, you will receive photos for inspection. Reply that they're fine and they will ship.

## Purchasing the PhobGCC v2.0.5 board from Elecrow

Download the files available in the [PhobGCCv2-HW Github](https://github.com/PhobGCC/PhobGCCv2-HW/releases/tag/v2.0.5) in the releases section as shown below:

PHOB2_ELECROW_BOARD_RELEASE

Once you've extracted the files from the .zip, you should have two files. The Phob2_Gerbers .zip and the Elecrow Info Excel spreadsheet. Open up the spreadsheet and you should see in the PCB Specification sheet as follows:

PHOB2_ELECROW_BOARD_OPTIONS

Here is where you'll want to set your board quantity, PCB color, and text color. You can see the exact settings availability on [Elecrow's website](https://www.elecrow.com/pcb-manufacturing.html), but for a short hand you can set board quantities to be 5, 10, 15, 20, 25, 30, 40, 50, 75, and 100. For PCB Color, you can choose between Green, Red, Yellow, Blue, White, Black, Purple, or Matte Black. If, and only if, you order White or Yellow PCBs, you need to change the text color from white to black. Once you have your specifications set, save the file, close it, and re-open it to ensure it saved properly.

You can then draft an email to the Elecrow PCB Assembly Service requesting a quote on how much it would cost to manufacture your boards. You can use the template as follows:

```
Hello!

          I was told to contact you about your PCB Manufacturing and Assembly services. I am inquiring about a quotation of how much it would cost to produce the following project. Attached are all files as requested by your website.

Testing Plan: Plug Micro-USB into computer and it should be recognized as a mass storage device (such as USB Drive).

Note: Please ensure the proper polarity of the Diodes (D1, D2, D5) and the Polarized Capacitor (C1). I have labeled in red the correct polarity for the diodes and the ground side for the capacitor in the parts mapping tab.

Shipping Method: DHL

Shipping Address:

[INSERT YOUR ADDRESS HERE]

-Thank you for your time
--[INSERT YOUR NAME HERE]
```

Attach the Gerbers .zip and the spreadsheet to the email. Title it "PCB Assembly Quotation" and then email it to service@elecrow.com

In 24-48 hours, they will reply with an excel spreadsheet containing the results of your quote. On the Total Page at the bottom will be the final cost. If this cost is acceptable to you, you then proceed to the [Elecrow website for PCB assembly](https://www.elecrow.com/pcb-assembly.html). On here, set the name of the person who emailed you your final cost as the Project Manager name and set the "Qty" as the final cost rounded up to dollar. You can See examples below:

PHOB2_ELECROW_BOARD_COST

PHOB2_ELECROW_BOARD_CHECKOUT

You can then click "Add To Cart", and proceed to checkout. Once you have checked out, you need to make a note of the order #. This will appear on screen immediately, but if you forget, you can check your email for a receipt from Elecrow. You then need to reply to the quotation email with the order number. You can use the template below:

```

Hello,

I have placed the order, my order number is ######.

-Thank you for your time
--[INSERT YOUR NAME]

```

And you are done! In 3-4 weeks you will receive an email with photos of the finished boards. You can view them to see if everything came out cleanly, then reply saying that they are fine and to ship out your order. In 24-48 hours, you will receive another email containing shipping information, including tracking.

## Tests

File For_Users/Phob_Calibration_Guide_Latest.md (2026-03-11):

**NOTE: This is for firmware version 0.31.**

For older versions, use the appropriate calibration document [from here](../LEGACY.md).

For later development versions of the software that have not yet been released, search for “Current Commands List” in the `common/phobGCC.h` file to see the commands for that version as they may have changed.

**NOTE 2: The controller starts in safe mode! To make any changes you must disable it first!**

We strongly recommend using GCC Test Suite (GTS) either on a Wii or vanilla Dolphin for all of this. Slippi will not run GTS.
You can get GTS [from here](https://github.com/greenwave-1/GTS/releases/latest).

Previously we recommended SmashScope and Uncle Punch Training Mode 3.0 (now Training Mode Community Edition), but it is much easier to verify correct calibration on GTS.

# PhobVision

If you have a PhobGCC 2 with PhobVision installed and a CRT available, it's highly recommended to calibrate and configure using PhobVision.

PhobVision has menu options for all of these settings, and it walks you through the stick calibration process to minimize the chance of user error.

To use PhobVision, plug a 3.5mm TRRS to RCA cable compatible with Sony camcorders into the jack on the controller and the composite video input on a CRT television, hold Z on the controller, and plug the controller's GCC cable into a powered-on console or adapter.
Navigate with the D-pad, select an item by pressing A, and back out by holding B. 

Some menu pages are not complete yet, and on these you will be greeted by an "Under Construction" sign.

Full PhobVision manual available [here](/For_Users/Phobvision_Guide_Latest.md).

# Initial Setup

Do this if the controller has never been calibrated before, or if it has been flash nuked or hard reset.
If the controller is functioning normally, this has already been performed and you do not need to repeat the full process.

## Wii Initial Setup

* Turn on the Wii.
* Plug in the controller.
* Start GCC Test Suite.
* Navigate to Controller Test (using the D-Pad).
* Tap B (do not hold) to initialize the sticks.
* Verify that the Origin XY and C-Origin XY are both (-001, -001).

## Dolphin Initial Setup

* Install the latest Dolphin emulator (do not use Slippi Dolphin).
* Set up the controller menu so that Port 1 is GameCube Adapter for Wii U.
* Plug in the controller. DO NOT PRESS B.
* Begin emulation (run GTS_GC.dol).
* Navigate to Controller Test (using the D-Pad).
* Tap B (do not hold) to initialize the sticks.
* If using an OEM or Mayflash adapter or older Lossless adapters, verify that Origin XY and C-Origin XY are both (-1, -1). If using a HHL GC Pocket adapter or a newer firmware version of Lossless, the origins should be zero.

## Controller Setup
* Verify that the sticks are both pointing slightly up and to the right. At neutral, they should be somewhere in the range of 0.3 to 0.6. When moved, they should respond very slightly, going in all four directions. If this is not the case, there is a hardware problem that must be resolved before proceeding with calibration.
* Toggle off Safe Mode by holding **AXY+Start** for until the sticks jump to the extreme top right, then immediately letting go.
* Calibrate the left analog stick with **AXY+L**, following [this procedure](#analog-stick-calibration---axyl). The left stick should now behave normally.
* Calibrate the right analog stick with **AXY+R**, following [this procedure](#C-Stick-calibration---axyr). The right stick should now behave normally.
* Adjust snapback filtering to reduce snapback to roughly 20 or less in each direction. If snapback won't be fully corrected at maximum filtering strength, add some thick silicone grease into the stickbox to slightly reduce the unfiltered snapback to within the range of the snapback filter.

# Activating the Analog Sticks - B

* After plugging in the controller, press **B** to activate the analog sticks. Before this, the sticks are hardcoded to be centered so that the game properly zeroes.
* If you are playing using Dolphin/Slippi, you must first have Dolphin running, then have the controller plugged in before starting the game.
  * By enforcing that the sticks are centered when starting the game, this ensures that you get 1.0 cardinals and accurate notches.
  * If you are using a Mayflash adapter, you must plug in both USB connectors for the controller to register in Dolphin/Slippi.
* This is necessary because if the sticks are miscalibrated, it will be very difficult to correctly calibrate them with the sticks incorrectly zeroed.
  * Once the sticks are calibrated and you are sure they are reliably zero when released, you can disable this. See [here](#toggle-auto-initialize---axyz).
  * But each time you reset or calibrate, you will once again be required to press B.

# Making Changes On PhobGCC

* **All commands use the physical buttons specified, regardless of any remapping that has occurred**.
  * L and R buttons must have electrically functional digital press, regardless of trigger modes that disable the digital press.
* Most of the time, when you give the PhobGCC a command, the Analog Stick and C-Stick will freeze pointing to the top right 127/127.
  * For binary commands, it'll hold for two seconds.
  * For numerical values, it'll hold for 0.75 seconds to make it faster to change.
  * For trigger offsets, which have a wide numerical range, it will only hold for 0.1 second.
* If you're in Melee without input visualization tools, you will see your character roll to the right to indicate this, or you'll see the menu tilt due to the C-Stick.

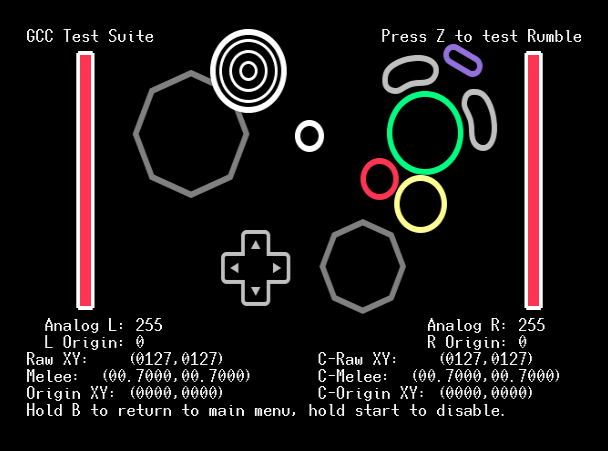
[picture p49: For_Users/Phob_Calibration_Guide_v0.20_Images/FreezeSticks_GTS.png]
Sticks pointing up and to the right, triggers pressed


# Safe Mode/Configure Mode Toggle - AXY+Start

The controller begins in Safe Mode, where the only command that works is this toggle, in order to prevent accidental settings changes.

To make any changes to the controller configuration, activate this toggle to enter Configure Mode.

* To enter Configure Mode, you have to hold the key combination for about 1 second, to prevent accidental activation.
  * Turning Safe Mode back on has no delay.
* As a reminder, all commands including this one utilize the hardware buttons specified, regardless of remapping.
* Even if you haven't pressed B, this will wake up the sticks. It responds instantly if the sticks haven't activated yet, due to an implementation quirk.
* When you enter Configuration Mode, the controller freezes for 2 seconds.
* When you turn Safe Mode back on (you can no longer configure), the controller freezes for 4 seconds to distinguish. You can also just unplug and plug the controller back in to ensure that you are back in Safe Mode.
* If either L or R digital is active, this command will not work (to prevent safe mode toggling when doing PM salty runback).

# Display Software Version - AZ + Du

* The C-Stick will display the software version in raw units as if it were not preceded by the "0."
  * The Y-axis will show the tens and ones digits. In this case, it would be 31.
  * The X-axis will show the thousands and hundreds digits. In this case, it would be 0.
* You must use GTS to see this numerically.
* If the controller doesn't show 31, then you need to reference an older configuration document [here](../LEGACY.md).
  * If it doesn't respond to this command at all, then it's likely the version is 0.23 or lower and you should [upgrade the controller firmware](/For_Users/Phob_Programming_Guide.md).

# Controller Reset - Hold ABZ then press Start

* **Use this if you are upgrading from an older software version or have messed up your settings in some way.**
* **You need to turn off Safe Mode in order to reset.**
* This will reset all the controller settings except for stick calibration. This includes snapback filtering, waveshaping, analog delay, offsets, and button remapping.
* There is a hidden hard reset option that will also erase the stick calibration, but we are not publishing the button combination because it's unhelpful almost all of the time. Ask the devs in the Discord what it is if you really need this.

# Toggle Auto-Initialize - AXYZ

* When you turn this on, both sticks will briefly point up and to the right. When you turn it off, both sticks will briefly point down and to the left.
* If you are positive that both of your sticks are calibrated well, you can use this to avoid the need to press B when plugging the controller in.
* If calibration ever gets wonky, you need to disable this, then recalibrate.
* This automatically gets turned off when you:
  * Recalibrate: if you mess up the calibration then the controller won't initialize correctly and it'll be hard to calibrate properly
  * Reset: if you reset it returns everything to defaults including this setting.

# Rumble Strength Configuration - AB + Du/Dd

* Rumble is only available on boards version 1.2 or later. This command will do nothing for earlier boards.
* Press **AB** + **D-pad Up/Down** to increase or decrease the rumble strength.
* There are settings from 0-11.
  * 9 is roughly equivalent to an OEM controller's rumble.
  * 0 turns off rumble entirely.
* Press **AB+Start** to show the current rumble setting on the C-Stick.

# Tournament Toggle Configuration - Z + Start + D-pad Up

This command was changed in version 0.31 to prevent accidental activation.

* Tournament Toggle reduces the chance of misinputs of either Start or D-Pad Up (taunt) during gameplay.
* Press **Z + Start + D-pad Up** to switch to the next mode. The mode will be shown on the C-Stick.
* There are 6 different modes, ranging from 1 to 6.
  * Mode 1: Default behavior: both buttons respond immediately.
  * Mode 2: D-Pad Up must be held for 1.5 seconds to activate.
  * Mode 3: D-Pad Up is disabled entirely.
  * Mode 4: Start must be held for 1.5 seconds to activate.
  * Mode 5: Start and D-Pad Up both must be held for 1.5 seconds to activate.
  * Mode 6: D-Pad Up is disabled entirely and Start must be held for 1.5 seconds to activate.
* You can bypass the lockout or delay. For D-Pad Up, holding D-Pad Up and then pressing Start will output only D-Pad Up. For Start, holding Start and pressing D-Pad Down will output only Start.

# Raw Stick Output - L+R+Du/Dd

This command is new in version 0.31.

Raw stick output isn't a setting, but a temporary mode that helps diagnose stick issues.
Instead of the remapped stick output, it shows the unprocessed sensor values in a range from 0 to 100.

Enable it with **LR** + **D-pad Up** and disable it with **LR** + **D-pad Down**.

Alternatively, if you hard reset the controller (or have never calibrated it before) any uncalibrated sticks will default to raw stick output.

With the sticks centered, Phob 2s and some Phob 1.2s should be close to 50. Phob 1.1s and most Phob 1.2s should be roughly 30.

When you move a stick horizontally or vertically, the raw output should change only in that axis by at least 10 in each direction.

If this isn't the case, then the hardware likely needs some sort of repair.

# Analog Stick Calibration - AXY+L

Before calibrating, you must check that the Origin XY and C-Origin XY are both (-001, -001). For newer Lossless and GC Pocket+ adapters, they should both be 0.

If you suspect something is wrong with the controller you must verify that the sticks are working electrically. To do so, put the controller into Raw Stick Output mode and verify that the sticks are centered roughly on +30 or +50, and are sensitive enough to stick motion in all axes. When you move the sticks in a circle around the gate, they should move in a small circle onscreen.

[Basic PhobGCC Analog Stick Calibration - YouTube](https://www.youtube.com/watch?v=rkgtqwIE8Iw)

[PhobGCC Analog Stick Calibration Guide - YouTube](https://www.youtube.com/watch?v=nUbpmkcleF8)

[PhobGCC Notch Calibration Guide - YouTube](https://youtu.be/hscmtzy7dqs)

* Stick calibration has two phases: measurement and notch adjustment.
  * During the Measurement Phase, you have the controller record the physical location of the corners of the gate and any modder-added notches.
  * During the Notch Adjustment Phase, you can tweak the output angles of the notches you measured.
  * You **must** complete both measurement and notch adjustment for the setting to be saved.
* If you’ve already calibrated the stick and just want to adjust notches you have already measured, you can skip the measurement phase and immediately begin notch adjustment by pressing Start at any time during the measurement phase.
* Calibrating either stick turns off Auto-Initialize.

## Measurement Phase

The first phase involves having the controller record the positions of the physical gate corners and notches as calibration reference points.

When in the measurement phase, the C-Stick's output will alternate between the center and a position along the rim, starting with the cardinal directions.

The C-Stick's output shows what notch, if present, you are to measure.

The control stick output will show the output of the previous calibration. Depending on the previous calibration, this may be accurate, inaccurate, freak out randomly, or in the case of an uncalibrated PhobGCC 2.0, it will be mostly pegged to (125,125). The output you see here has no bearing on the results.

* If the C-Stick is centered, let go of the control stick and press either **L**, **R**, or **A** to measure that position.
* If the C-Stick is not centered, **hold the physical analog stick into the notch indicated by the C-Stick's output** and press **L**, **R**, or **A** to measure that position.
  * Make sure to enter the notch from the direction you would during gameplay.
* If you don't have a notch at the position indicated by the C-Stick, **let go of the stick** and press **L**, **R**, or **A**.
* **You must measure all four cardinal directions (East, North, West, South) and all four diagonal directions** or calibration will not work.
* The first time you calibrate a controller that has modder-added notches, it is highly recommended to skip all the modder added notches and start with only the 8 primary directions.
* If you think you messed up a measurement, you can go back to a previous notch measurement by pressing **Z**. It'll go back to measuring the center immediately before a given notch.
* Once you finish measuring all the notches (32 presses of **L/R/A**), the stick should behave normally. **You are not done calibrating.** Proceed to the [Notch Adjustment Phase](#notch-adjustment-phase) below.
  * If it does not behave as expected, see Measurement Phase Troubleshooting below.

### Measurement Phase Troubleshooting

* If the Analog Stick's output is not accurate during this phase, do not worry. The previous calibration does not matter.
* If the C-Stick is not alternating between being centered and circling all the way around the rim, and you are using Dolphin to calibrate, you need to reinitialize Dolphin by making sure that Auto-Initialize is off, unplugging and replugging, restarting Dolphin, and then tapping **B**.
* If after the measurement phase is done, the stick has one or two sectors that jump into another quadrant randomly, you probably mis-measured a notch. Mash **L**, **R**, or **A** a bunch to finish the calibration and start again.
* If after the measurement phase is done, the stick output is completely haywire and jumping all over the place randomly, you may have let go of the stick before pressing **L**, **R**, or **A**. Mash **L**, **R**, or **A** a bunch to finish the calibration and start again.
  * Alternatively, if you have Firefox notches, try calibrating the main 8 directions only to completion, then go back and calibrate all of them.
* If after the measurement phase is done, the stick output is backwards on one or both axes, you probably were trying to make the stick *output* match the C-Stick, instead of moving the *physical* stick into the notch indicated by the C-Stick. Mash **L**, **R**, or **A** a bunch to finish the calibration and start again.

## Notch Adjustment Phase

After the measurements are complete, this phase lets you adjust exactly where the non-cardinal notches are mapped to.

When in the notch adjustment phase, the C-Stick will stay along the rim and rotate along from notch to notch, starting with the diagonals.

This indicates which notch is currently being adjusted.

* The Analog Stick position does not affect notch adjustment. The output is a live preview of how the calibration will be with your given adjustments.
* The C-Stick points at the notch that is currently up for adjustment.
* Press **X** or **Y** to shift the output of the notch clockwise or counterclockwise, respectively.
  * You won't see anything change if you don't put the stick into the notch that's being adjusted.
  * Make sure to enter the notch from the same direction you would during gameplay when checking the output.
* To reset to an undistorted position for the notch, press **B**. The C-Stick will be displaying the position that was measured.
* Press **L**, **R**, or **A** to move to the next notch.
* To go back to a previous notch, press **Z**. You cannot go back to the measurement phase.

When the C-Stick's output returns to center, the stick calibration is now saved.

### Notch Adjustment Troubleshooting

* If your notch coordinates are very inconsistent, try twisting the stick like a knob and see if the origin value shifts. If so, try gently tightening the screws holding the stickbox down; they may be loose.
* If your notch coordinates have slightly different values when approaching straight from center compared to rolling clockwise or counterclockwise along the rim, this is normal (within two or three values).
* If your notch coordinates cannot be adjusted to the desired value, check the C-Stick's coordinates to see if it's too far from the desired value. You can try recalibrating from the start and measuring it again, but it may not help. See a modder to get your notches adjusted if needed.

# C-Stick Calibration - AXY+R

This process is exactly like Analog Stick Calibration, but instead, the Analog Stick moves to show you how to move the C-Stick.

# Analog Stick Smart Snapback Adjustment - A + X/Y + Du/Dd

Increasing the Analog Stick Smart Snapback Filter adjustment doesn’t hurt responsiveness of the stick when moving away from the center. Increasing the value of this filter only makes it return to center more slowly.

* Press **A** + **X/Y** for your axis + **D-pad Up/Down** to increase/decrease.
  * Example: **AX+Du** suppresses X-axis snapback more, **AY+Dd** suppresses Y-axis snapback less.
  * When you change this setting, the current snapback filter settings are shown as the numerical coordinates of the C-Stick.
* The scale goes from -10 to +10, and defaults to 4.
  * 0 completely disables the Smart Snapback Filter. This removes the rise time improvements, hurting dashdancing on the X axis, and you will have snapback.
  * Positive values have strong rise time reduction that promotes fast tilt inputs into smash inputs.
    * Higher values have stronger snapback suppression.
    * 4-10 is equivalent to 1-7 on v0.22-0.23 and 0-6 on v0.21.
  * Negative values are a new filter that minimizes rise time reduction and makes the stick behave more like an OEM controller.
    * More negative values have stronger snapback suppression.
  * Sticks usually need a setting of 4-7. 9+ is for special situations such as metal stick caps or lighter spring weights.
  * If you have an OEM stick cap and snapback is still a problem, try setting the snapback filter to 0 and check how far the snapback goes. If it goes past 70, you may have to tame snapback by adding a bit of grease to the stickbox.
* Press **L+Start** to see the current Smart Snapback filter values on each axis of the Analog Stick.
  * At the same time, you can see the current axis smoothing values on the C-Stick and Waveshaping values on the triggers.

# Analog Stick Waveshaping Adjustment - L + X/Y + Du/Dd

The Waveshaping filter stops the output from moving while the stick axis is moving quickly.
This setting controls the threshold where that transition occurs.

This can be used to make pivots or short flicks behave more like a good OEM controller.
This enhancement to pivots and flicks works best with an OEM spring or a Smalley L2 spring, not with lighter "slickbox" style springs, but you can crank it up and make it work at the expense of responsiveness.

* Press **L** + **X/Y** for your axis + **D-pad Up/Down** to increase/decrease.
  * Example: **LX+Du** strengthens the effect on the X-axis, **LY+Dd** reduces the effect on the Y-axis.
  * When you change this setting, the current Waveshaping filter settings are shown as the numerical coordinates of the C-stick.
* The scale goes from -24 to +24, and defaults to 0.
  * 0 disables Waveshaping entirely.
  * Positive Waveshaping behaves like mild PODE.
  * Negative Waveshaping behaves like strong PODE. Strong negative Waveshaping in combination with zero Smart Snapback suppression this can be used to mimic OEMs that cannot empty pivot while suppressing all snapback. Small negative Smart Snapback can be used to attenuate this effect.
* Press **L+Start** to see the current Waveshaping filter values on the L and R trigger analog values.
  * At the same time, you can see the current Smart Snapback filter values on the Analog Stick and the axis smoothing values on the C-Stick.

# Analog Stick Axis Smoothing Adjustment - R + X/Y + Du/Dd

The Analog Stick Axis Smoothing is just a simple low-pass filter similar to a capacitor on a vanilla Gamecube controller.
Increasing this setting slightly reduces responsiveness.
If you have the Smart Snapback Filter disabled, you can use this to suppress snapback.

* Press **R** + **X/Y** for your axis + **D-pad Up/Down** to increase/decrease.
  * Example: **RX+Du** increases the X-axis Delay, **RY+Dd** decreases the Y-axis delay.
  * When you change this setting, the current axis smoothing settings are shown as the numerical coordinates of the C-Stick.
* The scale goes from 0-18, and defaults to 0.
  * Single-Motion Ledgedashing: ~5 on X-axis and 0 on Y-axis
  * Alternatively, set the Smart Snapback adjustment on the Y-axis to 0 and set the Axis Smoothing to 0 for both X and Y-axes. This gives stronger single-motion ledgedashes but you may experience Y-axis snapback.
  * 9 in versions before 0.31 was changed to 18, adding increased precision between 8 and the former 9.
* Press **L+Start** to see the current axis smoothing values on each axis of the C-Stick.
  * At the same time, you can see the current Smart Snapback filter values on the Analog Stick and Waveshaping values on the triggers.

# Analog Stick Scaling Adjustment - L + A + Du/Dd

The Analog Stick Scaling setting allows the user to adjust what value the stick can reach at the edge of the gate.
Super Smash Bros. Melee has a unit circle that ranges from -80 to +80, OEM Gamecube controllers range from roughly -100 to +100, and the GCC protocol allows for -128 to +127.
The PhobGCC hard limits its own stick outputs to a range from -125 to +125, but this setting corresponds to what you get immediately after calibration.

* Press **L** + **A** + **D-pad Up/Down** to increase/decrease.
  * Example: **LA+Du** increases the value at the rim of the analog stick.
  * When you change this setting, the current analog stick scaling setting is shown as the numerical coordinates of the analog stick.
* The scale goes from 90-110, and defaults to 100.
  * This changes the physical distance to the rim of the Melee unit circle.
  * 100 will behave identically to previous firmware versions that do not feature stick scaling.
  * In 0.31 the adjustment range was reduced to be rules-compliant.
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

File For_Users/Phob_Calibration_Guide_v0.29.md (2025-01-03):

**NOTE: This is for firmware version 0.29.**

For older versions, use the appropriate calibration document [from here](../LEGACY.md).

For later development versions of the software that have not yet been released, search for “Current Commands List” in the `common/phobGCC.h` file to see the commands for that version as they may have changed.

**NOTE 2: The controller starts in safe mode! To make any changes you must disable it first!**

I strongly recommend using Smashscope (either on a Wii or vanilla Dolphin) for all of this. Slippi will not run Smashscope.
You can get Smashscope from the Goomwave website.
When using Smashscope in Dolphin, make sure to **set all Wiimotes to "None" in the Controllers menu** or else the sticks will not display any movement.

An alternative is Uncle Punch Training Mode 3.0. In the Training Lab menu, under General enable “Input Display”, and under Info Display enable “System LStick”, “System CStick”, and “System Trigger” as the first three rows.

# PhobVision

If you have a PhobGCC 2 with PhobVision installed and a CRT available, it's highly recommended to calibrate and configure using PhobVision.

PhobVision has menu options for all of these settings, and it walks you through the stick calibration process to minimize the chance of user error.

To use PhobVision, plug a 3.5mm TRRS to RCA cable compatible with Sony camcorders into the jack on the controller and the composite video input on a CRT television, hold Z on the controller, and plug the controller's GCC cable into a powered-on console or adapter.
Navigate with the D-pad, select an item by pressing A, and back out by holding B. 

Some menu pages are not complete yet, and on these you will be greeted by an "Under Construction" sign.

Full PhobVision manual available [here](/For_Users/Phobvision_Guide_Latest.md).

# Initial Setup

**This is only necessary the the first time the controller is set up after it is made, only if you are calibrating using a console.**
You do not need to do this otherwise, such as if you are calibrating it using PhobVision.

If the controller is functioning normally, this has already been performed and you do not need to repeat the process.

* If using Dolphin, start Dolphin. If using a Wii, turn on the Wii and use another controller to set up your configuration environment.
* Plug in the controller.
* If using Dolphin, start the game (Smashscope or Uncle Punch).
* Toggle off Safe Mode (hold **AXY+Start**). Both sticks should be wonky right now.
* Calibrate the left analog stick (**AXY+L**, follow [this procedure](#analog-stick-calibration---axyl)). The left stick should behave normally now.
* Calibrate the C-Stick (**AXY+R**, follow [this procedure](#C-Stick-calibration---axyr)). The right stick should behave normally now.

# Activating the Analog Sticks - B

* After plugging in the controller, press **B** to activate the analog sticks. Before this, the sticks are hardcoded to be centered so that the game properly zeroes.
* If you are playing using Dolphin/Slippi, you must first have Dolphin running, then have the controller plugged in before starting the game.
  * By enforcing that the sticks are centered when starting the game, this ensures that you get 1.0 cardinals and accurate notches.
  * If you are using a Mayflash adapter, you must plug in both USB connectors for the controller to register in Dolphin/Slippi.
* This is necessary because if the sticks are miscalibrated, it will be very difficult to correctly calibrate them with the sticks incorrectly zeroed.
  * Once the sticks are calibrated and you are sure they are reliably zero when released, you can disable this. See [here](#toggle-auto-initialize---axyz).
  * But each time you reset or calibrate, you will once again be required to press B.

# Making Changes On PhobGCC

* Most of the time, when you give the PhobGCC a command, the Analog Stick and C-Stick will freeze pointing to the top right.
  * For binary commands, it'll hold for two seconds.
  * For numerical values, it'll hold for 0.75 seconds to make it faster to change.
  * For trigger offsets, which have a wide numerical range, it will only hold for 0.1 second.
* If you're in Melee without input visualization tools, you will see your character roll to the right to indicate this, or you'll see the menu tilt due to the C-Stick.

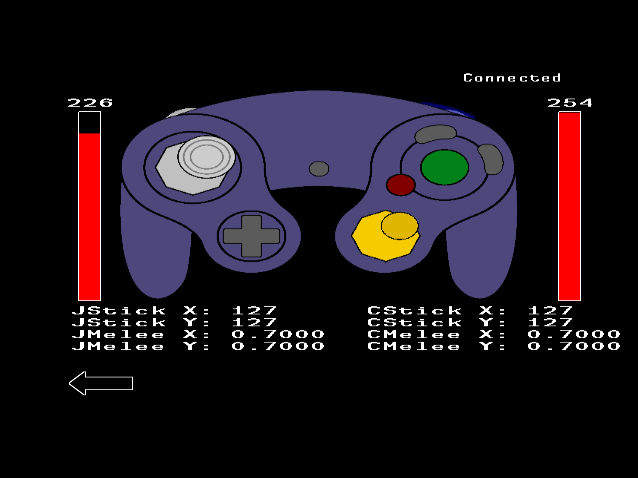
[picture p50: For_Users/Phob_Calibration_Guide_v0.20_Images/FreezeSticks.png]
Sticks pointing up and to the right, triggers pressed


# Safe Mode Toggle - AXY+Start

* To turn off Safe Mode, you have to hold the key combination for about 1 second, to prevent accidental activation.
  * Turning Safe Mode back on has no delay.
* This is required to make any changes on the controller, to prevent you from reconfiguring things during gameplay.
* Even if you haven't pressed B, this will wake up the sticks.
* When you turn Safe Mode off (configuration is possible), the controller freezes for 2 seconds.
* When you turn Safe Mode back on (you can no longer configure), the controller freezes for 4 seconds to distinguish. You can also just unplug and plug the controller back in to ensure that you are back in Safe Mode.
* If either L or R digital is active, this command will not work (to prevent safe mode toggling when doing PM salty runback).

# Display Software Version - AZ + Du

* The C-Stick will display the software version in Melee units as if it were not preceded by the "0."
  * The Y-axis will show the tens and ones digits. In this case, it would be 29.
  * The X-axis will show the thousands and hundreds digits. In this case, it would be 0.
* You must use Smashscope to see this numerically.
* If the controller doesn't show 29, then you need to reference an older configuration document [here](LEGACY.md).
  * If it doesn't respond to this command at all, then it's likely the version is 0.23 or lower and you should [upgrade the controller firmware](/For_Users/Phob_Programming_Guide.md).

# Controller Reset - Hold ABZ then press Start

* **Use this if you are upgrading from an older software version or have messed up your settings in some way.**
* **You need to turn off Safe Mode in order to reset.**
* This will reset all the controller settings except for stick calibration. This includes snapback filtering, waveshaping, analog delay, offsets, and button remapping.
* There is a hidden hard reset option that will also erase the stick calibration, but we are not publishing the button combination because it's unhelpful almost all of the time. Ask the devs in the Discord what it is if you really need this.

# Toggle Auto-Initialize - AXYZ

* When you turn this on, both sticks will point up and to the right. When you turn it off, both sticks will point down and to the left.
* If you are positive that both of your sticks are calibrated well, you can use this to avoid the need to press B when plugging the controller in.
* If calibration ever gets wonky, you need to disable this, then recalibrate.
* This automatically gets turned off when you:
  * Recalibrate: if you mess up the calibration then the controller won't initialize correctly and it'll be hard to calibrate properly
  * Reset: if you reset it returns everything to defaults including this setting.

# Rumble Strength Configuration - AB + Du/Dd

* Rumble is only available on boards version 1.2 or later. This command will do nothing for earlier boards.
* Press **AB** + **D-pad Up/Down** to increase or decrease the rumble strength.
* There are settings from 0-11.
  * 9 is roughly equivalent to an OEM controller's rumble.
  * 0 turns off rumble entirely.
* Press **AB+Start** to show the current rumble setting on the C-Stick.

# Tournament Toggle Configuration - Z + Start

* Tournament Toggle reduces the chance of misinputs of either Start or D-Pad Up (taunt) during gameplay.
* Press **Z** + **Start** to switch to the next mode. The mode will be shown on the C-Stick.
* There are 6 different modes, ranging from 1 to 6.
  * Mode 1: Default behavior: both buttons respond immediately.
  * Mode 2: D-Pad Up must be held for 1.5 seconds to activate.
  * Mode 3: D-Pad Up is disabled entirely.
  * Mode 4: Start must be held for 1.5 seconds to activate.
  * Mode 5: Start and D-Pad Up both must be held for 1.5 seconds to activate.
  * Mode 6: D-Pad Up is disabled entirely and Start must be held for 1.5 seconds to activate.

# Analog Stick Calibration - AXY+L

[Basic PhobGCC Analog Stick Calibration - YouTube](https://www.youtube.com/watch?v=rkgtqwIE8Iw)

[PhobGCC Analog Stick Calibration Guide - YouTube](https://www.youtube.com/watch?v=nUbpmkcleF8)

[PhobGCC Notch Calibration Guide - YouTube](https://youtu.be/hscmtzy7dqs)

**NOTE: If using Dolphin Smashscope, you MUST disable all Wii Remotes**

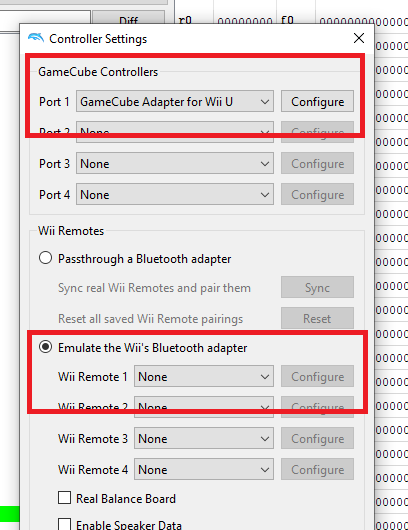
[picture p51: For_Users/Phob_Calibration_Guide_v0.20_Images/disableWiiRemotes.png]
DISABLE_WII_REMOTES


* Stick calibration has two phases: measurement and notch adjustment.
  * During the Measurement Phase, you have the controller record the physical location of the corners of the gate and any modder-added notches.
  * During the Notch Adjustment Phase, you can tweak the output angles of the notches you measured.
  * You **must** complete both measurement and notch adjustment for the setting to be saved.
* If you’ve already calibrated the stick and just want to adjust notches you have already measured, you can skip the measurement phase and immediately begin notch adjustment by pressing Start at any time during the measurement phase.
* Calibrating either stick turns off Auto-Initialize.

## Measurement Phase

The first phase involves having the controller record the positions of the physical gate corners and notches as calibration reference points.

When in the measurement phase, the C-Stick's output will alternate between the center and a position along the rim, starting with the cardinal directions.

The C-Stick's output shows what notch, if present, you are to measure.

The control stick output will show the output of the previous calibration. Depending on the previous calibration, this may be accurate, inaccurate, freak out randomly, or in the case of an uncalibrated PhobGCC 2.0, it will be mostly pegged to (125,125). The output you see here has no bearing on the results.

* If the C-Stick is centered, let go of the control stick and press either **L**, **R**, or **A** to measure that position.
* If the C-Stick is not centered, **hold the physical analog stick into the notch indicated by the C-Stick's output** and press **L**, **R**, or **A** to measure that position.
  * Make sure to enter the notch from the direction you would during gameplay.
* If you don't have a notch at the position indicated by the C-Stick, **let go of the stick** and press **L**, **R**, or **A**.
* **You must measure all four cardinal directions (East, North, West, South) and all four diagonal directions** or calibration will not work.
* The first time you calibrate a controller that has modder-added notches, it is highly recommended to skip all the modder added notches and start with only the 8 primary directions.
* If you think you messed up a measurement, you can go back to a previous notch measurement by pressing **Z**. It'll go back to measuring the center immediately before a given notch.
* Once you finish measuring all the notches (32 presses of **L/R/A**), the stick should behave normally. **You are not done calibrating.** Proceed to the [Notch Adjustment Phase](#notch-adjustment-phase) below.
  * If it does not behave as expected, see Measurement Phase Troubleshooting below.

### Measurement Phase Troubleshooting

* If the Analog Stick's output is not accurate during this phase, do not worry. The previous calibration does not matter.
* If the C-Stick is not alternating between being centered and circling all the way around the rim, and you are using Dolphin to calibrate, you need to reinitialize Dolphin by making sure that Auto-Initialize is off, unplugging and replugging, restarting Dolphin, and then tapping **B**.
* If after the measurement phase is done, the stick has one or two sectors that jump into another quadrant randomly, you probably mis-measured a notch. Mash **L**, **R**, or **A** a bunch to finish the calibration and start again.
* If after the measurement phase is done, the stick output is completely haywire and jumping all over the place randomly, you may have let go of the stick before pressing **L**, **R**, or **A**. Mash **L**, **R**, or **A** a bunch to finish the calibration and start again.
  * Alternatively, if you have Firefox notches, try calibrating the main 8 directions only to completion, then go back and calibrate all of them.
* If after the measurement phase is done, the stick output is backwards on one or both axes, you probably were trying to make the stick *output* match the C-Stick, instead of moving the *physical* stick into the notch indicated by the C-Stick. Mash **L**, **R**, or **A** a bunch to finish the calibration and start again.

## Notch Adjustment Phase

After the measurements are complete, this phase lets you adjust exactly where the non-cardinal notches are mapped to.

When in the notch adjustment phase, the C-Stick will stay along the rim and rotate along from notch to notch, starting with the diagonals.

This indicates which notch is currently being adjusted.

* The Analog Stick position does not affect notch adjustment. The output is a live preview of how the calibration will be with your given adjustments.
* The C-Stick points at the notch that is currently up for adjustment.
* Press **X** or **Y** to shift the output of the notch clockwise or counterclockwise, respectively.
  * You won't see anything change if you don't put the stick into the notch that's being adjusted.
  * Make sure to enter the notch from the same direction you would during gameplay when checking the output.
* To reset to an undistorted position for the notch, press **B**. The C-Stick will be displaying the position that was measured.
* Press **L**, **R**, or **A** to move to the next notch.
* To go back to a previous notch, press **Z**. You cannot go back to the measurement phase.

When the C-Stick's output returns to center, the stick calibration is now saved.

### Notch Adjustment Troubleshooting

* If your notch coordinates are very inconsistent, try twisting the stick like a knob and see if the origin value shifts. If so, try gently tightening the screws holding the stickbox down; they may be loose.
* If your notch coordinates have slightly different values when approaching straight from center compared to rolling clockwise or counterclockwise along the rim, this is normal (within two or three values).
* If your notch coordinates cannot be adjusted to the desired value, check the C-Stick's coordinates to see if it's too far from the desired value. You can try recalibrating from the start and measuring it again, but it may not help. See a modder to get your notches adjusted if needed.

# C-Stick Calibration - AXY+R

This process is exactly like Analog Stick Calibration, but instead, the Analog Stick moves to show you how to move the C-Stick.
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

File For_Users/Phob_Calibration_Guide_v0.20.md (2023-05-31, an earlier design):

**THIS IS LEGACY FIRMWARE! PLEASE UPDATE TO THE [LATEST!](/For_Users/Phob_Calibration_Guide_v0.28.md)**

**NOTE: This is for firmware version 0.20.**

For later development versions of the software that have not yet been released, search for “Current Commands List” in the PhobGCC.ino file to see the commands for that version as they may have changed.

**NOTE 2: The controller starts in safe mode! To make any changes you must disable it first!**

I strongly recommend using Smashscope (either on a Wii or Dolphin) for all of this.
An alternative is Uncle Punch Training Mode 3.0. In the Training Lab menu, under General enable “Input Display”, and under Info Display enable “System LStick”, “System CStick”, and “System Trigger” as the first three rows.

# Activating the Analog Sticks - B

* After plugging in the controller, press B to activate the analog sticks.
* If you are playing using Dolphin/Slippi, YOU MUST POWER CYCLE (unplug and plug back in) YOUR CONTROLLER EVERY TIME BEFORE YOU START SMASH, then press B once smash is running.
  * If you are using a Mayflash adapter, you must plug in both USB connectors for the controller to register in Dolphin/Slippi.
* If you do not do this your calibration may be off and you may not get 1.0 dashes.
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

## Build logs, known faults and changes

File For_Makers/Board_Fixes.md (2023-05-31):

# Board Fixes

This is a document with illustrations that show you suggested fixes for some issues seen on PhobGCC Boards

Please ask in the [PhobGCC Discord Server](https://discord.gg/yrpUu7mgzm) if you have any questions.  

## Full Duplex - PhobGCC v1.0/1.1

Bridge the third and fourth pins on the top left of the Teensy 3.2/Teensy 4.0 (as seen below) and flash the proper Diode_Short version of the firmware.

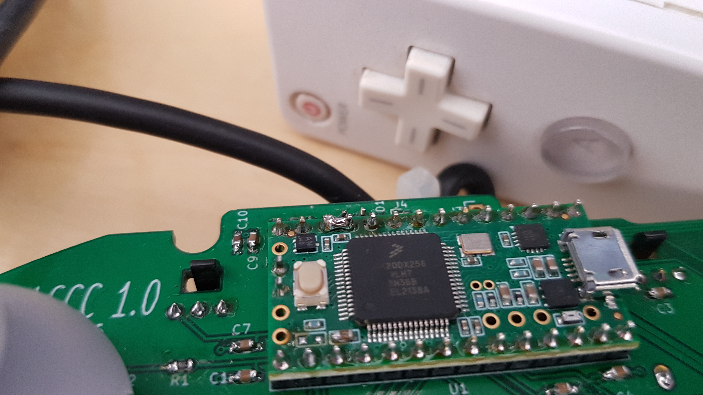
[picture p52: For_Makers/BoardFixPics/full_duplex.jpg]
Full Duplex Picture


## L-stick Hall Sensor Joints - PhobGCC v1.X

Due to the reversed orientation of the left stickbox on PhobGCC v1.Xs, the left trigger guard applies significant pressure to the hall effect sensor joints.
This can deform the solder joints if leaded solder, which is soft, was used.

The way to do them right is to cut the pins flush and reflow them per [the build guide](/For_Makers/Build_Guide_1.2.md#bending-and-soldering-hall-sensors).

There are 3 other fixes that resolve the issue.

Temporarily - unscrew the shell screws by 3/4s of a turn.

Unscrew the following screws 3/4s of a turn so that it takes off the pressure on the hall sensor joints.

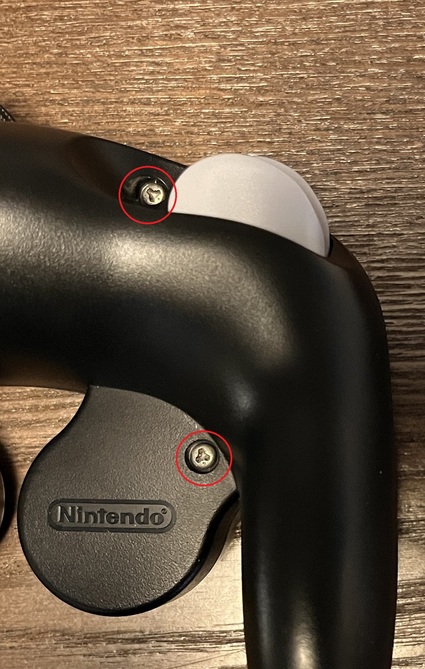
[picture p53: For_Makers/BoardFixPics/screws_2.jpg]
Shell Screws


Filing - File down the trigger guard at the circled points.

Take out the two black screws holding it in place and remove the trigger guard. Proceed to file down the left trigger guard in the circled locations below to ensure that the joints are not being stressed.

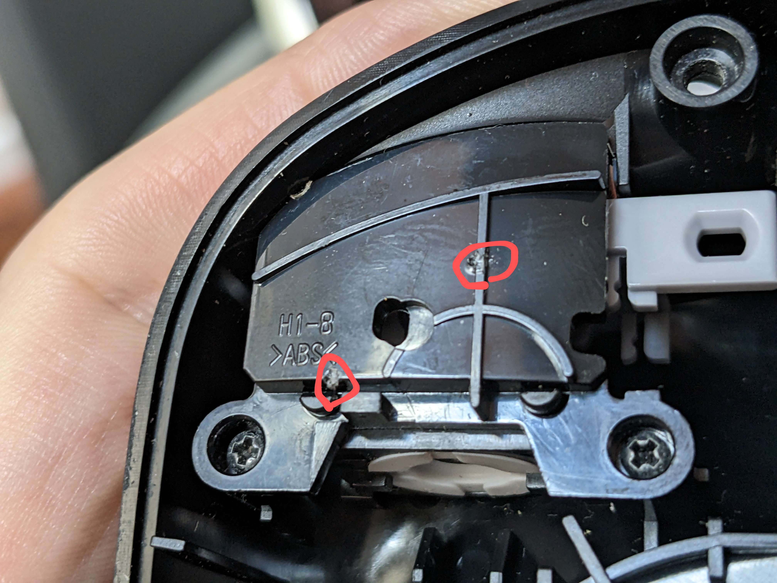
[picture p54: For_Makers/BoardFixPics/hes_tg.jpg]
Trimmed TG HES


3D Print - Either 3D print yourself or order the 3D printed bracket from a service such as JLC and swap it out.

[1.X Trigger Guard STL](https://drive.google.com/file/d/1QfcjQfTboTi3LeGjDCiVci9mYGINXsB6/view?usp=sharing)

## L-Stick Interference with L-slider - PhobGCC v1.X

As a result of the hall effect sensor placement, the analog stick is positioned upside down. This causes the notch in the skirt of the analog stick to not line up with the solder joint of the analog slider.
There are 3 fixes that resolve the issue.

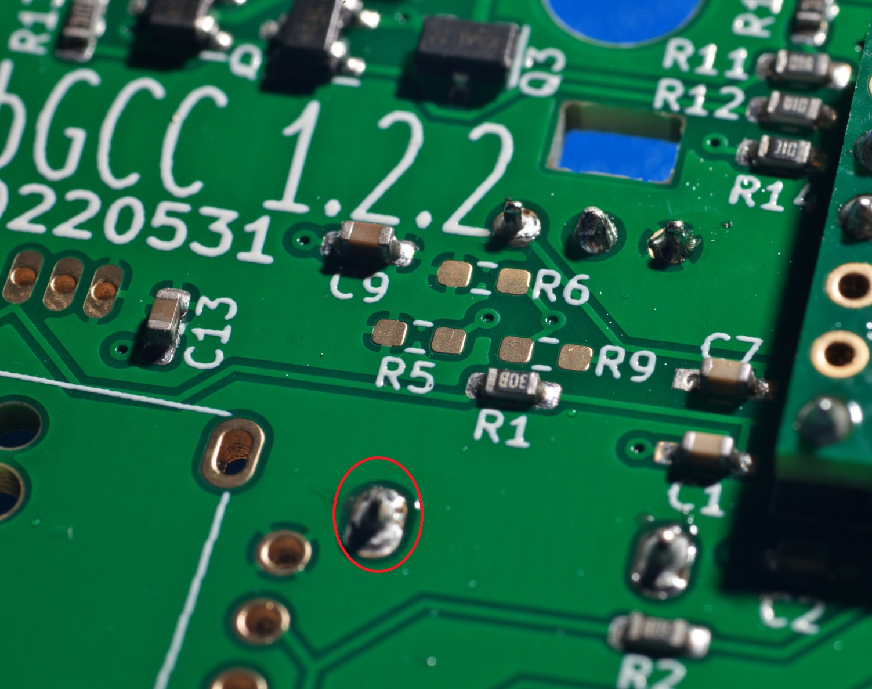
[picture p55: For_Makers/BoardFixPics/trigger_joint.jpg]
Trigger Joint


During Assembly - Trim the pin flush with the hole and only add a little solder so that the solder wets into the hole. This should result in a flat board on top where it does not interfere with the analog stick.

After Assembly - trim the pin flush and reflow the solder so that it wets into the hole.

Cutting - Trim the skirt as the other side of the stick so that it does not interfere with the solder joint of the analog slider. You want to replicate the cut-out that is already on the other side of the analog stick.

## L-trigger JST Interference - PhobGCC v2.0.2

The placement of the L trigger holes on PhobGCC 2.0.2 is too high and interferes with the L trigger guard when installing a JST header.
There are 3 fixes that resolve the issue:

Filing - File down the trigger guard at the bottom of the left screw post so that it is flush with the hole as shown below. You only need to remove 0.25mm of material.

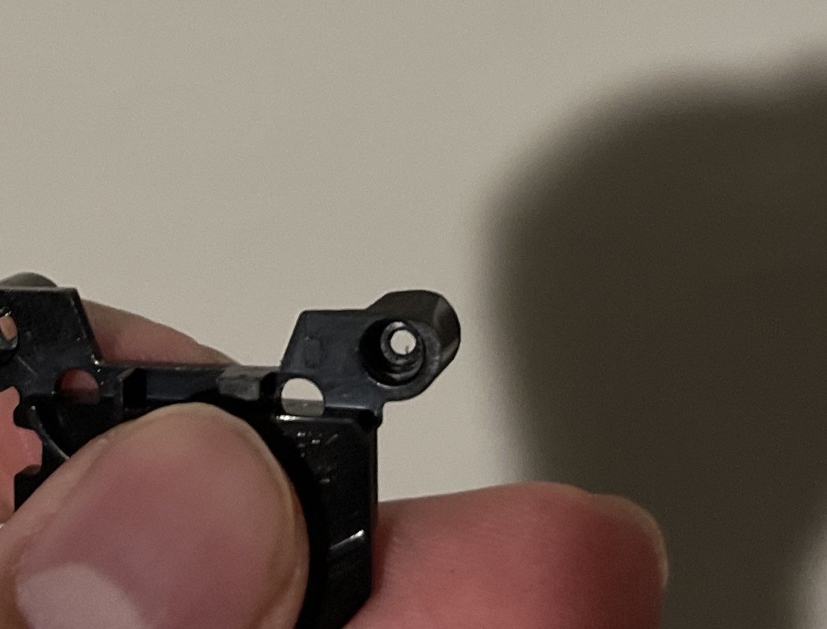
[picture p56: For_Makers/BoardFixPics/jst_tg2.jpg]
Trimmed TG JST


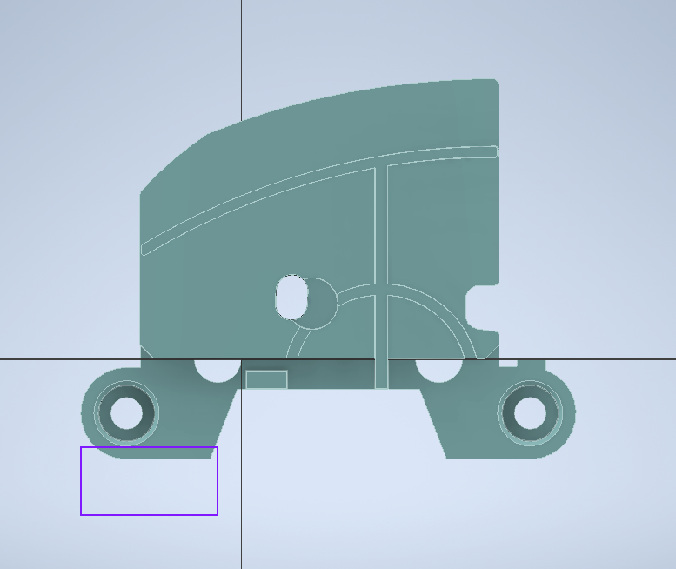
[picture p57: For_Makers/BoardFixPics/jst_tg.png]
INVENTOR EXAMPLE JST TG


3D Print - Either 3D print yourself or order the 3D printed bracket from a service such as JLC and swap it out.

[2.0.2 Trigger Guard STL](https://drive.google.com/file/d/1NZwtrHezeiQHAMoeLFhVF65OYEvfT3iO/view?usp=share_link)

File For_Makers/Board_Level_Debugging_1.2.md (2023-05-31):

# Board Level Debugging

This is a document with illustrations that show you what a PhobGCC 1.2 board should look like fully assembled, with annotations that will help you debug electrical issues when assembling.

You will need a multimeter that can read voltages and resistances to make the most of this guide.

# Physical Aspects to Check

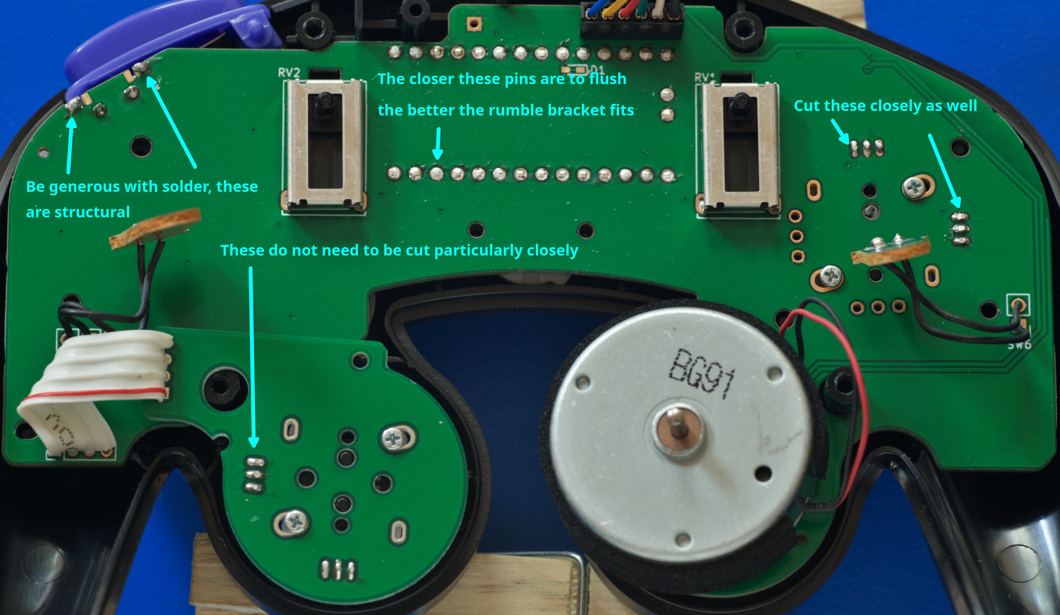
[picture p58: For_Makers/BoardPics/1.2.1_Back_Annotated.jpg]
Back of board with annotations


* On the Z-button, be very generous with solder on the legs that are on the edge of the board. These solder joints are structural, helping keep the button from breaking off when you mash grab (or Z-jump).
* The pins behind the Teensy must be flush as possible. The closer they are to completely flat with the board, the flatter the rumble bracket fits. If they protrude, the rumble bracket will always try to pop out.
* The Hall effect sensors for the Analog stick need to have their leads trimmed fairly closely to the board, though they don't have to be completely flush. If you don't, they press into the trigger guards, the plastic parts that are screwed down over the triggers. This makes it difficult to close the controller shell.
* The Hall effect sensors on the C-stick board do not have to be trimmed particularly closely.

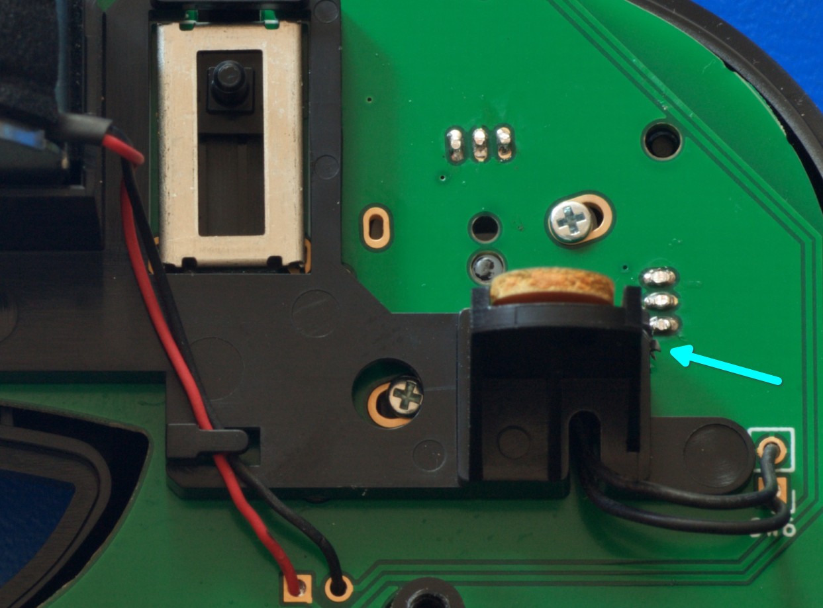
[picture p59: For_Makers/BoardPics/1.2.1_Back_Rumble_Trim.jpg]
Back of analog stick


* The rumble bracket has a loop here that needs to be trimmed off to allow the bracket to lay flat easily.

# Resistances to Check Before Plugging In

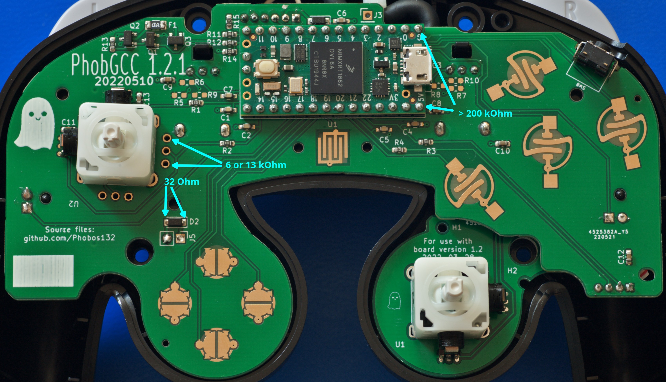
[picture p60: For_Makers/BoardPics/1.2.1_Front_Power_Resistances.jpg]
Power-off resistances


* Check these resistances before ever plugging in the controller to ensure that there are no short-circuits.
* The 32 Ohm one will be different if you don't have an OEM rumble motor.
* 6 or 13 kOhm corresponds to the 3.3 volt power plane, which supplies all the analog sensors on the board. Depending on which polarity you measure (which side red and black multimeter leads are on), you will get these two values. If it's significantly lower than this, then there's a short that you will have to find.
  * The short may be on the Hall Effect sensor pads, the trigger slider pads, or on the two lone pins at the end of the Teensy.
* \> 200 kOhm corresponds to the 5V supply for the Teensy. On my multimeter, it is much greater than this (several MOhms) in one direction and somewhere above 200 kOhms in the other. Other multimeters may measure something else; I have seen reports of around 50 kOhm, and this is not a problem. However, if it's too much below that, there might be an issue.
* If you have a short, go to the PhobGCC Discord for tech support, and explain what you found to be wrong. You will need to resolve these before it's safe to plug in the controller.

If the Teensy doesn't respond when plugged into a computer via USB, the likely culprits are either shorts between 3.3v and ground, or between 3.3v and the signal pins.
Check the Hall sensor pads, which are the most prone to shorts.

# Voltages to Check When Plugged In

If your controller is not functioning correctly, open the shell and plug it into a powered-on Gamecube, Wii, or GCC adapter (e.g. on PC with Dolphin open) to supply power, then check these voltages:

## Supply Voltages

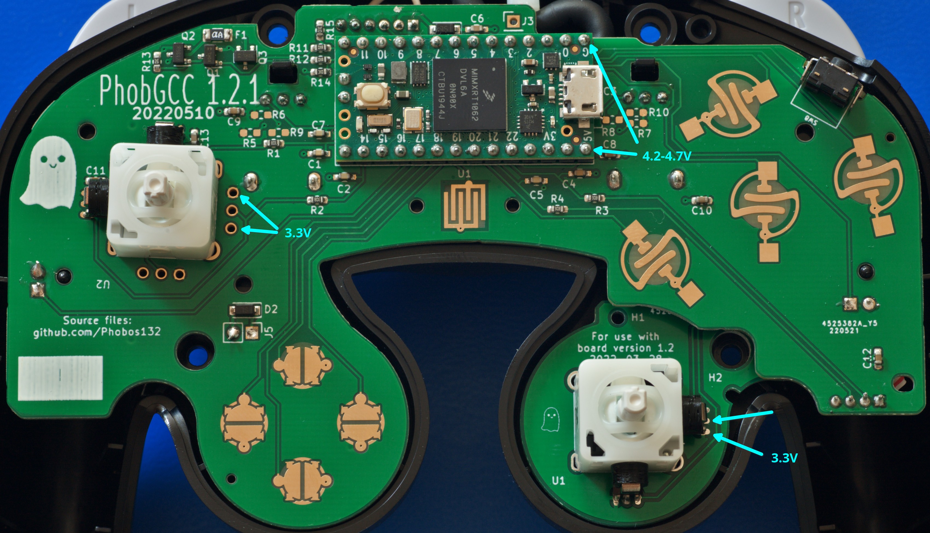
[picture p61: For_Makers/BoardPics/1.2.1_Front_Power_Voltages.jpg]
Power-on supply voltages


* These are the supply voltages for the various parts on the controller.
* 4.2-4.7V is the supply for the Teensy. This may vary depending on what the controller is plugged into and what the Teensy's clock speed is set to.
  * On my official Nintendo adapter with the Teensy at 600 MHz, this is 4.2V.
  * On my Wii with the Teensy at 600 MHz, this is 4.7V.
  * With the Teensy at 600 MHz, adding an extender cuts this by 0.3V until the point where the Teensy no longer operates.
  * With the Teensy at lower frequencies, this voltage may be higher.
* 3.3V next to the Analog stick is the supply voltage for all the analog sensors. If this is too low, then you have a short somewhere or a bad component.
* 3.3V next to the C-stick should be exactly the same, but since this is connected via a cable it's important to check it.

## Output Voltages

If you have particular analog sensors (Analog stick, C-stick, or triggers) that are acting up, check the following voltages to compare:

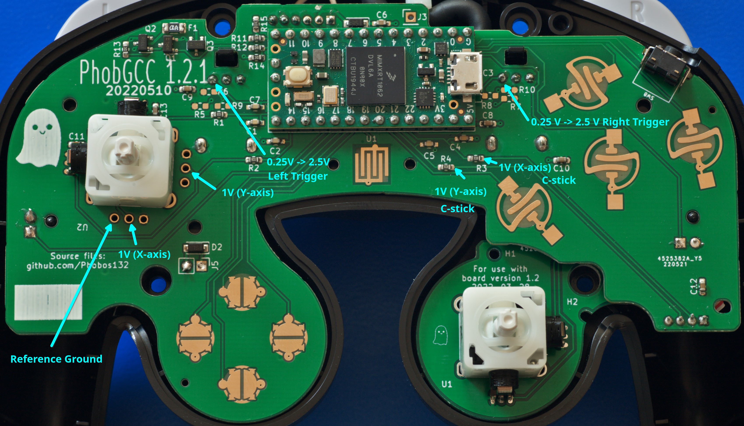
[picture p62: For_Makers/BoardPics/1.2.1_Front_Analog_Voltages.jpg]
Sensor output voltages


* Put the black lead of your multimeter where Reference Ground indicates and the red lead on the indicated test points.
* All the 1V values are outputs of the Hall effect sensors.
  * These should vary depending on the stick position in the axis indicated.
  * With DH1H1 magnets and mid-placed DRV5053CA or DRV5053PA sensors, the values should change by around +/- 0.2V.
  * With DH1H1 magnets and mid-placed DRV5053EA or DRV5053RA sensors, the values should change by around +/- 0.4V.
  * If the sensors are placed lower to the board, the change should be less.
  * If your values are consistently very low or very high, your magnets may be mounted 90 degrees off. They must be horizontal.
* The trigger values should be very roughly 0.25V for a fully extended trigger, and when the trigger is fully depressed they should reach 2.5V.
  * If you leave the spring out, then they will start out higher.
  * If you use trigger plugs, they likely won't reach 2.5V.

If something seems off, go to the PhobGCC Discord for tech support, and explain what you found to be wrong.


This work is licensed under a [Creative Commons Attribution-ShareAlike 4.0 International License](http://creativecommons.org/licenses/by-sa/4.0/).

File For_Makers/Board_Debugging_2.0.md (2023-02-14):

# Sticks Inoperable

If both sticks are nonfunctional and stuck in one corner, check for shorts between C-stick wires.
Shorting these can prevent communication with both ADCs at the same time.

If only the C-Stick is inoperable, it's likely a bad connection without a short.

# Won't Connect to Console

Check if the PhobVision voltage is nonzero.
If it is, the Z button may be stuck closed and forcing the controller into PhobVision mode. 


This work is licensed under a [Creative Commons Attribution-ShareAlike 4.0 International License](http://creativecommons.org/licenses/by-sa/4.0/).

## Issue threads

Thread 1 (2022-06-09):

Board level troubleshooting

CarVac, 2022-06-09:
For each button and axis, where should you test continuity?

For analog, where should you check voltages? Expecteded resistance to ground and +3.3 in case of shorts

3.3v to zero expected resistance, check voltage too

Cable pin to pin (check for shorts)

CarVac, 2022-06-10:
Done

Closed 2022-06-10.

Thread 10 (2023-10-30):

I can't calibrate C-STICK

diclonius, 2023-10-30:
Hello, I have been looking for a solution for a few weeks, and the C-STICK does not move, it always remains in the upper right corner, before and after calibrating, I was able to successfully calibrate the analog stick, but the C-STICK always has the same result.

Change the welds, change the part, I don't know what else it could be, any ideas?

CarVac, 2023-10-30:
The c-stick cable or ADC has poor connection.

diclonius, 2023-10-30:
I changed the cable for a new one, because I thought that was it.
Regarding the ADC, I don't know what you mean.

El lun, 30 oct 2023 a las 7:57, CarVac ***@***.***>)
escribió:

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

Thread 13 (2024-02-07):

Use USB Type C instead of micro B

SylveonDeko, 2024-02-07:
We've all seen the issues with micro usb and how it degrades really fast, so why not use usb c instead of micro? Is it a limitation of the raspi?

CarVac, 2024-02-07:
1. This is the documentation repository, not the hardware v2 repository
2. We may do that for 2.0.6 (or whatever version ends up releasing after we fix teething issues) since we have switched to Elecrow as the main recommended board house.

We did micro in the first place because JLC has had a poor track record with USB-C.

SylveonDeko, 2024-02-07:
Got it thanks!

Closed 2024-02-07.

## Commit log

2022-06-05 Add calibration guide
2022-06-07 add images to repo, add hall sensors
2022-06-08 add snapback filter explanation
2022-06-10 Update configuration doc for 0.21
    Also add pics for board-level debugging
2022-06-10 Add board level debugging doc
2022-06-10 escape a greater than sign in board debugging
2022-06-11 Clarify the reason for trimming hall leads
2022-06-13 add c-stick board clarification
2022-06-13 add 1.1 teensy 4 clarification to buying guide
2022-06-15 clarify 200kOhm on board debugging doc
2022-06-16 clarify hall output voltage error state
2022-06-20 finish hall soldering section
2022-06-21 reword trigger paddle wire stuff
2022-06-21 edit mouse button parts description
2022-07-01 add soldering tutorial
2022-07-01 fix typo in soldering tutorial
2022-07-01 clarify why to not touch solder to iron tip
2022-07-10 add hall soldering video link, update cal guide
2022-07-11 Clarify how filter settings are displayed
2022-07-13 Reword new solderer advice at beginning
2022-07-17 begin 0.23 calibration guide
2022-07-21 Say to use thin superglue on magnet holders.
2022-07-23 Mention plugging both connectors for Mayflash adapter
2022-08-09 Clarify stick calibration with uncalibrated sticks
2022-08-22 clarify stick filter display wording
2022-09-01 note what shorts can cause a dead teensy
2022-10-03 Arduino IDE 2.0 Phob Programming Guide
2022-10-11 correct mouse button vs dpad button links
2022-10-11 emphasize holding the stick when calibrating
2022-10-14 switch from numbering to bulleting
2022-10-20 adding disable wii remotes to calibration
2022-12-17 Phob2 Ordering Edits
    [Magnet_Holder_Underslung.scad]
2022-12-17 Phob2 Ordering Guide Edits 2
    [Magnet_Holder_Underslung.scad]
2022-12-17 add JST pigtail & connector to phob2 order guide
2022-12-17 add video cable to ordering guide
2022-12-17 specify substitutions for jst connector
2022-12-19 adding extra rumble bracket
2022-12-20 add EU option for magnets
2022-12-20 phob2 eu magnets
2022-12-21 phob2 canadian magnet option
2022-12-21 phob1 ordering guide canadian magnets
2022-12-22 phob2 board ordering guide rev1
2022-12-22 Phob2 board ordering guide rev2
2022-12-22 magnet mount guide v1
2022-12-22 magnet mount v2
2022-12-22 remove uses for different magnets from phob2
2022-12-22 add canada and eu magnets
2022-12-22 Phob2 ordering guide adding Etsy to magnet mounts
2022-12-22 Mouse Button number
2022-12-22 phob2 selecting PCBA type circled
2022-12-23 Magnet Confirm
2023-01-04 switch to unannotated drill image
2023-01-04 Again…
2023-01-05 note about downloading the latest bom
2023-01-09 updating to A3 sensors
2023-01-12 add oem c-stick cable to no-buy list
2023-01-21 tell them to leave jst connector in receptacle
2023-01-24 add mcmaster link for wire
    and change solid wire rec to 30 gauge
2023-02-04 Add note for hall sensor solder smushing
2023-02-08 remove solid core wire option from wire
2023-02-13 tweak board_fixes
2023-02-21 board_fixes v3
2023-03-05 board fixes v4
2023-03-05 board_fixes v5
2023-03-05 board_fixes v6
2023-03-05 Create 1.X Trigger Guards.STL
    [1.X Trigger Guards.STL]
2023-03-05 typo fixes in board fix doc
2023-03-05 adding board fixes to readme
2023-03-05 board fixes v7
2023-03-05 board fixes v8
2023-03-05 board fixes v9
2023-03-05 board fixes v10
2023-03-05 board fixes v11
2023-03-05 board fixes v12
2023-05-05 more explanation for button timing
2023-05-05 Clarify phobvision stuff
    Use proper ledgedrop terminology
    Note that unfiltered data is dotted in value vs time
2023-05-31 adding ribbon cable vendors
2023-07-03 switch to new elecrow guide
2023-09-18 Mention that you can buy single boards
2023-10-30 add better dpad buttons
2025-03-14 add AU magnet option
2026-01-06 More admonishments about magnet installation
2026-02-16 Update BibbEZ switch link
2026-03-06 Update calibration raw sensor output info
2026-04-24 Update Phob2_Ordering_Guide.md magnets again
2026-10-25 magnetization orientation
2026-10-28 Add Mexican magnets

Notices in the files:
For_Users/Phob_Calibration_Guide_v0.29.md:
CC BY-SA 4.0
